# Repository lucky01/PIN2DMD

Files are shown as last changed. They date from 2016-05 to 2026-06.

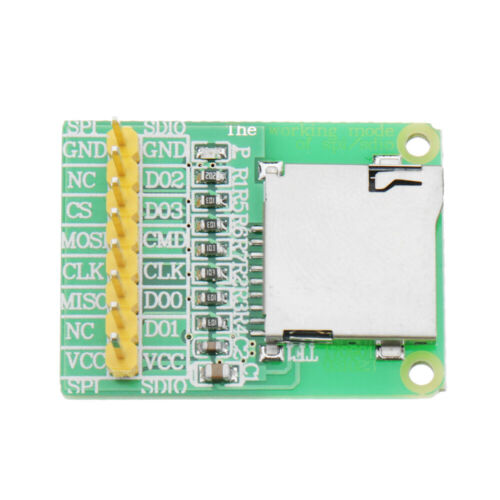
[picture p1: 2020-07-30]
hardware/V4 NUCLEO-144/chinese SD reader/sd_reader.jpg

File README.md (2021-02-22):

# PIN2DMD - a color LED dotmatrix controller for virtual and real pinballs

With the PIN2DMD project you get a full color LED DMD controller 
for real and virtual pinball machines.
The project was started by Lucky1 and shortly after that joined by Steve45 
as co-author. Version 1.X is free for DIY private NON COMMERCIAL use and released under 
a Creative Commons Attribution-NonCommercial- ShareAlike 4.0 International License.

http://creativecommons.org/licenses/by-nc-sa/4.0/

Due to copyright violations through commercial sales of our software the authors were forced to
change the project to allow access to the source code for contributors only with version 2.0.
Also a activation key which is bound to the hardware was introduced.
More Information how to obtain a key can be found in chapter 3 here https://pin2dmd.com/installation/ 

The latest binary can be found here 
https://github.com/lucky01/PIN2DMD/raw/master/firmware/latest/

Sorry for inconvinience, but is seems that the hunt for quick money eats the brain of the hunter.

More information can be found on https://pin2dmd.com/

It currently supports:

- WPC/WPC95 real pinball input
- Stern SAM real pinball input
- Stern Whitestar real pinball input
- Stern Spike real pinball input
- DataEast/Sega real pinball input
- Gottlieb real pinball input
- Capcom real pinball input
- AlvinG real pinball input
- Spooky real pinball input (with full color support from herg for AMH http://ledocd.com/amh_color/)
- Inder / SPinball real pinball input
- Sleic / Petaco real pinball input
- HomePin real pinball input
- Sega 192x64 using 64x64 1/32scan P2 Panels
- DataEast 128x16 real pinball input
- Mission Pinball Factory and P-ROC USB input
- Visual Pinball / PinMame USB input
- Future Pinball with DMD interceptor DLL
- Unit3d Pinball
- Ultra DMD support (Stephen)
- PinballX / XDMD support (Tom Speirs)
- Pinball fx2 support using dmdext from Freezy
- The Pinball Arcade support using dmdext from Freezy and NoEx
- Pinball Browser / SmartDMD color switching for full color Stern ROMS
- Frame colorization with PIN2DMD Editor by Steve for all pinball machines
- WCID Windows automated driver installation

The components cost approximately 120$
Here is a list of what you need:
 
#1. The Panels
The panels we use are sold for video walls and advertising signs. There are many 
sizes of panels available with different spacing between the LEDs. The ones 
that fit best into a pinball have 2.5mm spacing (also referred to as P2.5), 
which results in a 128×32 display of 320×76.8mm. This can be mounted into an 
existing DMD/speaker panel from a pinball cabinet. Currently the only place 
to buy these panels is from AliExpress. search for "RGB LED 64x64 p2.5 1/16" or 
"RGB LED 64x64 p2.5 1/16". You don´t find 128×32 panels, but you can buy two 
64×32 or one 64x64 panel which consists of two 64x32 panels which can be removed 
from the frame and connect side-by-side. Make sure that you end up with 2 x 1/16 
scan panels since these are the only one currently supported by PIN2DMD. 
The good thing is that they are seamless.

#2. The Controller

#2.1 The STM32 Nucleo board with PIN2DMD Shield or EVO boards

The panels use a 16 pin Hub75 interface to be connected to the next panel or to a 
controller. We use standard STM32 development boards like the Nucleo144-F429ZI or NUCLEO-F439ZI
which are available from multiple sources for about $20 or custom EVO boards.
The proceesor is based on a ARM Cortex processor architecture which is needed 
for the rapid bit-shifting of data to control the panels. We write the program in C/C++. 
The software is uploaded to the controller through USB port.
To connect the displays to the controller there is a HUB75 connector, which 
basically just connects the pins to the 16-pin ribbon cable that drives the displays. 
The board also has a 14pin connector which is used as input to get the data from a real machine. 
PCB layout examples can be found in the hardware directory. 

#3. The Power Supply
The RGB LED displays require 5vdc for power and if you want to run them
with full brightness they need a lot of current. A 10A power should be enough.
You need to connect that power supply up to both panels. The controller can 
either be supplied by USB or by an external 5V power source
 
#4. The Firmware
Installation is done using ST-Link interface

1) Download and install ST Link Utility: http://www.st.com/web/en/catalog/tools/PF258168
2) The latest binary can be found here https://github.com/lucky01/PIN2DMD/raw/master/firmware/latest/
3) Connect the STM32 board to the PC using a mini-USB cable (not the smaller microUSB cable). The board will light up and you should an STM32 STLink USB device connected in the Windows notification tray
4) Flash firmware: Target -> Program 
Choose PIN2DMD.BIN file from firmware/latest latest folder.

#5. The pin2dmd.exe tool
The tool is used to configure the controller und upload needed data for the pinball
used. It can either run in commandline mode or in GUI mode.

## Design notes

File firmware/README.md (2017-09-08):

# PIN2DMD

For information how to get a activation key for your device 
please visit http://www.pin2dmd.com

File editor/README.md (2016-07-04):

# PIN2DMD Editor by Steve

Can be used for editing frames and palettes and 
creating the needed palettes.dat file to upload
to pin2dmd using pin2dmd.exe tool with /b option.

Compiled version and and docs can be found here
http://pin2dmd.com/

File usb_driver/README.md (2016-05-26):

# PIN2DMD USB driver

The PIN2DMD is registered automatically in windows as a winusb device. 
For Visual PinMame etc please use Zadig Utility to change the drivertype 
to "libusb-win32". For Windows XP Version please go to http://zadig.akeo.ie/

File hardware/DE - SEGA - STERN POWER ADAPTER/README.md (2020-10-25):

# DATAEAST POWER ADAPTER BOARD

This are the PCB files for a power adapter which can be plugged in the powerdriver board of DE version 3 / Sega version 3 & Whitestar / Stern Whitestar & S.A.M.
machines. PCB design by Rene Venema

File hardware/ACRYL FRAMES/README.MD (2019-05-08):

Templates for acrylic mounting frames. Please check against your LED panels before ordering.

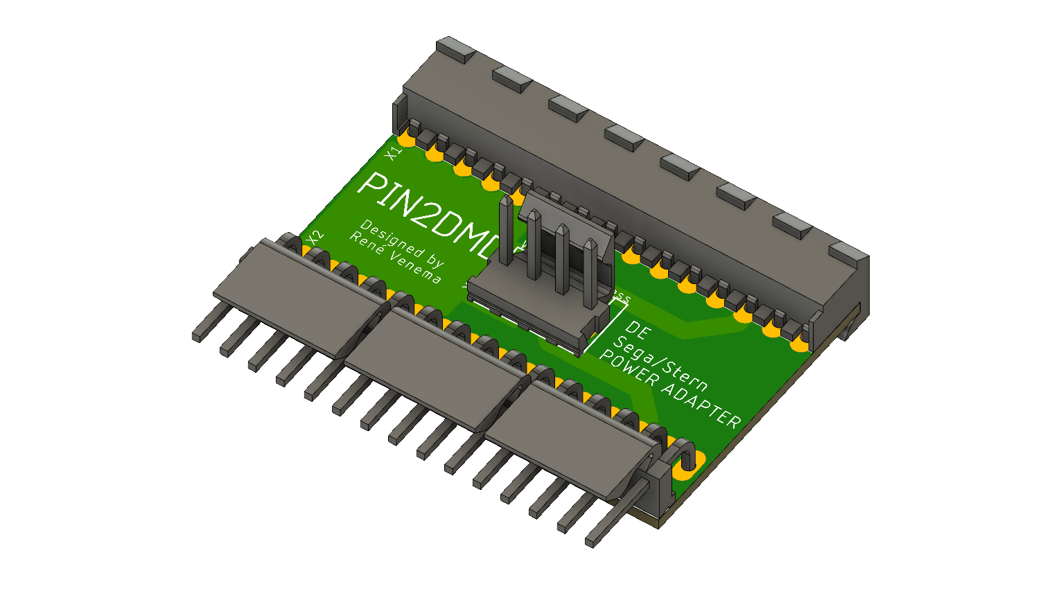
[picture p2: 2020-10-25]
hardware/DE - SEGA - STERN POWER ADAPTER/DataEastconverterv8.png

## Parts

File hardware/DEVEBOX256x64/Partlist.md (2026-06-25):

# PIN2DMD HD DEVEBOX HD Shield partlist

DEVEBOX STM32H743VIT6 Shield:

- 1 x DEVEBOX STM32H743VIT6
- 2 x Pinheader 2x22 pins female double row 2.54mm
- 1 x Pinheader 2x20 pins female double row 2.54mm (MMI)
- 3 x IC socket 20pin
- 8 x 47pf
- 1 x 1kOhm
- 2 x 100kOhm
- 2 x Resistor network 4R 8-pin 220Ohm
- 1 x 74LS123 DIP
- 3 x 74HCT245N DIP
- 2 x IC socket 16pin
- 1 x IDC socket 2x7 pins male 2.54mm
- 2 x IDC socket 2x8 pins male 2.54mm
- 2 x Tactile push button 6x6x10mm 4pin DIP
- 8 x 100nF

POWER:

- 1 x XL4015 module or XL4005 module set to 4.8V 
- 1 x Screw terminal block 2pin 5mm (8-36VDC in)
- 1 x CH3.96 china or Molex 4P KK3.96 model: 09652048

LED:

- 1 x LED 3mm green
- 1 x 470 Ohm
- 1 x LED 3mm blue
- 1 x LED 3mm orange
- 1 x LED 3mm red
- 3 x 680 Ohm

RS232:

- 1 x MAX232 DIP
- 1 x Pinheader 1x3 pins male 2.54mm RS232
- 1 x Pinheader 1x2 pins male 2.54mm 3V3_TTL
- 4 x 1uF 4x7mm radial

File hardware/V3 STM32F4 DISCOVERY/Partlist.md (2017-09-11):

#PIN2DMD shield partlist

#V3 STM32F407-DISCOVERY Shield

2 x pinheader 2x25 pins female double row 2.54mm
1 x TINY RTC module
1 x ESP-12 or ESP01 wifi module
1 x Micro SD-card reader module
1 x DHT11

2 x IC socket 16pin
1 x 74LS123 DIP
1 x MAX232 DIP

1 x IDC socket 2x7 pins male 2.54mm
1 x IDC socket 2x8 pins male 2.54mm
3 x pinheader 1x3 pins male 2.54mm

7 x 47pf
4 x 1uF 4x7mm radial
4 x 100nF
1 x 1kOhm
1 x 10kOhm
2 x 100kOhm
1 x 470 Ohm
2 x resistor network 3R 6-pin 220Ohm

1 x LED 3mm
1 x screw terminal block 2pin 5mm
1 x DC power jack 3 legs PCB mount
2 x tactile push button 6x6x10mm 4pin DIP

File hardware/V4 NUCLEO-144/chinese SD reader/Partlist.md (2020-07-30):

#PIN2DMD shield partlist

#V4 Nucleo-144 Shield

2 x pinheader 2x36 pins female double row 2.54mm
1 x china 3.5v/5v micro SD card module SDIO/SPI

2 x IC socket 16pin
1 x 74LS123 DIP
1 x MAX232 DIP

1 x elevated socket 2x8 female 2.54mm
1 x IDC socket 2x7 pins male 2.54mm
1 x IDC socket 2x8 pins male 2.54mm
1 x pinheader 1x3 pins male 2.54mm RS232

8 x 47pf
4 x 1uF 4x7mm radial
3 x 100nF
1 x 1kOhm
1 x 10kOhm
2 x 100kOhm
1 x 470 Ohm
2 x resistor network 4R 8-pin 220Ohm

1 x LED 3mm
1 x screw terminal block 2pin 5mm
2 x tactile push button 6x6x10mm 4pin DIP

optional components

1 x ESP-12
1 x DHT11
1 x HX1838
1 x CR2032 battery holder
1 x pinheader 1x3 pins male 2.54mm PIR

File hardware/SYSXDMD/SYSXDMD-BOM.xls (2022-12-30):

SYSXDMD BOM
NO | Code | Part Number | Manufacturer | Description | Designator | Quantity | Process | Note
1 |  | 430152043826 | Wuerth Electronics | Switch 6x6x5 mm SMD, 4 pins | BTN1,BTN2,DFU,RESET | 4 | SMT | use China manufacturer
2 |  | TAJA105K016RNJ | AVX | Tantalum capacitor, 1uF, 16V, A3216 | C1,C13,C15 | 3 | SMT | use China manufacturer
3 |  | CL21B105KOFNNNE | Samsung | Capacitance, 1uF, 16V, 0805 | C30,C31,C32,C33 | 4 | SMT | use China manufacturer
4 |  | TAJB225K020RNJ | AVX | Tantalum capacitor, 2u2, 20V, 1411 | C11 | 1 | SMT | use China manufacturer
5 |  | 160R15W104KV4T | JOHANSON | Capacitance, 100n, 16V, 0805 | C2,C7,C10,C12,C14,C16,C23,C24, C37 | 13 | SMT | use China manufacturer
6 |  | CL21B225KOFNNNE | SAMSUNG | Capacitance, 2u2, 16V, 0805 | C3,C4 | 2 | SMT | use China manufacturer
7 |  | 500R15N220JV4T | JOHANSON | Capacitance, 22p, 50V, 0805 | C5,C6 | 2 | SMT | use China manufacturer
8 |  | CL31B225KBHVPNE | SAMSUNG | Capacitance, 2u2, 50V, 1206 | C9,C22,C25 | 3 | SMT | use China manufacturer
9 |  | TS2940CP33 | Taiwan Semi Corp | TS2940CP33 | IC3 | 1 | SMT
10 |  | PPPC072LFBN-RC | SULLINS | 2.54mm pitch 2x7 pin double row pin header | DMD | 1 | THT
11 |  | PPPC132LFBN-RC | SULLINS | 2.54mm pitch 2x13 pin double row pin header | 1J22 | 1 | THT
12 |  | FCM1608KF-601T03 | TAITECH | FCM1608KF-601T03 | L1 | 1 | SMT
13 |  | LTST-C171KRKT | LITE-ON | LED, 0805, red | LD1 | 1 | SMT
14 |  | FC4SDCBMF8.0-T1 | FOX | Crystal 8MHz | Q1 | 1 | SMT | use China manufacturer
15 |  | CR0805-FX-22R0GLF | BOURNS | Resistance, 0805, 22R | R18,R19 | 2 | SMT
16 |  | CR0805-J/-000ELF | BOURNS | Resistance, 0805, 0R | R2,R6,R33,D1 | 3 | SMT
17 |  | CR0805-FX-1001ELF | BOURNS | Resistance, 0805, 1k | R20 | 1 | SMT
18 |  | CR0805-FX-6800ELF | BOURNS | Resistance, 0805, 680 | R29 | 3 | SMT
19 |  | CR0805-FX-1003ELF | BOURNS | Resistance, 0805, 100k | R1,R3,R5,R9 | 4 | SMT
20 |  | CR0805-FX-47R0GLF | BOURNS | Resistance, 0805, 47R | R4, R8 | 2 | SMT
21 |  | CR0805-FX-1002ELF | BOURNS | Resistance, 0805, 10k | R17 | 7 | SMT
22 |  | CR0805-FX-2200ELF | BOURNS | Resistance, 0805, 220 | R7 | 8 | SMT
23 |  | 54819-0519 | MOLEX | Mini-USB | ST1 | 1 | THT
24 |  | STM32F407VGT6 / APM32F407VGT6 | STM / GEEHY | STM32F407VET6 / APM32F407VGT6 | STM32 | 1 | SMT
25 |  | MTP125-1104S1 | Minitron | Pinheader 1X4 2.54mm pitch | SWD | 1 | THT | use China manufacturer
26 |  | CH3.96-9A | Boom Precision Elec | 9pin 3.96mm pitch male connector | 1J1,1J2 | 1 | THT | use China manufacturer
27 |  | CH3.96-12A | Boom Precision Elec | 12pin 3.96mm pitch male connector | !J3 | 1 | THT | use China manufacturer
28 |  | CH3.96-6A | Boom Precision Elec | 6pin 3.96mm pitch male connector | PWR | 1 | THT | use China manufacturer

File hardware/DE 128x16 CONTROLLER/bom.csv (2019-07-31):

C1 | 100uF/15V
C3 | 47pF
C10, C11, C12, C13, C14, C15, C16, C17, C18, C19, C20, C21 | 100nF
J1 | 2.54m male pinheader 2 x 13 pin
DISPLAY | IDC 2.54mm 2x7 pin 14 pin straight male shrouded header
R5, R6, R7, R8, R9, R10, R11, R33, R88 | 100k
R13, R14 | 10k
R18 | 2K
R89_1/4W | 15K
R90_1/4W | 4.7K
U1 | 74HC374N | DIL20
U2 | 74HC00N | DIL14
U3 | 74HC04N | DIL14
U4 | 74HC259N | DIL16
U5 | 7407N | DIL14
U6 | 74HC139N | DIL16
U7 | 6264 | DIL28-6
U8 | DIL32 precision IC socket
U9 | 4020N | DIL16
U10 | 74HC153N | DIL16
U11 | 74HC74N | DIL14
U12 | Z80 CPU 4MHZ Z847004PSC | DIL40
X2 | VH3.96 4PIN
Y1 | 8Mhz | HC49U70

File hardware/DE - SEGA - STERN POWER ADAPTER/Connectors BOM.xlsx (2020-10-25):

Discription | QTY | MPN | MAN
5p KK396 angled female | 3 | 09-48-2051 | Molex
5p KK396 angled male | 3 | 26-60-5050 | Molex
4p KK396 straight male | 1 | 09-65-2048 | Molex

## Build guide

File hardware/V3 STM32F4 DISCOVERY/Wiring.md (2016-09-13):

Wiring
===
HUB75 pins
---

| 1 | 2 |
| --- | --- |
| R1 |  G1 |
| B1 | GND |
| R2 | G2 |
| B2 | E |
| A | B |
| C | D |
| CLK | STB |
| OE | GND |

STM32F4Discovery pins

- pin STM32 Boot0 and ESP GPIO15 to first DIP 3,3V/GND
- pin VBAT to Battery + (CR2032 or CR1220)
- pin NRST to ESP GPIO2 to reset STM from ESP
- pin PA9 to 5V pin to power the STM32 from user USB port

GPIO A
- 0 - Latch / Button Blue
- 1 - RowClock
- 2 - RowData
- 3 - OE
- 4 - ESP SPI CS (GPIO15)
- 5 - CLK
- 6 - DETECT DMD ST32 (not used on STM32F4 Shield)
- 7 - DATA
- 8 - USB_OTG_SOF (not used)
- 9 - USB_OTG_VBUS
- 10 - USB_OTG_ID
- 11 - USB_OTG_DM
- 12 - USB_OTG_DP
- 13 - SWDIO
- 14 - SWCLK
- 15 - JTDI

GPIO B
- 3 - ESP SPI SCK (GPIO14)
- 4 - ESP SPI MISO (GPIO12)
- 5 - ESP SPI MOSI (GPIO13)
- 6 - USART1 TX to Max232
- 7 - USART1 RX to Max232
- 8 - RTC_SCL (ESP WIFI GPIO0 on DMDST32)
- 9 - RTC_SDA (ESP WIFI RESET on DMDST32)
- 10 - USART3 TX WIFI
- 11 - USART3 RX WIFI
- 12 - SD CS
- 13 - SD SCK
- 14 - SD DO
- 15 - SD DI

GPIO C
- 6 - RGB OE
- 14 - RTC OSC (Go-DMD) 32,768 kHz 2 x 6,8pF
- 15 - RTC OSC (Go-DMD)

GPIO D
- 0 - R1
- 1 - G1
- 2 - B1
- 3 - R2
- 4 - G2
- 5 - B2
- 6 - RGB Clock
- 12 - LED GREEN
- 13 - LED ORANGE
- 14 - LED RED
- 15 - LED BLUE

GPIO E
- 0 - ESP WIFI GPIO0
- 1 - ESP WIFI RESET
- 2 - RGB Row A
- 3 - RGB Row B
- 4 - RGB Row C
- 5 - RGB Row D
- 6 - RGB Latch
- 7 - Sensor 1 (Go-DMD) (DHT11)
- 8 - Sensor 2 (Go-DMD) (PIR)
- 9 - Sensor 3 (Go-DMD) (IR)
- 10 - Button 1
- 11 - Button 2
- 12 - Second DIP (not used on STM32F4 Shield)
- 13 - RGB Row E or GND with Jumper for 1/32 scan

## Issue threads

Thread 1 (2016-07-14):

Display hangs during playback

comicalman, 2016-07-14:
Created just 4 keyframes (frameseqs) and saved my project.
When I try it during playtesting, the display stops - right at my first replacement frame and requires me to restart the display altogether.
I did renamed palettes.dat to pin2dmd.pal.  Was there also a naming convention change for pin2dmd.fsq?

see this post for the project files:
http://vpuniverse.com/forums/topic/2268-pin2dmd-editor/page-12#entry29878

lucky01, 2016-07-14:
Which version of pin2dmd are you running. The zip file in your posting contained a dozen of projects. Please only attach the project your problem is referring to (XML and dump)

comicalman, 2016-07-14:
I am using pin2dmd v 2.29
See:XFiles_V4m.xml
The 'other' files you refer to are not projects, but rather palettes.  Not sure, but you might need them to see what is going with the project.

lucky01, 2016-07-18:
I had a look at your project and it seems that it is caused by the pcap file that you use as a dump for your project. Currently only pinmame dumps are fully supported by the editor and the firmware.
Pcap files can only be used for palette switching not for frame replacement or addcolor. As a workaround use pinmame dumps to generate framesequences (fsq).

Closed 2016-07-18.

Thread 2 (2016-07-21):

Using vpinmame as source, Pin2dmd Hangs during playback

comicalman, 2016-07-21:
I have created another test project.  This time, I used a dump from vpinmame directly.
When I try it, the display hangs - right at my first replacement frame and requires me to restart the display altogether.

see the project- named Xfiles_v4m1.xml located at this post:
http://vpuniverse.com/forums/topic/2268-pin2dmd-editor/?p=30042

lucky01, 2016-07-21:
I forwarded this issue to
https://github.com/sker65/
who is responsible for the editor

Closed 2016-07-21.

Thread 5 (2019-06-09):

PIN2DMD does not recognize

tcharlie84, 2019-06-09:
Hi,

I recently acquired some PIN2DMD cards through your project and received them recently from the indicated company that produced them for me.

I performed the welds on the back of the pcbs with the display connectors and plugged the ribon cable between the two displays.

Now I'm trying to install the firmware but I'm not succeeding.

I do not get any images on the displays, it only gets black screen.

The mini USB cable when connecting to the EVO card I get no connection signal in Windows 10 and it seems that I do not get any light on the EVO data board, except for a single power light,
5V.

In device manager the PIN2DMD is not recognized, and there is no notification when plugging or unplugging the mini USB cable.

I tried the installation via ST-LINK Utility and also through DfuseDemo, but the two programs do not recognize any device.

I also tried to click on the DFU button that has on the board to try some recognition but no signal.

In the .exe zaddig program I also can not find the device because I do not seem to recognize.

I have attached on the back of my Evo PIN2DMD only the micro USB, formatted USB card and the 5V power supply.

Attached follows a google drive of the images of how the connections are.

What can I be doing wrong?

Please, your help is very important to me!

Cheers!

https://drive.google.com/open?id=1IWZ0EjIJ1ze4cFkS0NusCTcBQm2tkYc5

lucky01, 2019-08-14:
Hold down the DFU button and press/release the reset button. DFU button is only checked during startup of the processor. Installation procedure is described here https://pin2dmd.com/installation/

Closed 2019-08-14.

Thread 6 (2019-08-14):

STM32F4 Discovery v3 Schematic question

ahuxtable, 2019-08-14:
Hi, First of all - Great work on the development of this platform. I built my VP cabinet about 6 years ago when a 'real' DMD was prohibitively expensive so I went with an LCD at the time.  Now I am rebuilding my cab with some new toys so looking at making one of these.

However, I am going over the schematic for the STM32f4 discovery and I am confused as to why it needs the Mini RTC as well as using the internal RTC? Or the external RTC is just used to set the internal RTC at power up? Or for that matter, why it needs an RTC at all?

Also, its not clear to me what the function of all of the external components are for such as the MAX232, ESP8266, IR and PIR - I know what all these devices do, just don't understand what function they provide for the DMD and if omitting them will prevent the base operation of the DMD.  Have I overlooked some documentation somewhere?

I can see the reason for the SD card but if it is only used for updates and registration (and we have alternative methods for these functions already), can it be omitted too?

lucky01, 2019-08-14:
All the components you named can be omitted if you only want to use it for vpin.
RTC,PIC,WIFI,IR are for use with https://go-dmd.de/ . SD, LS123, MAX232 are for use with real pinball machines. I would install the buttons to have access the onscreen menu.

ahuxtable, 2019-08-14:
Awesome, thanks for clearing that up. Makes it extremely simple now!

Just confirming, that also means there is no need for external crystal and caps for the internal RTC?

lucky01, 2019-08-14:
No ! RTC is not used with pin2dmd

vhlh310177, 2020-05-08:
Hi. Excellent work. I have a question?. Sorry for my bad inglish. Its necesary use the shield with the STM32 Nucleo-144 STM32F429ZI, i only use this for a virtual pinball.

ahuxtable, 2020-05-08:
It's not, it just makes it a lot easier. I used a 'DiyMore' Stm32f4 board which is a minimalist board and a protoboard. It works fine but is not for someone without good experience with electronics and reading schematics. Mine just has connection to the led board 16 pim connector and 2 buttons for the menu.

lucky01, 2020-05-08:
> It's not, it just makes it a lot easier. I used a 'DiyMore' Stm32f4 board which is a minimalist board and a protoboard. It works fine but is not for someone without good experience with electronics and reading schematics. Mine just has connection to the led board 16 pim connector and 2 buttons for the menu.

I have one of those boards here and although they say they use the STM32F407VGT6 (1MB Flash) a STM32F407VET6 is installed (512kb Flash). We will most likely use that additional 512kb flash memory in the future and that will break compatibility to the VET6 based boards. To make support and code maintainance as easy as possible for me, I will only make sure that my code runs on the hardware used by my designs (Disco, Nucleo429 and EVO boards). Anything else is on your own risk.

ahuxtable, 2020-05-08:
I totally understand that position, it is at your own risk of course if using a non-standard board. You cant be expected to support homebrew versions.

I have 2 of the DiyMore boards and both have vgt6 chips, not vet6. Or at least that is what is written on the chip.

Closed 2019-08-14.

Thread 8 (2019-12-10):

EVO 128x32 not recogized by USB

azwakeboarder, 2019-12-10:
I just finished the EVO 128x32 build with the files provided, Thank you for your effort. I was able to flash the firmware using the st-link usb to header programming tool. The pin2dmd now turns on the shows the PIN2DMD banner. I requested the key off the number displayed. I have received the key but the Windows 10 machine does not recognize the device when using the mini-USB plug. I have tried zadig-2.4 utility and it does not show up as a usb serial device. Have any suggestions?

lucky01, 2019-12-10:
PIN2DMD does not register as a serial device. It should autoregister as a generic winusb device under windows 10. No need to change the drivers with zadig unless you want to use old programs that rely on libusb32. If you hold down the dfu button during boot or reset it should register as a dfu device asking for drivers. In any other case you have either a software or USB problem.

Closed 2019-12-10.

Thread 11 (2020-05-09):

192x64 Ghosting

Bandicoot37, 2020-05-09:
hello
 i'm using a pin2dmd with last firmware XL and i got some strange ghosting
https://streamable.com/bi3g6u

i try the 2.68 firmware and realy better but sometime got a problem look at the "s" at the end of this video and "ins" of insert coin ghost a little
https://streamable.com/ffy2ph
thanks if you can help me :) :)

lucky01, 2020-06-22:
fixed in v3.13

Closed 2020-06-22.

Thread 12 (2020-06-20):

DLL Versioning

skyblaster, 2020-06-20:
Would it be possible to add additional properties to your dmddevice DLLs in an effort to get it to play nice with PinballY from @mjrgh?
http://mjrnet.org/pinscape/PinballY.php#dmddeviceDLL

Currently seeing the following in PinballY:
```
+ retrieving file version info for DLL, to check for special handling
++ DLL version info not available; we must assume this is an old version with known bugs, so some
   features will be disabled.  Please update your DmdDevice.dll to a current version.
```

lucky01, 2020-06-22:
I added a version string to the latest dmddevice.dll.

Closed 2020-06-22.

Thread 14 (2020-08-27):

Idea to help diagnose SD Card file read problem

madnat, 2020-08-27:
Some users report a SD card is not being read by the PIN2DMD display.  Sometimes this is true, sometimes it is due to bad file names on the SD card.

Could a menu option be added to list current files loaded by the display, and list files found on the SD card?

lucky01, 2020-08-27:
I see no real usecase for such a menu option. The function of the SD reader can easily be tested by inserting a blank sd card and initiating a config save which should create a pin2dmd.dat on the SD.

madnat, 2020-08-27:
Many real Pinball users are not PC savvy,  dont have multiple SD cards, and therefore are tricky to help.

lucky01, 2020-08-27:
If they are are not PC savvy, how do they copy the colorization they want to use to the SD card ?

lucky01, 2020-08-27:
I assume you test the function of the SD reader before you ship the boards.
Adding a function like listing the files on the SD is not somthing you add in a couple of minutes.
What I could add in a future version is something like create, write and read and delete a dummy file
but currently I have different projects.

madnat, 2020-08-27:
Many options for a non PC savvy pinball owner get a SD card installed when fitting a PIN2DMD display,

1.  Have a helpful community members (like me) organise the SD card with files from the author,
2. have a family member or friend help the pinball owner get the display installed,
3. pay a technitian to install a colour DMD into their real pinball

lucky01, 2020-08-27:
All 3 options include a person who is able to check the function as described above.

madnat, 2020-08-27:
There is no expectation that this feature would be added immediately.  Simply feedback on how we can make the product easier to use for non-technical people.  If it isnt something that can be done - then no issue.  Simply trying to help people who have the display - and have trouble getting it going very occassionally.

madnat, 2020-08-27:
On the test point - there is no exitsing feature to test if the display is reading the SD card without fitting the display to the real pinball machine - that I'm aware of.  That would help solve the problem for scenario 1 (help from an author or community member create a SD card for the real pinball owner)

lucky01, 2020-08-27:
You can test wether the SD is working properly by initiating a save config - remove the SD card - change a setting like devicemode, palette, brightness and save config. After you reinsert the SD card and reboot your last config change should be overwritten by the last version on the SD card.

lucky01, 2020-08-27:
> .PAL read Yes/No and .FSQ read YES/NO would be easier to implement - and serve the same need?

I consider implementing something like this in a future version.

Closed 2020-08-27.

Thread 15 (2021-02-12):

Feature Request: Timecode Overlay on Pin2dmd screen from Editor

Happymealtm, 2021-02-12:
Add in "debug" menu to the Pin2dmd firmware with a "timecode overlay" feature. Enabling this option on the Pin2dmd device would add a timecode that is seen in the editor window down the bottom to be overlayed onto the display and would be the same code as shown in the editor. Give the user a few positions to overlay if they are working on a bug in a certain area they can move the timecode so it will not cover the screen. (Left right etc) The timecode will not be captured in the dump on the image it will just be for recording off the screen where if the user can't overlay a timecode using their own device it will come in handy. It will also make it easier to sync the recording if you don't hit the start on both devices at the same time or if there is a delay or for people who can't sync it up easily.

For Data East x16 it could be put inside the blank areas to be used with back glass off.

Great for quickly troubleshooting if you have a large dump file and need to get to areas quickly.

This may be more for the Firmware than the editor but they would have to sync up anyway so it would be need to be linked to both FW and editor to make sure it will work.

lucky01, 2021-02-12:
There is no dump recording function in the editor, so I don´t know what you are talking about. Also adding information to the display during operation will add a additional delay in frame processing, which will cause frame drops in the dump. That is also the reason why it is recommended not to have a colorization active during a creation of a dump using the pin2dmd.exe tool. Sorry I have to reject that feature request for many technical reasons.

Closed 2021-02-12.

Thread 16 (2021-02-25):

Need to reset on boot with latest Nucleo STM firmware

arnoz26, 2021-02-25:
Hello there
I've upgraded my Nucleo f429 firmware to latest with stm utility (2-37-27), then device did not boot properly, i need to reset it to view it on windows.
Need to downgrade to 2-32.M22 to have my pin2dmd work properly.

Any info on that issue ?

lucky01, 2021-02-25:
http://vpuniverse.com/forums/topic/4582-bug-in-st-link-firmware-v2j36m26/

This is not a pin2dmd bug but a bug in the ST-Link firmware. There is nothing I can do about it.

rgiot, 2021-02-26:
Sorry to comment this closed issue; but is it possible to indicate that in the documentation ? On the installation page, the sentence "!! Note :If your device does not start the PIN2DMD firmware when powered up your Discovery or Nucleo boards may need a ST-Link firmware update from here" is misleading.

Bests

Closed 2021-02-25.

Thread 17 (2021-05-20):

Clarify license

usul27, 2021-05-20:
According to the license, this is a non-commercial license. However, many dealers offer these displays. My understanding is that this is now accepted as there is a paid licence for the software. Is this correct? In this case, the license for this project should be more open.

lucky01, 2021-05-20:
Everbody can download the pcb design and produce pin2dmd compatible hardware to sell it commercially without activation.
To sell preactivated devices dealers have the possibility to donate 20 euro per device in batches of minimum 5 devices
directly to one of the chariity organizations we support with the pin2dmd project donations. That way the dealer will receive a tax deductable donation receipt which is equivalent to a invoice. I will generate the keys for free if you send me a copy of the transaction together with the numbers. It is NOT allowed to use private activation keys to sell preactivated devices. The charity organizations dealer donations go to are chosen individually. Please contact us if you want to go that way and we give you the contact details of the charity organization you have to donate to. Because this is a individual exception which needs to be granted through contacting us, there is no need to change the general license.

usul27, 2021-05-20:
No plans for this, but the license in the repo does not reflect this correctly:
https://github.com/lucky01/PIN2DMD/blob/master/License.md

I recommend to update the license to reflex the current state.

lucky01, 2021-05-20:
Which license would you recommend ?

usul27, 2021-05-20:
As your just saying, everybody can use the hardware design, why not using a simple BSD license that basically says "everybody can do everything"?
If you want it more restricted, CC BY or CC BY-SA might be a better choice.

lucky01, 2021-05-20:
As the project owner is always allowed to hange the license and make exceptions I prefer to have a more restricted license and make individual exceptions instead of using a open license and having dealers misinterpret it to their advantage.

lucky01, 2021-05-20:
That is exactly what I wanted. Maybe I should have said "Everybody who asks for permission to produce our hardware and sell it will get the permission."

usul27, 2021-05-20:
I still find it a bit strange that everybody gets the permission even though the license explicitly forbids it, but feel free to do it as you like. In my own business I would not sell these with this kind of license (just FYI: I'm running an electronics business, but it has nothing to do with Pinball).

vtrucco, 2023-09-26:
> That is exactly what I wanted. Maybe I should have said "Everybody who asks for permission to produce our hardware and sell it will get the permission."

I would like to resell those boards. How can I contact you?

Closed 2021-05-20.

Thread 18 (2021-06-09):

Firmware fails to run - stuck in loop

VaderMester, 2021-06-09:
Hi,

I ran into a problem on my NUCLEO-144 board, that for some reason it's not running at all.
I'm running NUCLEO-144 PIN2DMD.bin (the normal one).
Latest version as of today.
I looked into what's happening inside the CPU, and the CPU is stuck in a loop that's between 0x80081b0 and 0x80081C6
It's very early in the boot process, but I have no idea how to solve it.
Full tracking is here, my ST-LINK picks at 0x80081A0.
https://onlinedisassembler.com/odaweb/lp9MV2EX/0
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

And yes, I tried reflasing a few times, didn't fix the problem.
Can you help me what to look at? It must be some kinda HW issue I guess, that is being checked?

Thanks in advance
Vader(Ben)

lucky01, 2021-06-09:
Never had this issue. This may be of help
https://vpuniverse.com/forums/topic/4582-bug-in-st-link-firmware-v2j36m26/?tab=comments#comment-48827
Please ask all support questions in this forum.
The biggest userbase is there

VaderMester, 2021-06-10:
Thanks. Unfortunatelly, none of the suggestions helped me.

I bought this Nucleo used just to make this work, so I assume there are HW issues.
You can help me find it.

Further findings:
The CPU freezes at 0x80081FE (PC displays 0x8008200).
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

I managed to read out the registers, and it seems that clocks are not configured at this stage so I get stuck pretty early.
If I reset the Core only, I get further, clock is configured and peripherals also somewhat gets configured, but it's stuck again.
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

Are you using any hardware feature on the Nucleo-144 that can cause problems, like the 32kHz clock, and other stuff?

For the following I assume you are familiar with how compilers work:
Can you please check your .ld linker script file and see what functions are called around those locations and what they do? Just briefly, I don't need details, just crumbs to see which hardware and signals should I check going along, before I have to wait for a new MCU and swap it, to see if it fixes it. I really want to investigate this.
Unfortunattely it's somewhat urgent to make it work, and I want to get out all the options before I start replacing stuff on this board.

Thanks for the help in advance.

lucky01, 2021-06-10:
Sorry no time to help you with that. Maybe you can generate my own code to see which problem the CPU has.
From my point of view not worth the effort to save 25$.

lucky01, 2021-06-10:
I guess the RAM of the CPU is defective.

VaderMester, 2021-06-11:
Thanks for all the answers. Just a very last question: Does your app uses the 32k Crystal on the Nucleo? I just found that it is missing (X2 on the Nucleo-144). The previous owner confirmed he had removed it as a donor. Does PIN2DMD need it or not?

lucky01, 2021-06-11:
No it does not use the clock crystal.

VaderMester, 2021-06-12:
Unfortunatelly problems doesn't end here.
I managed to get a spare MCU, I replaced it.

It produces the same issue, which means it's no longer a hardware issue, rather something else.
Debugging more, I find that the programs goes to a Hard-Fault.
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

This would explain why the CPU freezes.

If you check the log above, the address 0x8010488 is empty. There is data only in address before it.
I verified it in latest binary and it is also empty there so the Binary is properly loaded into the MCU
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

I'm beggining to think it's some small software issue, but have no idea what can that be.

lucky01, 2021-06-12:
Sorry ! No time to help you with that. Since I have received several activation requests for my image I don´t think that there is a problem with it. Please continue in the forum.

Closed 2021-06-09.

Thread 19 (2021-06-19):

Few 5V and GND routing issues in the new 256x64 EVO design

Stumblor, 2021-06-19:
Could just be my conversion of the eagle file, but just thought I would raise in case these haven't been picked up already.

5v:

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

GND:

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

GND:

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

lucky01, 2021-06-19:
You are right with the missing 5V trace but the GND does not show up in my version. I uploaded a updated version

Closed 2021-06-19.

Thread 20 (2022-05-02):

What's dmdext.dll?

freezy, 2022-05-02:
Hey,

It looks like you're bundling dmdext's `DmdDevice.dll` as `DmdExt.dll` in your dmddevice.zip [here](https://github.com/lucky01/PIN2DMD/tree/master/integration/pinmame). I suppose that's a proxy that uses your own dmddevice implementation for PIN2DMD and falls back to dmdext for other outputs like LCDs?

Since dmdext also supports PIN2DMD, what's the reason for this? It's a bit confusing and looks like a GPL violation to me.

lucky01, 2022-05-02:
GPL violation ? The source of dmdext.dll is here https://github.com/lucky01/dmd-extensions/tree/dmdext.dll
I use the colorization code in my dll and pass the frames as RGB24 to your DLL.
It is all described here https://vpuniverse.com/forums/topic/7191-new-version-pin2dmd-dmddevicedll-with-dmdext-as-plugin/

pinballpower, 2022-05-02:
As the colorisation code is not GPL licensed, you're not allowed to link it into GPL 2.0 code.

freezy, 2022-05-02:
Thanks for the link, I just came back from holidays and didn't catch up with everything at the forums yet.

For the GPL, as @pinballpower said

lucky01, 2022-05-02:
My dll does not depend on the dmdext.dll . It also works without it, with the limitation to pin2dmd devices only. I pass the colorized frames to GPL 2.0 code just like pinmame does, which is also distributed with freezy and not licensed under GPL. Btw the dmddevice.dll interface API freezy uses to connect to pinmame was contributed to the pinmame code by myself. I just added dmdext.dll for the convience of desktop users which use a virtual display. I could also distribute it seperately if you feel better then.  Additionally there are two different opinions about this :

Does the use of GPL'ed DLLs f in your program need you to release your program under GPL too?

There seem to be two different strands of opinion. The [FSF](http://www.fsf.org/) holds that dynamic linking creates a derivative work, and so any program designed to run with a GPL-ed DLL, must be GPL itself; see http://www.fsf.org/licenses/gpl-faq.html. The only exception they make is for DLL's that come with the compiler and the kernel, such as the MS VC run-time DLL's; see http://www.fsf.org/licenses/gpl-faq.html#WindowsRuntimeAndGPL. On the other hand some OpenSource lawyers hold that dynamically linking does not make your program GPL; see http://www.nusphere.com/products/library/gpl_0401openmag.pdf and the discussion in http://www.linuxjournal.com/article.php?sid=6366. There is no doubt that programs that link dynamically to DLL's from libraries with the [LGPL](http://www.gnu.org/copyleft/lesser.html) or with the GPL with [special provisions](http://www.gnu.org/licenses/gpl-faq.html#TOCLinkingOverControlledInterface), are GPL free if you decide so.

freezy, 2022-05-03:
Both your URLs point to 404s.

I don't think it's relevant whether the commercial software works without the GPL software or not. It's the fact that you *distribute* it along with it.

Not being able to be linked to commercial software is pretty much the point of the GPL. Otherwise everybody would just wrap GPL code into an open sourced wrapper and be done with it.

lucky01, 2022-05-03:
Like I said, the same DLL is distributed with pinMame which is also not GPLv2

The coloring code in Freezy is based on the sources I provided you with the email topic "Top Secret" so IMHO your work should never have been published under GPLv2. But it is like it is now.

Here is a working link to the articles

https://web.archive.org/web/20060618213144/http://www.nusphere.com/products/library/gpl_0401openmag.pdf

https://web.archive.org/web/20061103081641/http://www.linuxjournal.com/article/6366

freezy, 2022-05-03:
1. It's not distributed with PinMAME, it's part of the all-in-one installer of VPX, which is another project, and that doesn't give you, or anyone else, any legitimization.
2. You always knew in advance that dmdext was GPL, and that the coloring port would be distributed as such. Claiming it "should never have been published" is dishonest, and frankly disappointing.
3. It's not about passing data or derivative work. It's about shipping GPL code along with commercial software.

lucky01, 2022-05-03:
1. Of course it is no legitimization. I´m just wondering how this O.K. for your while you are complalning here.
2. As far as I remember one of your personal motivation in those days were to make the colorizations work on your private pindmdV3 from VirtuaPin.
3.  How is the zip file and the software in it commercial in any kind ? The sole purpose of this package is to give the vpin users with virtual dmd, pin2dmd  or even pindmdV3 access to the latest colorization files.

freezy, 2022-05-03:
1. Then don't sell it as an argument. It should be clear by now why I'm bringing it up here and not for the installer.
2. Sure. Mine and countless others. Not sure however why you're bringing up *my* motives when we were talking about *yours* (i.e. why you would even contact me to port your coloring code into a GPL software, if you didn't want the port to be GPL).
3. Replace "commercial" with "non-GPL", it applies all the same.

lucky01, 2022-10-11:
GPL violation ? Sources are here
https://github.com/lucky01/dmd-extensions/tree/dmdext.dll

It uses my own colorization code and forwards the data as rgb24 to all devices supported by dmdext.dll.

See https://vpuniverse.com/forums/topic/7191-new-version-pin2dmd-dmddevicedll-with-dmdext-as-plugin/

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

Closed 2022-05-02.

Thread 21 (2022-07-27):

Stats engine based on PIN2DMD - advice sought

xaviershay, 2022-07-27:
Hello!

I'm planning a mod that can live detect the current score and events on a machine and then feed into a stats engine. I was thinking PIN2DMD could be a decent base for such a project - reading/analyzing/masking DMD matrix state is basically what we've done with other games.

We have a similar spirited project for Mario Kart 8 Deluxe, which uses/analyzes the HDMI feed (via a splitter), to give you a feel for the type of thing I'm thinking about: https://github.com/ferocia/kartalytics
I was thinking we could maybe run a similar "split" off the ribbon cable going to the DMD on our Demolition Man and into a similar/same controller to what PIN2DMD uses, but modify the firmware to output the display matrix via USB or ethernet where we can pick it up on another device and do the analysis.

Would love any thoughts or advice you might have: do you think this approach could work? What documentation/sources did you find useful in developing PIN2DMD?

Thank you! 🙏

lucky01, 2022-07-27:
Basically what you are looking for is the dump function Pin2dmd has implemented already. It sends out the frames it receives from the pinball machine through USB . Let me know if that is interesting for you. I can provide some code snippets how to receive the data from the USB port.

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

xaviershay, 2022-07-31:
That means I don't really need to do _any_ hardware (beyond stock PIN2DMD) which is very exciting & interesting. Would very much appreciate those code snippets.

FWIW today I whipped up a proof of concept analyzer: https://github.com/xaviershay/dmd-analyzer

lucky01, 2022-07-31:
I just cut the relevant parts from my code and copied it to the text file. I hope that helps.
Basically you have to send a 64byte packet with the first 3 bytes 0x01, 0xc3, 0xe8 and the 4th byte is the number of planes you want to receive. The number of planes in memory depend on the devicemode . For example for WPC it is 3 . For DE and Whitestar it is 2 and for SAM,Spike it is 4.

[interfaceUSB.txt](https://github.com/lucky01/PIN2DMD/files/9228945/interfaceUSB.txt)

xaviershay, 2022-08-01:
Thank you! Will be a bit of a delay since I need to acquire the hardware. Will report back if I end up making anything interesting :)

xaviershay, 2022-10-18:
Alright took a bit but I've made some progress.

Code is here: https://github.com/xaviershay/dmd-analyzer/blob/main/lib/analyzer.rb#L21

Good news: I'm able to read a dump from the screen.
Bad news: After an indeterminate period of time, the interface crashes and is inaccessible until I reboot the machine. This occurs faster when I increase framerate, so e.g. sleeping for 1s between dumps means it can usually run for a good number of seconds before crashing, but sleeping for 100ms means it usually crashes after the first frame or two.

I ported the CPP code ruby - the snippet you sent me needs a bit of work to compile and I'm not particularly handy with C++. I'm unsure if that's contributing the problem, now that I know it can work I might try the original C++ or Rust again to see if I get the same results.

I also don't have a good mental model for why it would crash at different rates depending on how long I delay between querying the interface, I don't have an understanding of the USB protocol yet.

I also suspect that the frames being returned aren't "aligned" in the same way that I would get from an emulator (it looks like one frame bleeding into the next a lot of the time), but that is possibly a quirk of a real machine.

Here is an example dump terminating in an timeout error (this is just the tail, it ran for probably 20s with 1s delay between captures):

```
                                                        
            ▗▄▄                                         
         ▗▙▙▝▀▜▌                                        
          ▌▌ ██▖                                        
         ▝▛▛▐██▌                                        
            ▝▀▀▘                                        
     ▗▄▄▄▖▗▄▄▄▄▗▄▄▄▄       ▟▌  ▟█▌▗██▖▟██ ▗██▖▟█▙▗██▌ ██▙▗██▌▟█▙
     ▐████▐████▐████       ▜▌  █▄▖▐▙▟▘█▚█ ▐▙▟▌▜█▛▐█▟▌ █▄█▐█▟▌█ █
     ▐█ ▐█▐█ ▐█▐█▙▐█       ▐▌  █▀█▐▛▜▌███ ▐▛▜▌███▐██▌ ▝▀█▐██▌█ █
     ▐█ ▐█▐█▄██▐██▟█       ██ ▌▜█▛▝██▘███▐▝██▘▜█▛▝██▌▌██▛▝██▌▜█▛
     ▐█ ▐█▐████▐████         ▝           ▘          ▝   
     ▐█ ▐█▐█ ▜█▐█▐██                                    
     ▐█▄▟█▐█▄▟█▐█▄██                                    
     ▐███▛▐███▛▐████                                    

              ▄▖                                        
         ▗▙▙ ▟▜▌                                        
          ▌▌▐▙▟▌                                        
         ▝▛▛▝▀▜▌                                        
              ▝▘                                        
     ▗▄▄▄▖▗▄▄▄▖ ▄▄▄▄       ▟▌  ▟█▌▗██  ▟█ ▗██▖▗█ ▗██  ▟█▙▗██▖▟█▙
     ▐████▐████▐████       ▜▌  █▄▖▐▙▄ ▟▘█ ▐▙▟▌▝█ ▐▙▄  █▄█▝▙▟▘█ █
    ███ ▐█▐█ ▐█▐█▖         ▐▌  █▀█▐▛▜▌███  ▀▜▌ █ ▐▛▜▌ ▝▀█▐▛▜▌█ █
    ███ ▐█▐█▄█▛ ▜█▖        ██ ▌▜█▛▝██▘  █▐ ██▘▐█▌▝██▘▌▐█▛▝██▘▜█▛
    ███ ▐█▐███▖  ▜█▖         ▝           ▘          ▝   
    ▝██ ▐█▐█ ▜█   ▜█                                    
    ▟██▄▟█▐█▄▟█▗▄▄▟█                                    
    █████▛▐███▛▐███▛                                    
    █▌                                                  
    ▀▘                                                  
                                                        
              ▄▖                                        
         ▗▙▙ ▟▜▌                                        
          ▌▌▐▙▟▌                                        
         ▝▛▛▝▀▜▌    ▟█▌█▐▌▟█▖█▖▟▌██▖██▗█▙▐▙▐▌           
              ▝▘    █  █▟▌█▟▌█▜▜▌█▟▌▐▌▐▌█▐██▌           
        ▄▖▗▄▄▄▖ ▄▄▄▄█▄▖█▐▌██▌█ ▟██▜██▙▐██▐▙██▖▗█ ▗██  ▟█▙▗██▖▟█▙
        ██▐████▐████▝▀▘▀▝▘▀▜▌▀ █▙▛▐▙█▀▟▀█▝▜██▌▝█ ▐▙▄  █▄█▝▙▟▘█ █
    █▌ ▐██▐██▐█▐█▖ ▐█      ▐▌  █▀█▐▛▜▌███  ▀▜▌ █ ▐▛▜▌ ▝▀█▐▛▜▌█ █
    █▌ ▐██▐███▛▝██▖█▛      ██ ▌▜█▛▝██▘  █▐ ██▘▐█▌▝██▘▌▐█▛▝██▘▜█▛
    █▙ ▟██▐███▖ ████▌        ▝ ▟█▌ ▗█▌▟█▙▘▗██▖▟█▙▗██▞ ▟█▙▗██▖▟█▙
    ▝███▜█▐█▜██ ▐█▜█           █▄▖▗▛▐▌█ █ ▐▌▐▌█ █▐▌▐▌ █ █▐▌▐▌█ █
    ▟█▀███▟█▟██▗▟███           █▀█▐██▌█ █ ▐▌▐▌█ █▐▌▐▌ █ █▐▌▐▌█ █
    █▌ ▐█▛████▛▐███▛           ▜█▛  ▐▌▜█▛▐▝██▘▜█▛▝██▘▌▜█▛▝██▘▜█▛
    █▌ ▐█▐█▀▀▜█  ▐█                      ▘          ▝   
    ▀▘ ▝▀▝▀  ▝▀  ▝▀                                     
         ▐█▙▐██▐▙▗█▗█▙▐▌ ▐█▌███▐█▌▟█▖█▖█  ▐██▌██▐▙▗█▐██ 
         ▐▌█▐▙▖▐▛▛█▐▌█▐▌  █  █  █ █▐▌███   ▐▌ ▐▌▐▛▛█▐▙▖ 
         ▐▙█▐▙▄▐▌ █▐▙█▐▙▄▗█▖ █ ▗█▖█▟▌█▝█   ▐▌ ▟▙▐▌ █▐▙▄ 
         ▝▀▘▝▀▀▝▘ ▀ ▀▘▝▀▀▝▀▘ ▀ ▝▀▘▝▀ ▀ ▀   ▝▘ ▀▀▝▘ ▀▝▀▀ 
                    ▟█▌█▐▌▟█▖█▖▟▌██▖██▗█▙▐▙▐▌           
                    █  █▟▌█▟▌█▜▜▌█▟▌▐▌▐▌█▐██▌           
                    █▄▖█▐▌█▜▌█ ▐▌█▀ ▟▙▐▙█▐▌▜▌           
                    ▝▀▘▀▝▘▀▝▘▀ ▝▘▀  ▀▀ ▀▘▝▘▝▘           
    █▌ ▐█  ▐█  ▐█  ▐█                                   
    █▌ ▐█  ▟█▖ ▝█▌ █▛                                   
    █▙ ▟█  ██▌  █▙▗█▌          ▟█▌ ▗█▌▟█▙ ▗██▖▟█▙▗██▖ ▟█▙▗██▖▟█▙
    ▝███▘ ▐█▜█  ▐█▐█           █▄▖▗▛▐▌█ █ ▐▌▐▌█ █▐▌▐▌ █ █▐▌▐▌█ █
    ▟█▀█▙ ▟█▐█▖ ▝██▛           █▀█▐██▌█ █ ▐▌▐▌█ █▐▌▐▌ █ █▐▌▐▌█ █
    █▌ ▐█ ████▌  ██▌ ▗▄▖▄▖▗▄▖▄▄▜██▖▗▐▌██▛▐▞██▘▜█▛▝██▘▌▜█▛▝██▘▜█▛
    █▌ ▐█▐█▀▀▜█  ▐█  ▐▄ ▙▞▐▄ ▙▖  ▌▐▐▚▌▌ ▝▛          ▝   
    ▀▘ ▝▀▝▀  ▝▀  ▝▀  ▐  ▌▐▐▄▖▙▄  ▚▞▐ ▌▙▖ ▌              
                   ▗▀▀▖▞▀▚                              
                   ▐  ▌▌ ▐                              
                   ▐  ▌▌ ▐                              
                    ▀▀ ▝▀▘                              
/Users/xaviershay/.asdf/installs/ruby/3.1.2/lib/ruby/gems/3.1.0/gems/libusb-0.6.4/lib/libusb/constants.rb:68:in `raise_error': LIBUSB::ERROR_NOT_FOUND in libusb_release_interface (LIBUSB::ERROR_NOT_FOUND)
	from /Users/xaviershay/.asdf/installs/ruby/3.1.2/lib/ruby/gems/3.1.0/gems/libusb-0.6.4/lib/libusb/dev_handle.rb:100:in `release_interface'
	from /Users/xaviershay/.asdf/installs/ruby/3.1.2/lib/ruby/gems/3.1.0/gems/libusb-0.6.4/lib/libusb/dev_handle.rb:84:in `ensure in claim_interface'
	from /Users/xaviershay/.asdf/installs/ruby/3.1.2/lib/ruby/gems/3.1.0/gems/libusb-0.6.4/lib/libusb/dev_handle.rb:84:in `claim_interface'
	from /Users/xaviershay/.asdf/installs/ruby/3.1.2/lib/ruby/gems/3.1.0/gems/libusb-0.6.4/lib/libusb/device.rb:77:in `block in open_interface'
	from /Users/xaviershay/.asdf/installs/ruby/3.1.2/lib/ruby/gems/3.1.0/gems/libusb-0.6.4/lib/libusb/device.rb:62:in `open'
	from /Users/xaviershay/.asdf/installs/ruby/3.1.2/lib/ruby/gems/3.1.0/gems/libusb-0.6.4/lib/libusb/device.rb:76:in `open_interface'
	from /Users/xaviershay/code/dmd-analyzer/lib/analyzer.rb:31:in `open'
	from /Users/xaviershay/code/dmd-analyzer/lib/analyzer.rb:81:in `run'
	from -e:1:in `<main>'
/Users/xaviershay/.asdf/installs/ruby/3.1.2/lib/ruby/gems/3.1.0/gems/libusb-0.6.4/lib/libusb/dev_handle.rb:549:in `submit_transfer': error TRANSFER_TIMED_OUT (LIBUSB::ERROR_TIMEOUT)
	from /Users/xaviershay/.asdf/installs/ruby/3.1.2/lib/ruby/gems/3.1.0/gems/libusb-0.6.4/lib/libusb/dev_handle.rb:397:in `bulk_transfer'
	from /Users/xaviershay/code/dmd-analyzer/lib/analyzer.rb:48:in `block (3 levels) in open'
	from /Users/xaviershay/code/dmd-analyzer/lib/analyzer.rb:83:in `block in run'
	from /Users/xaviershay/code/dmd-analyzer/lib/analyzer.rb:52:in `block (2 levels) in open'
	from /Users/xaviershay/.asdf/installs/ruby/3.1.2/lib/ruby/gems/3.1.0/gems/libusb-0.6.4/lib/libusb/dev_handle.rb:82:in `claim_interface'
	from /Users/xaviershay/code/dmd-analyzer/lib/analyzer.rb:38:in `block in open'
	from /Users/xaviershay/.asdf/installs/ruby/3.1.2/lib/ruby/gems/3.1.0/gems/libusb-0.6.4/lib/libusb/device.rb:78:in `block (2 levels) in open_interface'
	from /Users/xaviershay/.asdf/installs/ruby/3.1.2/lib/ruby/gems/3.1.0/gems/libusb-0.6.4/lib/libusb/dev_handle.rb:82:in `claim_interface'
	from /Users/xaviershay/.asdf/installs/ruby/3.1.2/lib/ruby/gems/3.1.0/gems/libusb-0.6.4/lib/libusb/device.rb:77:in `block in open_interface'
	from /Users/xaviershay/.asdf/installs/ruby/3.1.2/lib/ruby/gems/3.1.0/gems/libusb-0.6.4/lib/libusb/device.rb:62:in `open'
	from /Users/xaviershay/.asdf/installs/ruby/3.1.2/lib/ruby/gems/3.1.0/gems/libusb-0.6.4/lib/libusb/device.rb:76:in `open_interface'
	from /Users/xaviershay/code/dmd-analyzer/lib/analyzer.rb:31:in `open'
	from /Users/xaviershay/code/dmd-analyzer/lib/analyzer.rb:81:in `run'
	from -e:1:in `<main>'
```

Subsequent calls to the same code show an IO error:
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
xaviershay, 2022-10-18:
Ah no, not releasing on every packet. Worth a shot.

xaviershay, 2022-12-29:
Late update: tried claim/open/close for each packet, didn't really help. Abandoning for now.

Closed 2022-12-29.

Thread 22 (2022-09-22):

Reset problem with last bootloader

saddys, 2022-09-22:
With new núcleo board there are the reset problem. Can someone share the (V2.J34.M26) stlink upgrades or a work bootloader? On st.com site there are only the last. Thanks

lucky01, 2022-09-22:
This is not a pin2dmd issue.
https://vpuniverse.com/forums/topic/4582-bug-in-st-link-firmware-v2j36m26/
Maybe better ask on vpuniverse.com

Closed 2022-09-22.

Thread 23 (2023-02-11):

devicedmd.dll version

julianmiguel, 2023-02-11:
Hello Lucky
i have something strange
I'm using PIN2DMD Version 4.44

I'm using Your deviceDMD.DLL working well for pac files.
But this dll is not working for Pinup popper (works with an other dll) and not working with deadpool vpx table
do you know if it is possible to select from a script the good deviceDMD.Dll working ?

Is it possible to downngrade my pin2dmd firmware ?
thanks a lot

lucky01, 2023-02-11:
This DLL is only tested with pinmame where the dmddevice.dll interface was
introduced by me.
If other programs like pinup popper use that api but use improper
initialization like sending empty game name or
deadpool using non standard DMD resolution (128x16,128x32,192x64,256x64)
the problem should be fixed on their side.
Alternatively you can try this DLL which is extensively tested and has been
reported to be working well.
https://vpuniverse.com/forums/topic/7504-new-version-dmd-extensions-with-pin2dmd-coloring-plugin-and-pac-file-support/
Please understand that I don´t have the time to give one on one support for
specific VPin setups.
If you need further support please use the power of the community in forum.

You can downgrade your pin2dmd firmware using the upd file, but it is
always recommended to update to the latest version.
So far no issues have been reported with the latest version.

Am Sa., 11. Feb. 2023 um 15:05 Uhr schrieb julianmiguel <
***@***.***>:

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

julianmiguel, 2023-02-11:
thanks for all thoses informations
i have test all you dmddevice.dll version and the problem start after the 24/04/22
it is just when you start to encaps all dll in a zip package
do you know what change between those versions
thanks a lot

lucky01, 2023-02-11:
I worked a lot on the dmdext integration which now has been replaced by the plugin DLL I linked above.
Try that version. It should solve the issues you currently have. Like I said my dmddevice.dll is only tested with the rom emulations in pinmame.

Closed 2023-02-11.

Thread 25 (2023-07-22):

Firmware compatibility of custom boards

VaderMester, 2023-07-22:
Hi,

I was updating some custom boards to the latest 4.51 FW and it no longer works.
**Last version known to work: V4.41**

I'm using the Nucleo-144 FW as it is for custom boards, I've been using the Nucle FW for a while, and it was working on custom boards.

I checked to see exactly which version stops working.
V4.41 was the last version to work on my custom boards.
All my custom boards are based on Nucleo-144 V4 schematic. They use F429ZIT6 and F407VET6 and F407VGT6 CPUs.
V4.41 works on all of them, **from V4.42 none of them works.**
I would accept if it would not work on a F407, but it is also not working on an F429ZIT6m which is the exact same chip as on the Nucleo-144.

Symptoms: No picture, and USB detection on Windows also fails.

Can you give me any idea which FW to use on custom boards from V4.42?

lucky01, 2023-07-22:
https://pin2dmd.com/hardware/#2.4

lucky01, 2024-03-01:
Hey Bence,

on behalf of the children with cancer and from the orphanage where the pin2dmd donations go to I congratulate you that you found a way to crack the pin2dmd fimware to sell it again in your shop without making a single donation.

You are a true hero !

VaderMester, 2024-03-02:
Hi Lucky01!

I'm surprised to read these allegations, and I am wondering what made you
think that I am involved in the actions you described.
Can you please send me a picture of the PCB you think has cracked FW? I
would like to make sure it is not my design, as I would not like to be a
part of any of it.

I would like to be as transparent with you as possible.

I assume here you referring to the PCBs made by Pirategames.
I am not involved with their business, I'm only a freelancer individual
entrepreneur, who - as a hobby - designs PCBs for various customers, them
included.
This is a part time job, and the only thing I do is design, and build the
PCBs by hand.
Fun fact: I don't not even own the designs I make for them as per contract,
and I do not get any shared profits for the sales. My contractual
obligations end with the shipping of the last PCB, and until the warranty
period is over.

I was aware that a cracked PCB existed, but it was not my design and build.
All I know is that it is a red PCB (it is also appears on your page), but
as I heard the person who made those boards and FW crack, actually passed
away last year. He was in his 50s as I know and died of brain hemorrhage.

I have only designed a blue colored PCB for them, which was based on the
Nucleo144 design and FW. It is a blue PCB with two CPU footprints on the
board to have the ability to take both 100pin and 144pin packages.
As I remember only 20 PCBs have been made, but all of them were licensed by
you, so fully legal apart from the custom design, the last batch was in
summer 2022.

There was another batch in the plan in 2023, but that was when I discovered
that there is no longer support for custom PCBs (hence the Github issue
posted), so I did not make them in the end.

I was planning on releasing a PCB to the community, that has several nice
features, like 5V ESD protection diodes, reverse voltage protection on the
supply, the Option button being combined with the Boot0 pin to allow FW
upload with USB, and without the need of an ST-Link, and of course the dual
CPU footprint setup, so you can essentially use any CPU from F407 to F429
and F427, in case chip shortage is an issue. Your custom FW has been tested
on F429, F427 CPUs, and F407VET6 and F407VGT6 MCUs, so it is a pretty good
candidate to allow more people to use a nice design.
Also, included with the PCB design, I designed a power board to convert any
voltage from 9V to 36V to 5V, made in a way that it can be soldered to the
PCB, so you can decide if you need it or not.

It is not ready yet, because - A: I am swamped right now due to me
attending University on weekends to complete my MSc course, - B:  You
stopped support for custom PCBs.
I was hoping to make a deal with you on this, once I have time to finish
it, but after your accusations, I think these hopes are short lived.
In any case if all goes well, I will contact you later this year, so that I
can send a prototype of the design, and from that point it is up to you to
do whatever you want with that.
Most of these extra features have been tested already, but the power module
needs some extra filtering as it has a few low amplitude switching spikes
on the output, which I do not like, but after it is fixed I would be ready
to post it.
The PCB also needs some modifications, and some kind of branding (You name
your board Nucle, EVO, so I'll add a design name to it also), so I would
not violate the copyright of my previous design, which now is owned by
Pirategames. I would like to avoid trouble as much as possible.

*Bujtor Bence*

*Individual Enterpreneur*
Electrical engineer
------------------------------------------------------------
📧   ***@***.***
📱       +3670-947-5173

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

Closed 2023-07-22.

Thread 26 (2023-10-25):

Unable to connect to PIN2DMD

ptroost68, 2023-10-25:
i bought a virtual pinball cab with a Pin2dmd device installed.  i rebuilt the computer and have a clean install of Windows 11 but cannot connect to the device with ST-LINK software or Pin2dmd utility.  it lights up and says "Pin2dmd virtual pinball'

i have replaced the USB driver as instructed.

In device manager it says "libusb-win32 devices" and lists "ST-Link Debug (Interface 0)" and "ST-Link VCP Ctrl (Interface 2)"

I can't find any tutorials or debugging advice to get this working with virtual pinball

thank you!

lucky01, 2023-10-25:
Please ask all support questions in the vpuniverse forum or check Pin2dmd.com. I don't have time for one on one support. You probably use the wrong usb port on the controller Am 25.10.2023 um 01:14 schrieb ptroost68 ***@***.***>:
i bought a virtual pinball cab with a Pin2dmd device installed.  i rebuilt the computer and have a clean install of Windows 11 but cannot connect to the device with ST-LINK software or Pin2dmd utility.  it lights up and says "Pin2dmd virtual pinball'
i have replaced the USB driver as instructed.
In device manager it says "libusb-win32 devices" and lists "ST-Link Debug (Interface 0)" and "ST-Link VCP Ctrl (Interface 2)"
I can't find any tutorials or debugging advice to get this working with virtual pinball
thank you!

—Reply to this email directly, view it on GitHub, or unsubscribe.You are receiving this because you are subscribed to this thread.Message ID: ***@***.***>

Closed 2023-10-25.

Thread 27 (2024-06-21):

SYSXDMD segments missing issue

TonySV6, 2024-06-21:
Hello and thank you for the great hardware. I have an issue with some games and I tried everything to fix.
My game swords of fury only works on the DE setting. It’s almost perfect but the bottom row is missing some segments. I think because it is 2x alpha and swords is alpha and numeric. The wpc setting is all wrong.
One other small problem is Whirlwind. It has the very last character missing some segments. I have attached pictures to show.

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

lucky01, 2024-06-22:
In fact the first test was done on a whirlwind, and if you look at the
video here
https://www.youtube.com/watch?v=C3NiMk1XTwA
there seems no missing segment problem.
I assume it is a hardware issue either cabeling or a missing connection on
the sysxdmd board.

Am Fr., 21. Juni 2024 um 22:40 Uhr schrieb TonySV6 ***@***.***
>:

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

TonySV6, 2024-06-22:
I have tried all 3 different cables, and all 5 of my boards and all with the same issue.
And sorry, I shouldn't have said segment. It's not the whole segment, just a few dots of the last segment.
In your video, it actually doesn't have a number or letter with the missing dots, so you can't see the issue in that video.
On Whirlwind, it's only 3 dots missing on the last segment, but the 3 inside dots on the numbers 2, 3, 5, 6 and 8.
If you check it in display test mode, you can see the missing dots.

And on my Swords of Fury, the missing dots is on the entire bottom row, not just the last segment.

You can see the 0 doesn't show it, but the 5 does.

Whirlwind display test...

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

lucky01, 2024-06-24:
O.K. This will take some time. I need to setup a Whirlwind CPU on the bench
to test and debug this.
Will return to you with the result.

Am Sa., 22. Juni 2024 um 08:59 Uhr schrieb TonySV6 ***@***.***
>:

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

lucky01, 2024-06-24:
I had a quick look at the code and it seems to be a timing issue. I will see if I can add a parameter to make the timing adjustable.

TonySV6, 2024-06-26:
> I had a quick look at the code and it seems to be a timing issue. I will see if I can add a parameter to make the timing adjustable.

Great! If you need anymore information from me, just let me know.

lucky01, 2024-06-27:
I have uploaded a new version. Please test !

lucky01, 2024-06-27:
According to Pinmame Swords should look like this
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

lucky01, 2024-06-27:
I think I need to add 2x7Alpha + 2x7Num as a display layout for that.

TonySV6, 2024-06-28:
I tested my Whirlwind with the new update and it's working great now! Thanks!!

For Swords of Fury, I select WPC 2x Alpha 2x Numeric mode in settings and nothing looks right :/ The characters look all nonsense.
But, if I put it in the DE 2x alpha mode it works, but then the bottom line is wrong. Could it be because there is no numeric setting for this?
Maybe if you added a DE 2x 7 alpha 2x 7 numeric that could work?

lucky01, 2024-06-28:
I just uploaded v1.02 which adds WPC 2x7alpha 2x7num as display mode to display swords correctly.

TonySV6, 2024-07-02:
I just got a chance to test it now and it works! Yay.
Whatever the problem was, it is now fixed, Looks good.
I'll do some more thorough testing, but from what I've seen, it looks like it's working so far.
Thank you!

Closed 2024-07-04.

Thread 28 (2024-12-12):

hello i have a problem

ftnapalm, 2024-12-12:
hello
i have to change my stm32 card because I broke the micro usb is it possible to have a new activation file by making a paypal donation?
because my code is:
D39004E00035134
thanks in advance.
cordially Mr. Carpentier.

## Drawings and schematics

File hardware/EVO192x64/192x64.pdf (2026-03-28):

# GND ⁴⁷R

# C10R⁴

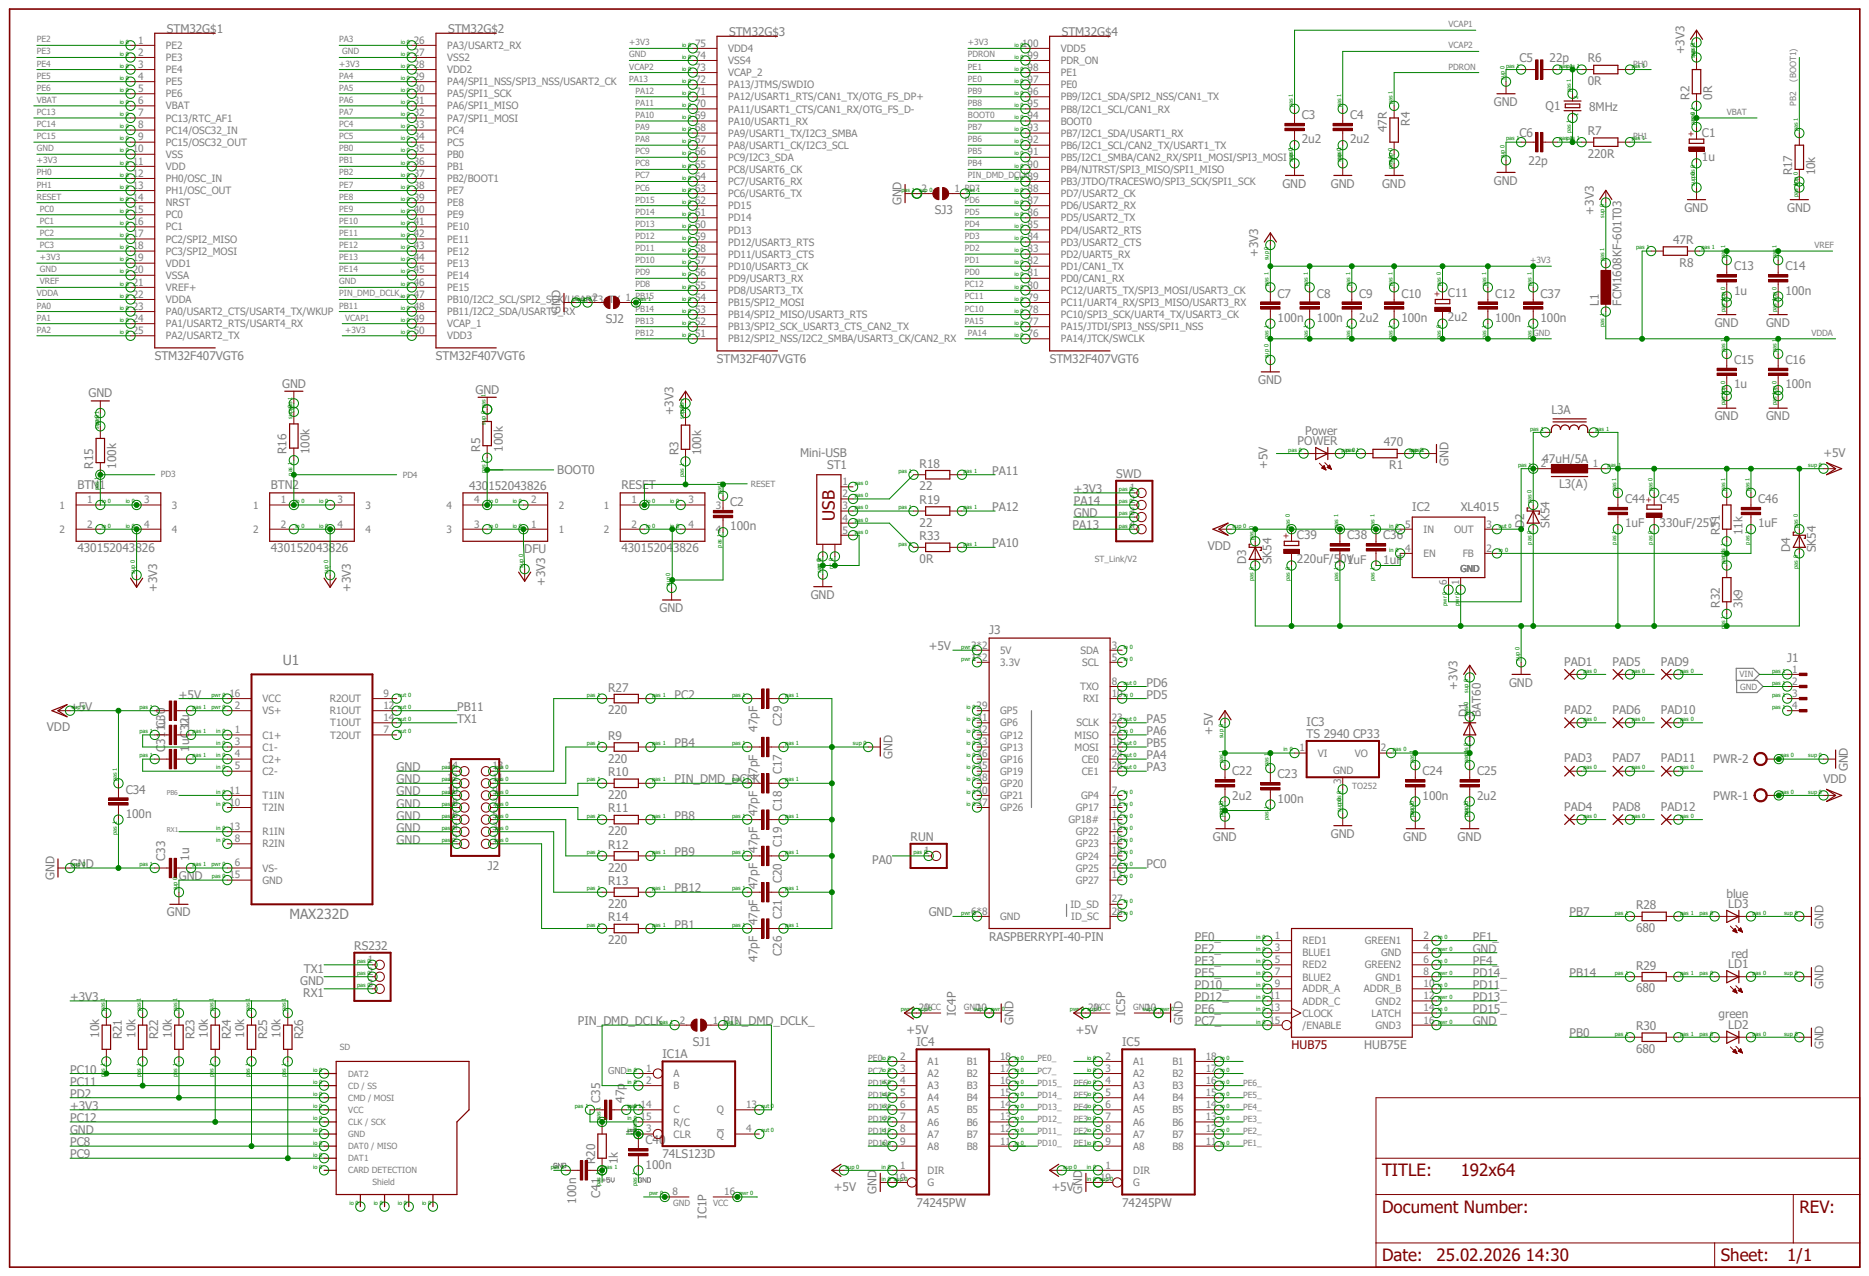
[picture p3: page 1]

Document Number: | REV:

Date: 25.02.2026 14:30 | Sheet: 1/1

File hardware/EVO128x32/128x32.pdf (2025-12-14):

# GND ⁴⁷R

# C10R⁴

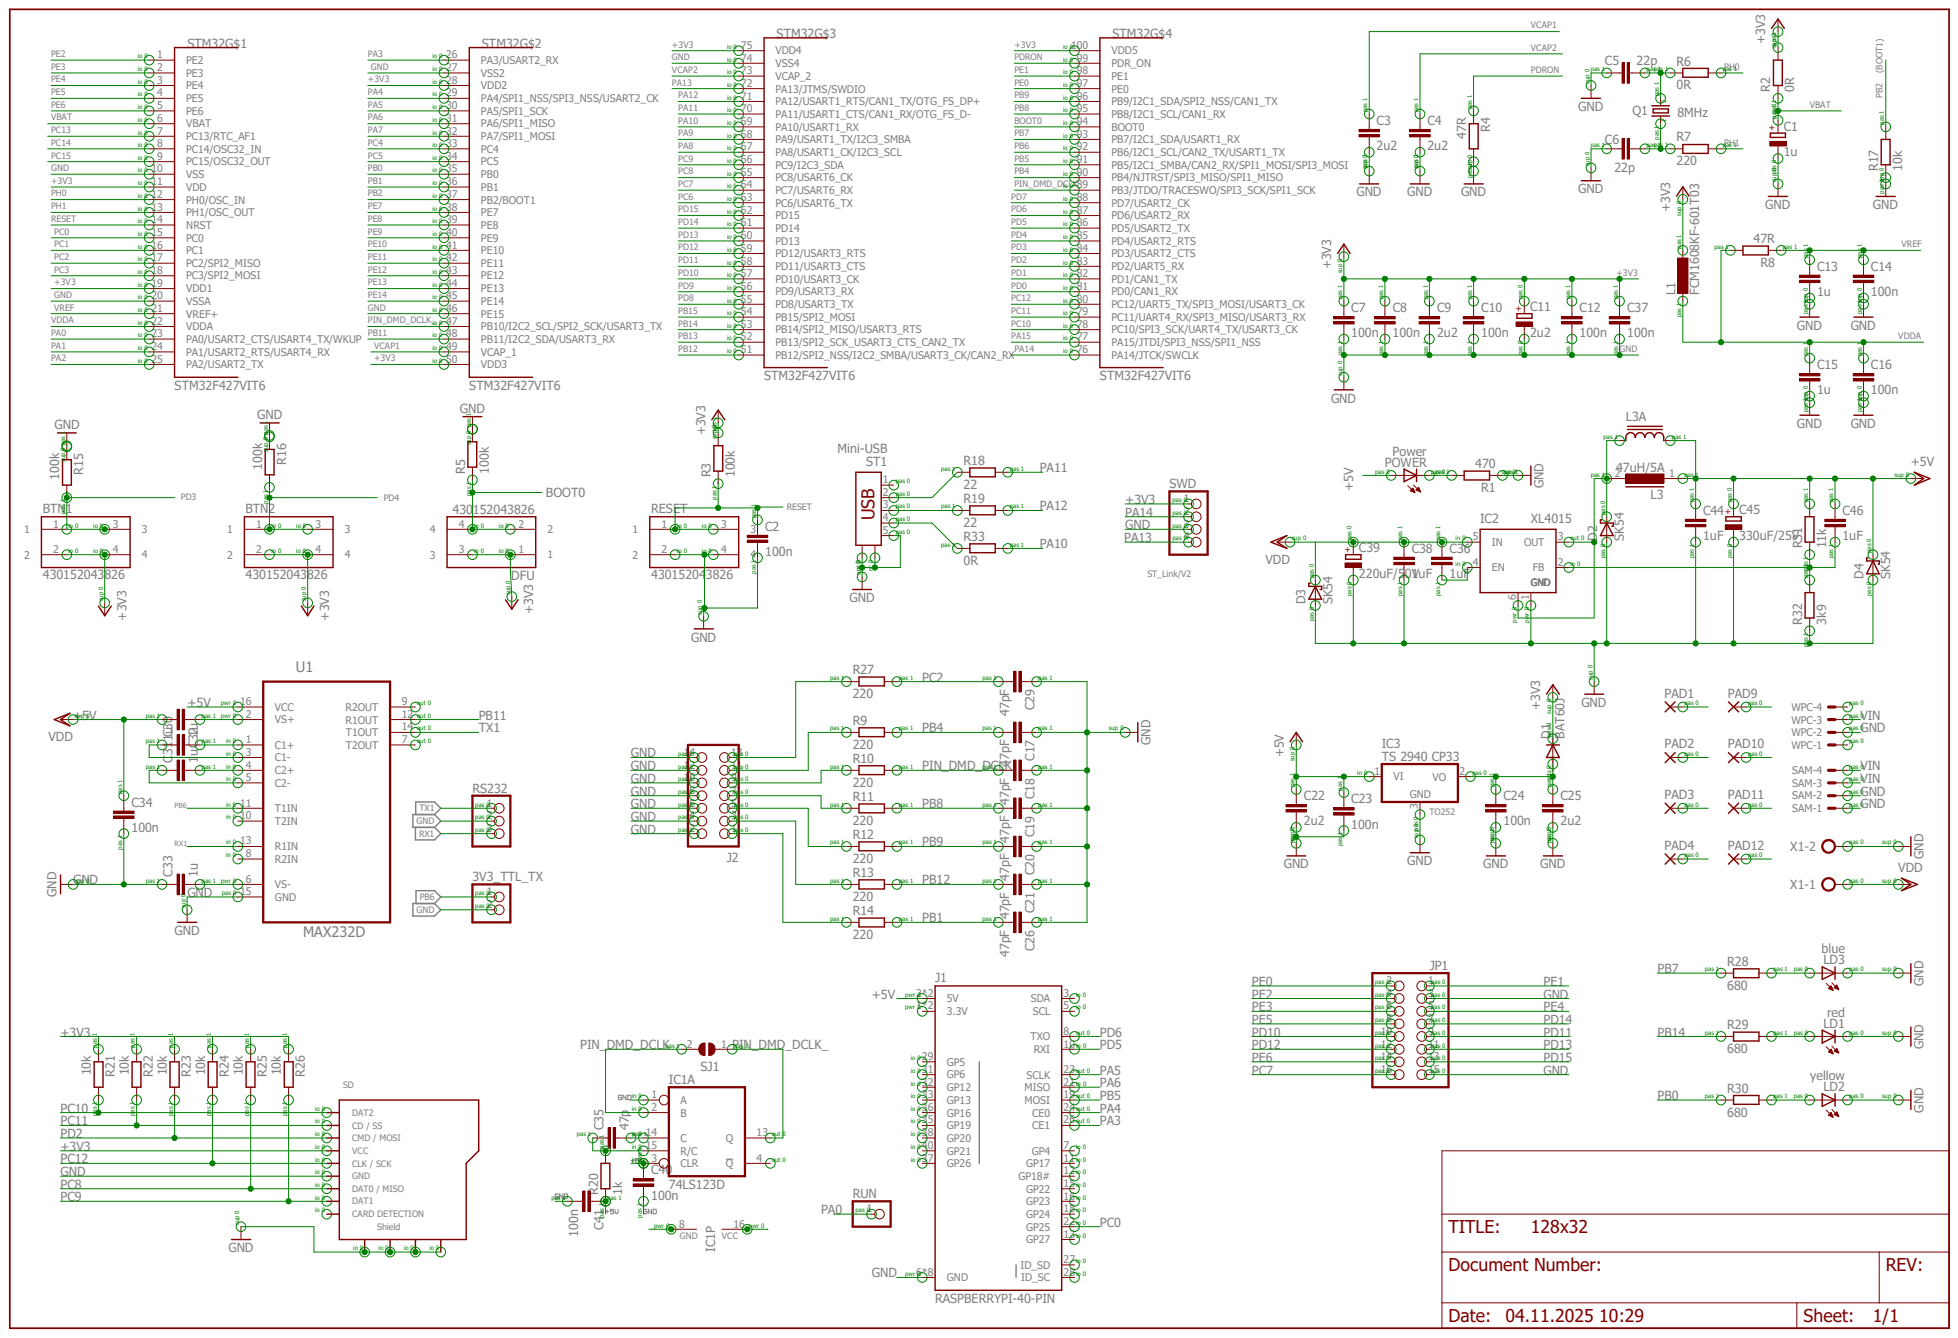
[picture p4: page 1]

pas 0 sup 0 sup 0 pas 1 pas 1 sup 0

io 0 pas 1 pas 1 sup 0

Document Number: | REV:

Date: 04.11.2025 10:29 | Sheet: 1/1

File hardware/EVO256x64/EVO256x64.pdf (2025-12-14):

# GND ⁴⁷R

# +5V GND GND GND

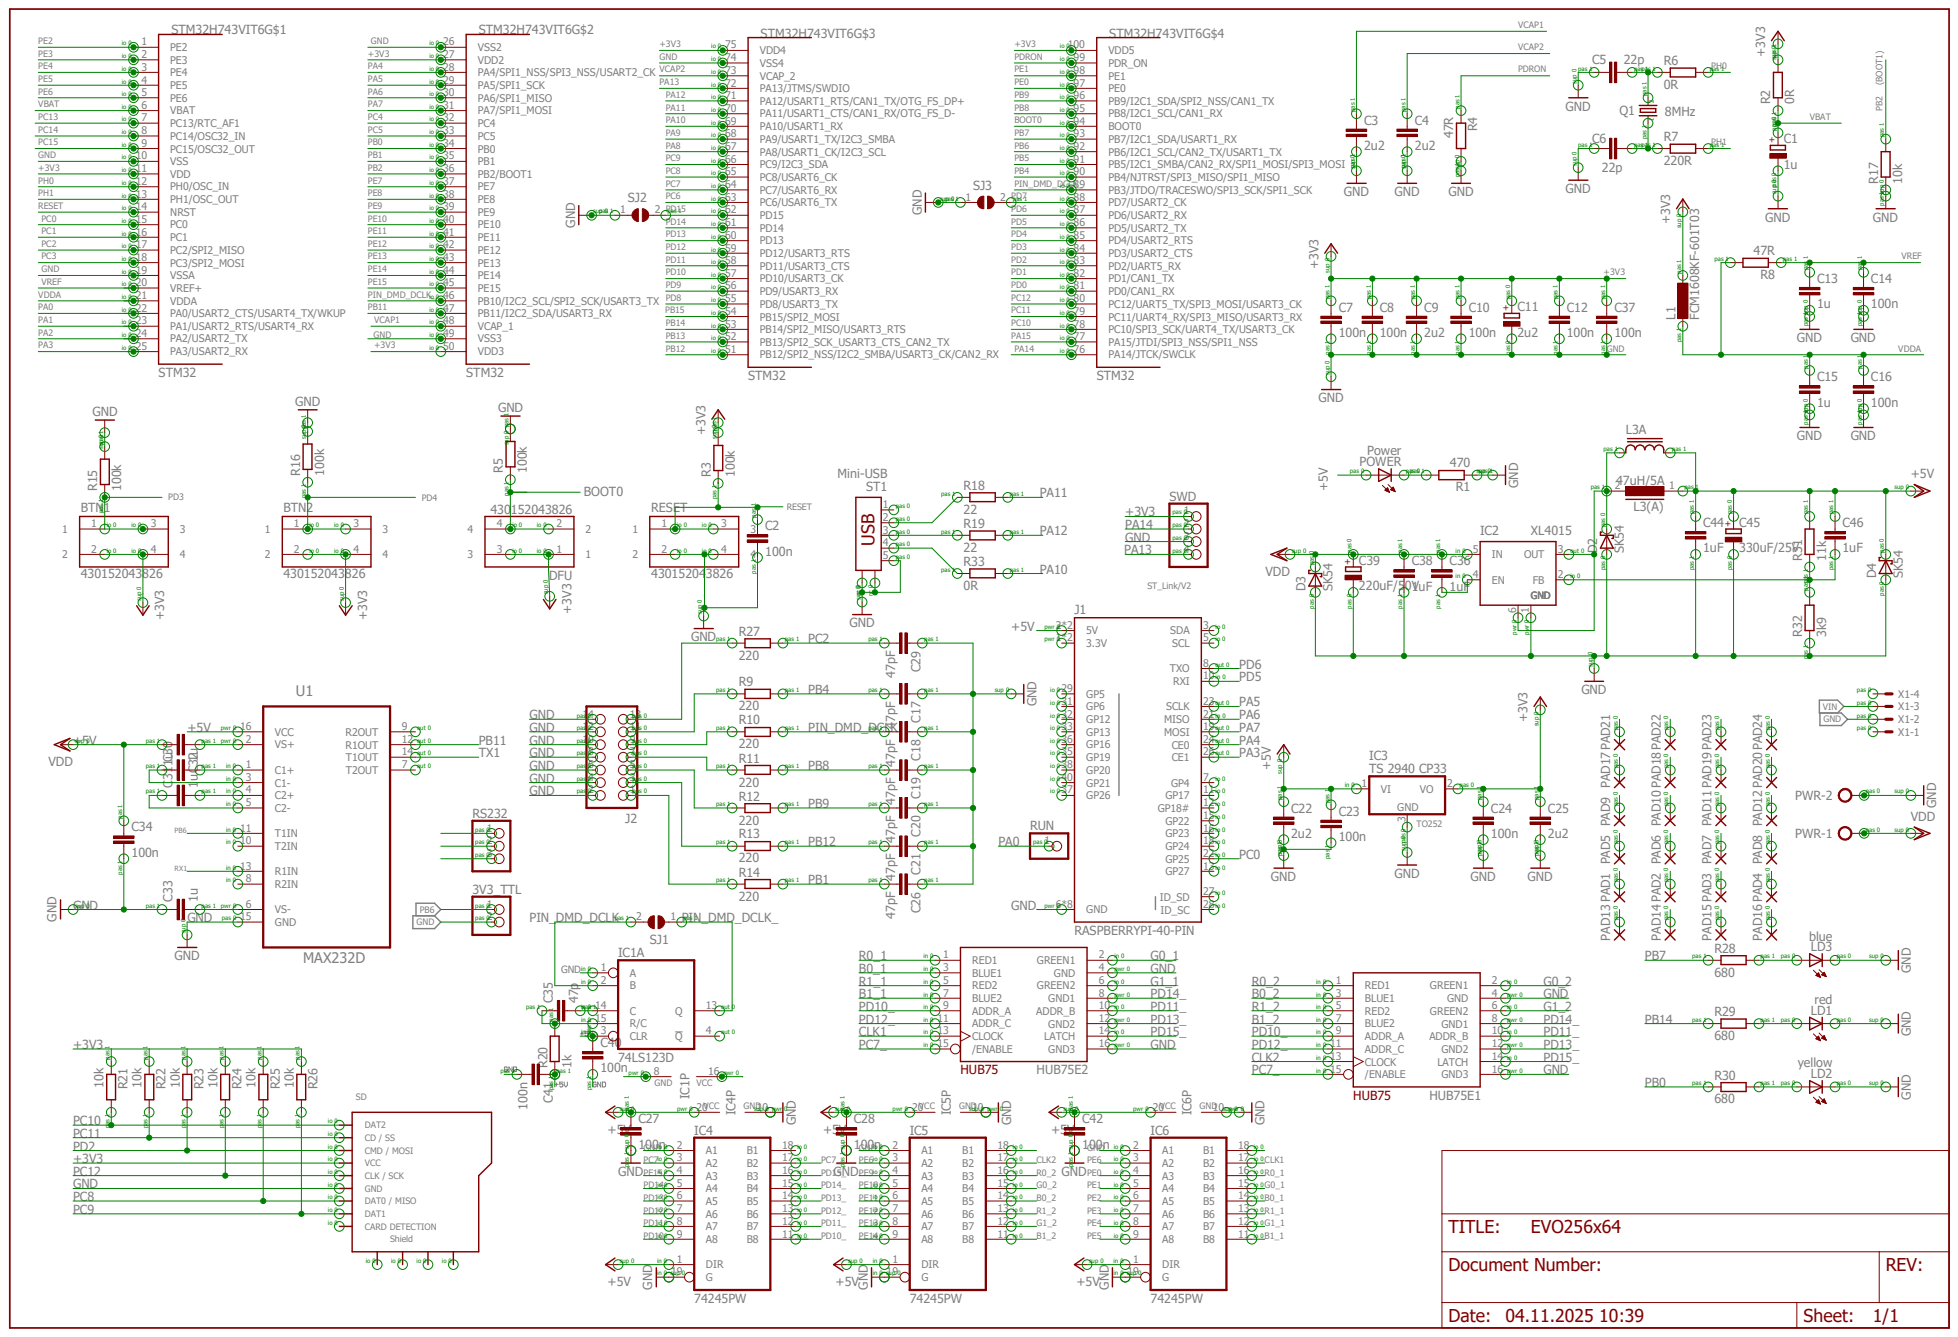
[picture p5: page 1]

Document Number: | REV:

Date: 04.11.2025 10:39 | Sheet: 1/1

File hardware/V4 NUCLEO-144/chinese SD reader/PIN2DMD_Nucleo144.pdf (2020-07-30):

A

A

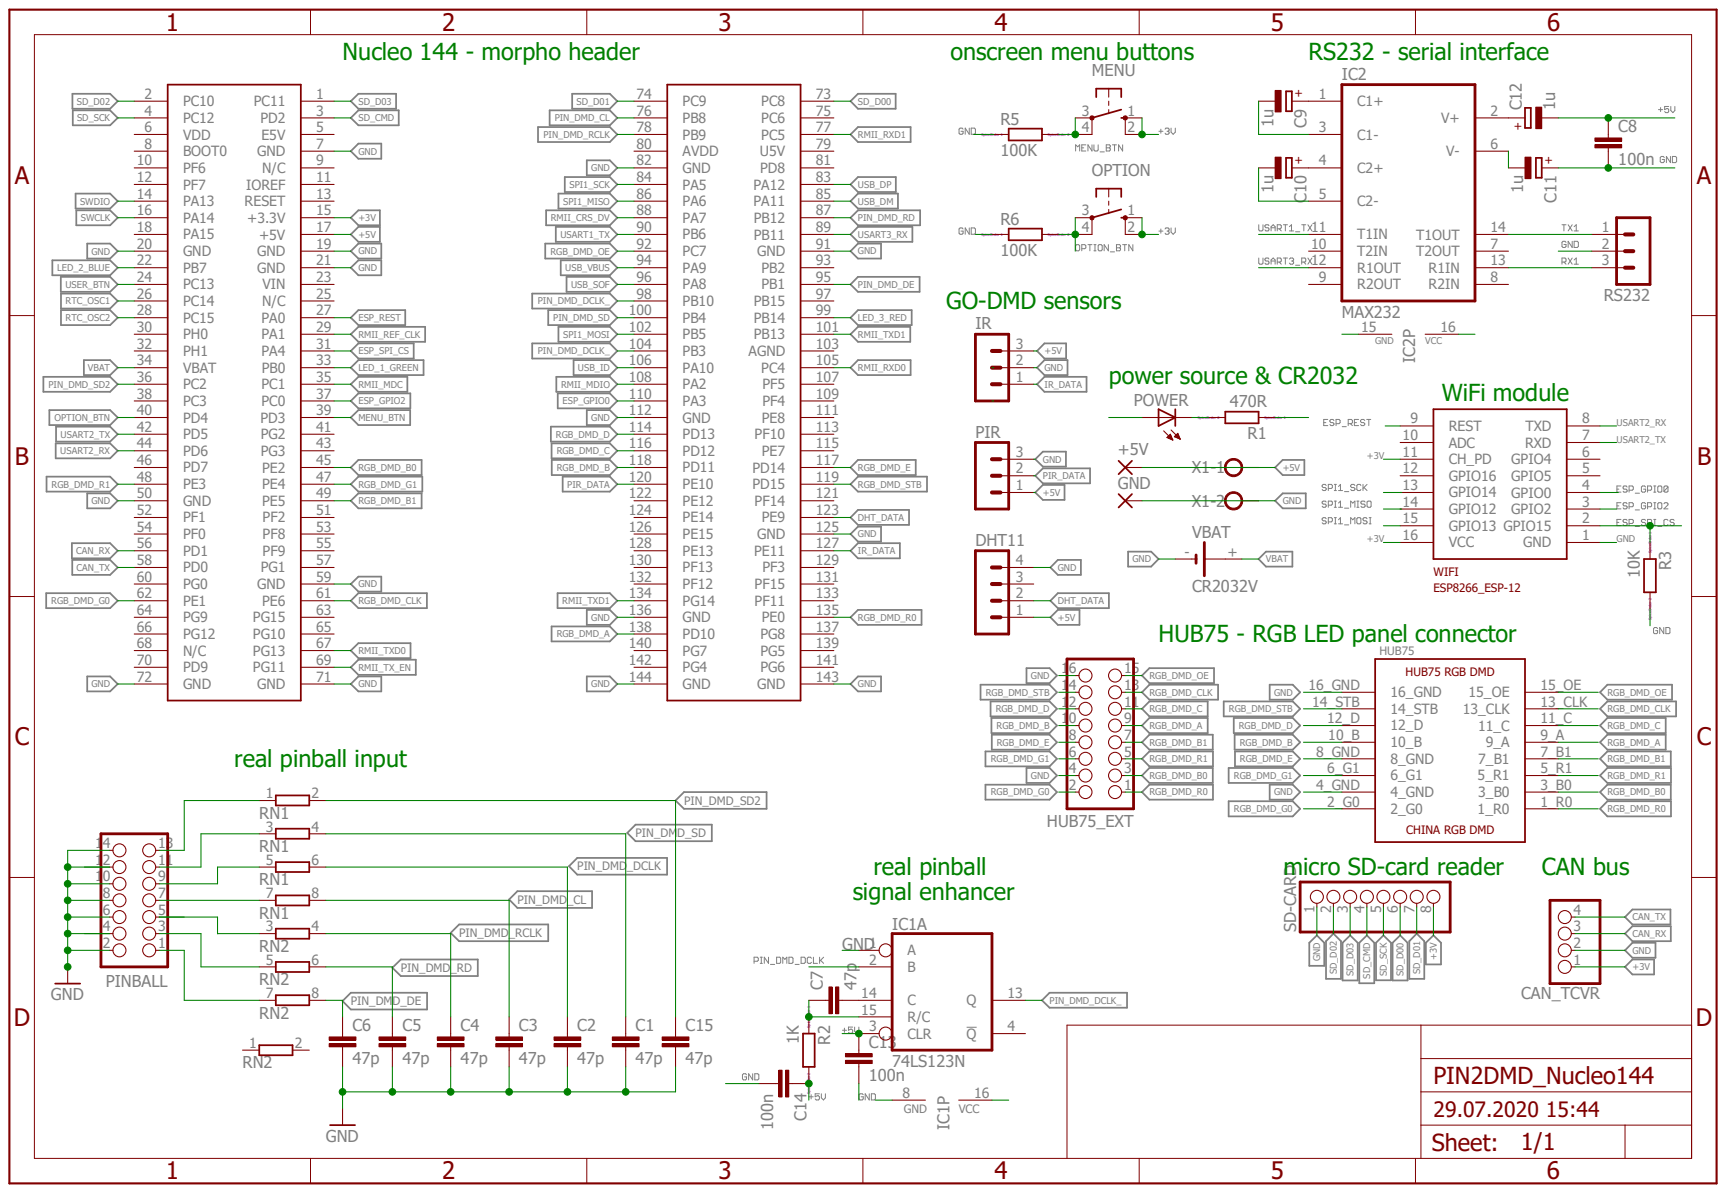
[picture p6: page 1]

HUB75 - RGB LED panel connector

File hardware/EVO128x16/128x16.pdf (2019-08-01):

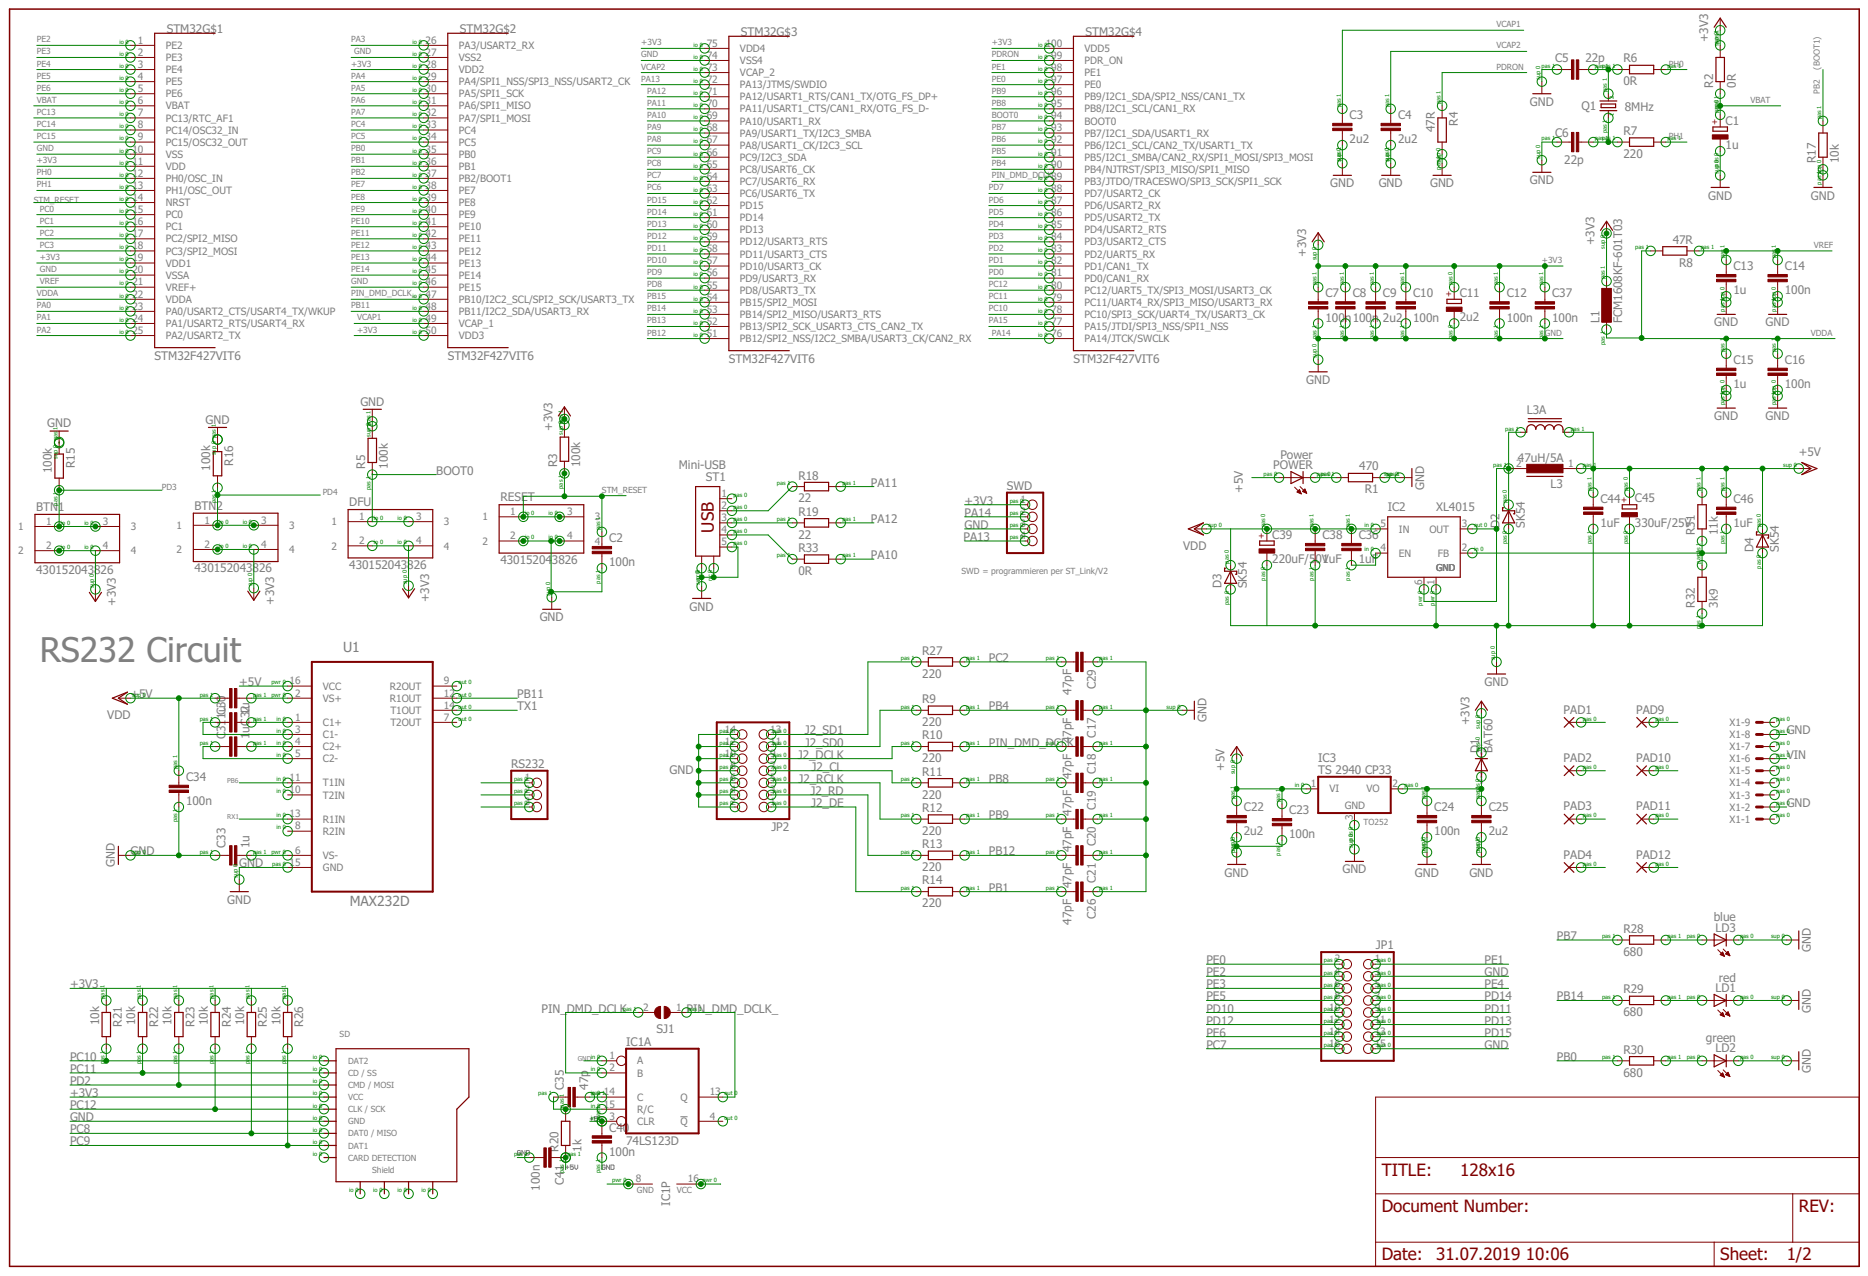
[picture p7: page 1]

sup 0 sup 0 pas 1 pas 1

1 2 pas 1 pas 1 pas 1 pas 1
8MHz 0R

sup 0 pas 1 pas 1 pas 1 pas 1

pas 0 pas 0 pas 1 pas 1 pas 1 pas 1

sup 0 sup 0 pas 1 pas 1 pas 1 pas 1

pas 0 pas 0 pas 1 pas 1

pas 1 pas 1 pas 0 pas 0

pas 1 pas 1 pas 1

pas 0 pas 0 pas 0 pas 0 pas 0 pas 0 pas 0 pas 0 pas 0

pas 1 pas 1 pas 1 pas 1 pas 1 pas 1

DAT2 CD / SS CMD / MOSI DAT0 / MISO

Document Number: | REV:

Date: 31.07.2019 10:06 | Sheet: 1/2

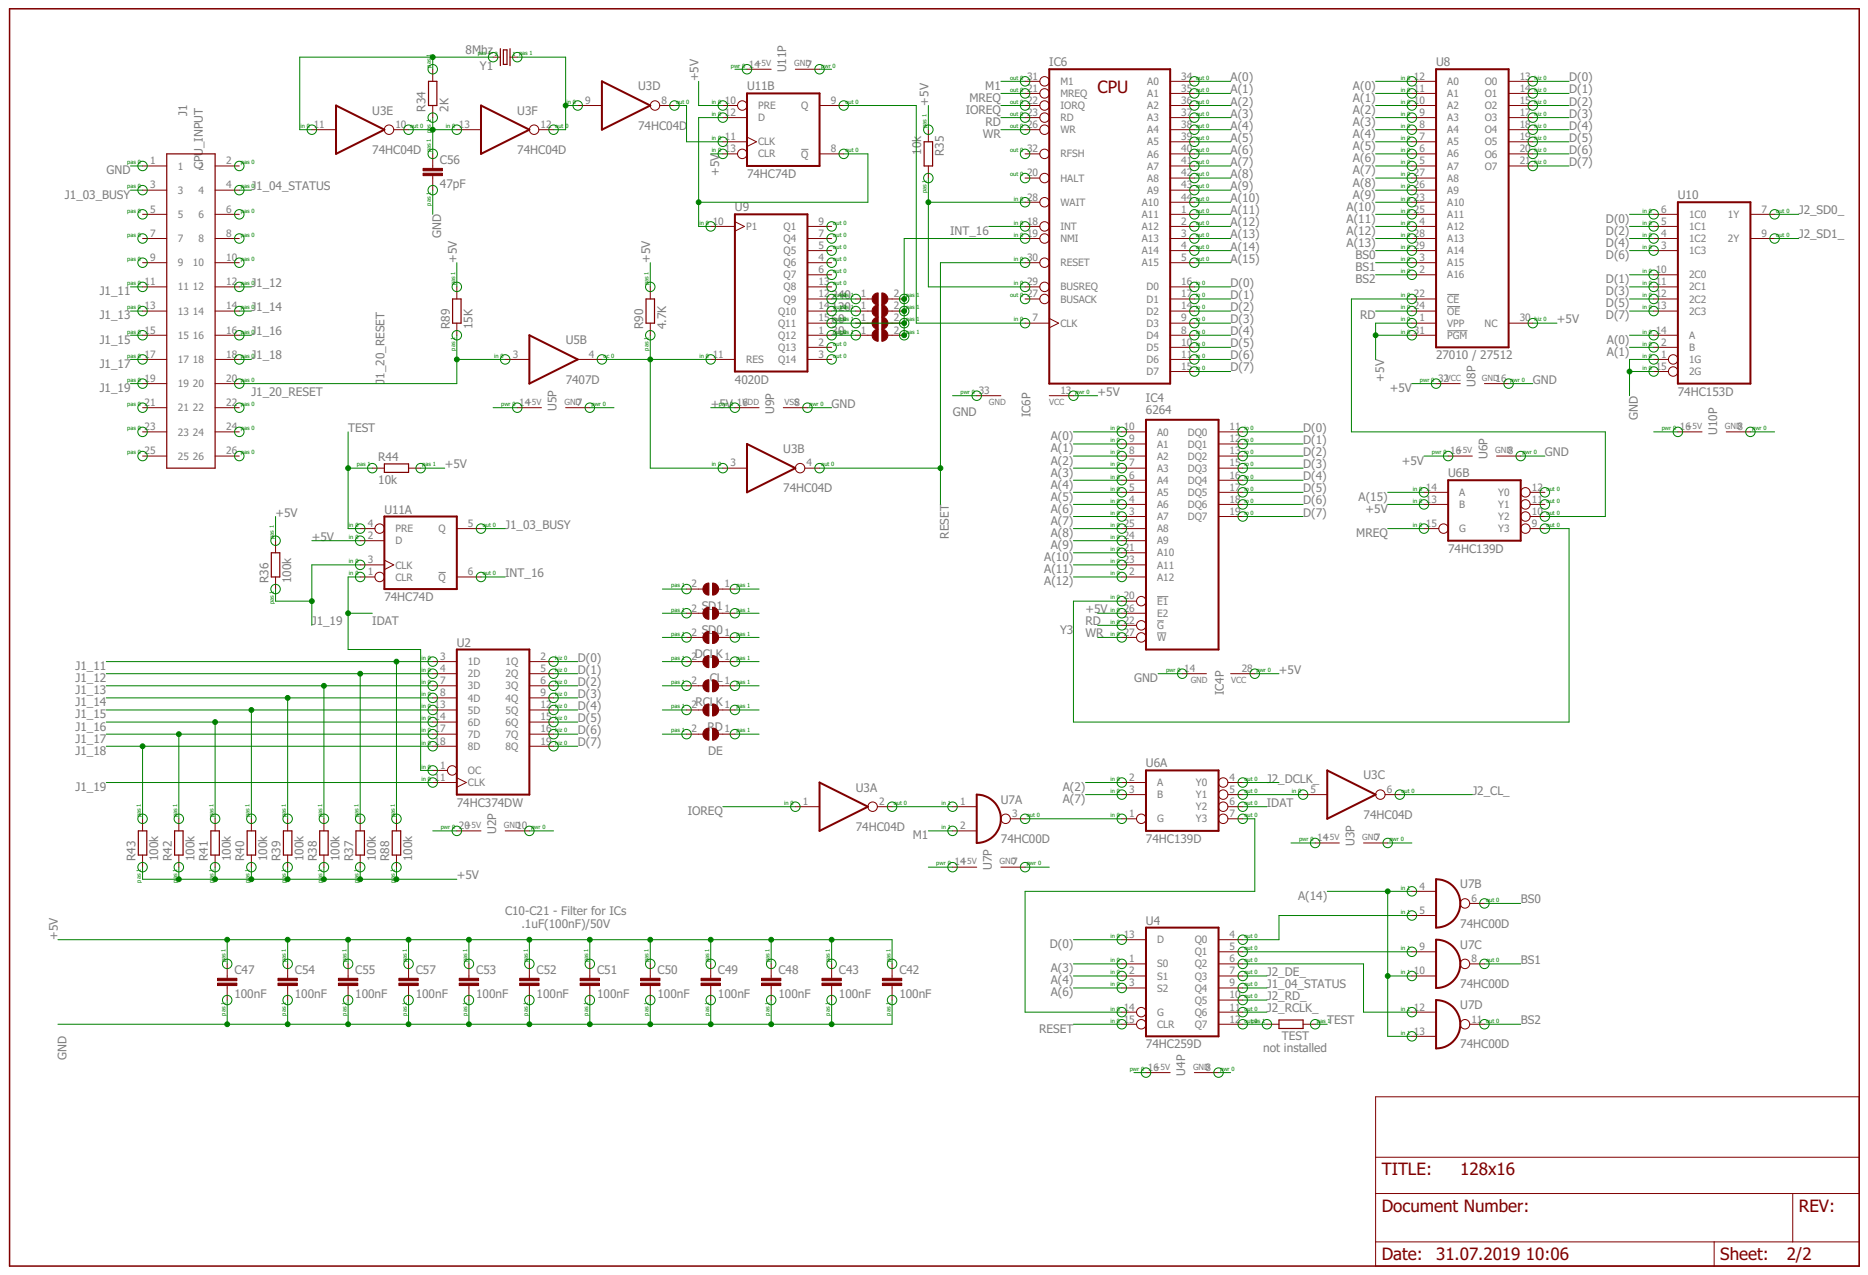
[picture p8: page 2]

pas 1 pas 1

Document Number: | REV:

Date: 31.07.2019 10:06 | Sheet: 2/2

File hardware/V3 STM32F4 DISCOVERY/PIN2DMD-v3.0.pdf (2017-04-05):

# 100n 100n 10K

# C13 C14 R³

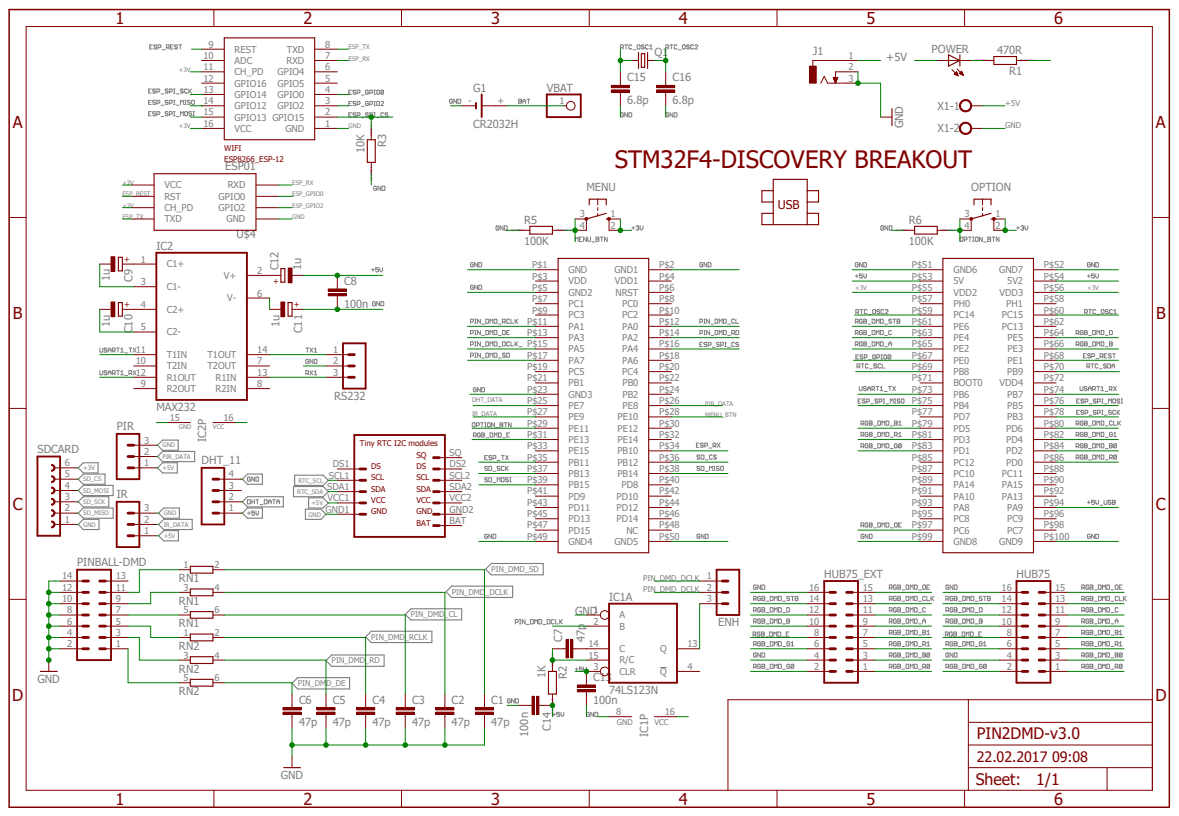
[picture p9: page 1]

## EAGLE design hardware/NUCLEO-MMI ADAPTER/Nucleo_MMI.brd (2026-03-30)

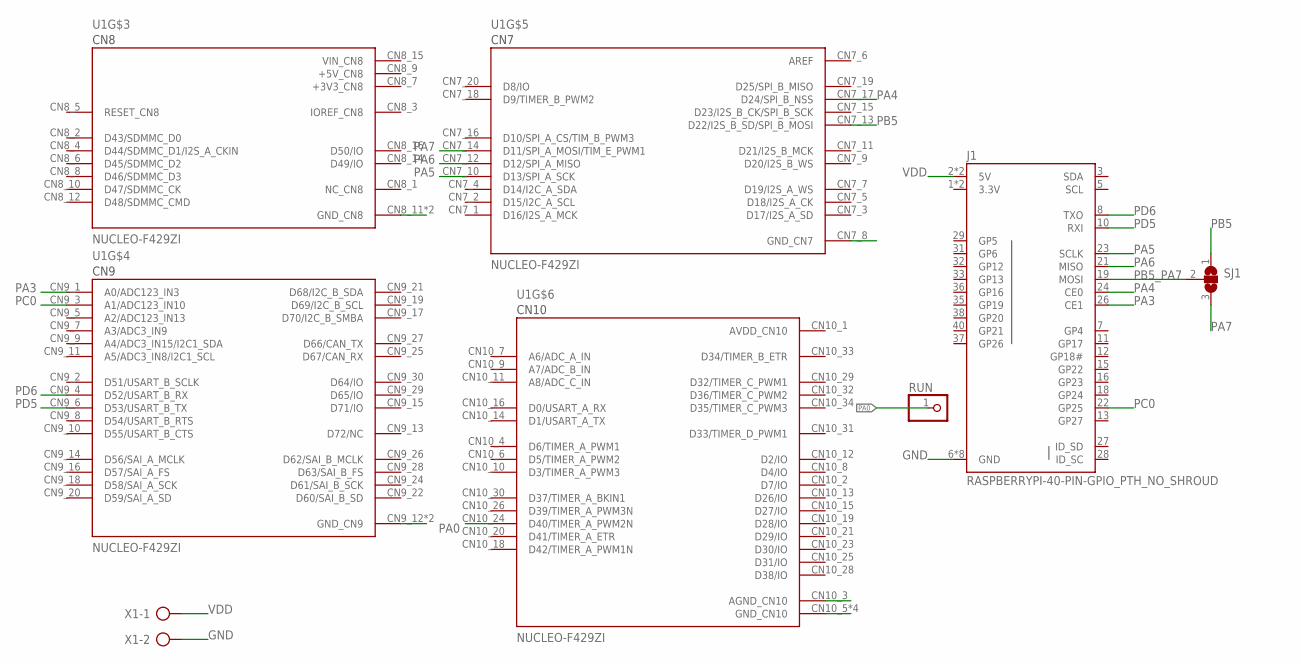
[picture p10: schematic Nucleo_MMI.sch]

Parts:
J1: RASPBERRYPI-40-PIN-GPIO_PTH_NO_SHROUD; 2X20
RUN: PINHD-1X1; 1X01
SJ1: SJ2W; SJ_2
U1: NUCLEO-F429ZI; MODULE_NUCLEO-F429ZI
X1: AK500/2-H

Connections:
3.3V: J1.1 (3.3V), J1.17 (3.3V)
+3V3_CN8: U1.CN8_7 (+3V3_CN8)
+5V_CN8: U1.CN8_9 (+5V_CN8)
AREF: U1.CN7_6 (AREF)
AVDD_CN10: U1.CN10_1 (AVDD_CN10)
GND: J1.6 (GND), J1.9 (GND), J1.14 (GND), J1.20 (GND), J1.25 (GND), J1.30 (GND), J1.34 (GND), J1.39 (GND), U1.CN7_8 (GND_CN7), U1.CN8_11 (GND_CN8), U1.CN8_13 (GND_CN8), U1.CN9_12 (GND_CN9), U1.CN9_23 (GND_CN9), U1.CN10_3 (AGND_CN10), U1.CN10_5 (GND_CN10), U1.CN10_17 (GND_CN10), U1.CN10_22 (GND_CN10), U1.CN10_27 (GND_CN10), X1.2
PA0: RUN.1, U1.CN10_24 (D40/TIMER_A_PWM2N)
PA3: J1.26 (CE1), U1.CN9_1 (A0/ADC123_IN3)
PA4: J1.24 (CE0), U1.CN7_17 (D24/SPI_B_NSS)
PA5: J1.23 (SCLK), U1.CN7_10 (D13/SPI_A_SCK)
PA6: J1.21 (MISO), U1.CN7_12 (D12/SPI_A_MISO)
PA7: SJ1.3, U1.CN7_14 (D11/SPI_A_MOSI/TIM_E_PWM1)
PB5: SJ1.1, U1.CN7_13 (D22/I2S_B_SD/SPI_B_MOSI)
PB5_PA7: J1.19 (MOSI), SJ1.2
PC0: J1.22 (GP25), U1.CN9_3 (A1/ADC123_IN10)
PD5: J1.10 (RXI), U1.CN9_6 (D53/USART_B_TX)
PD6: J1.8 (TXO), U1.CN9_4 (D52/USART_B_RX)
VDD: J1.2 (5V), J1.4 (5V), X1.1
VIN_CN8: U1.CN8_15 (VIN_CN8)

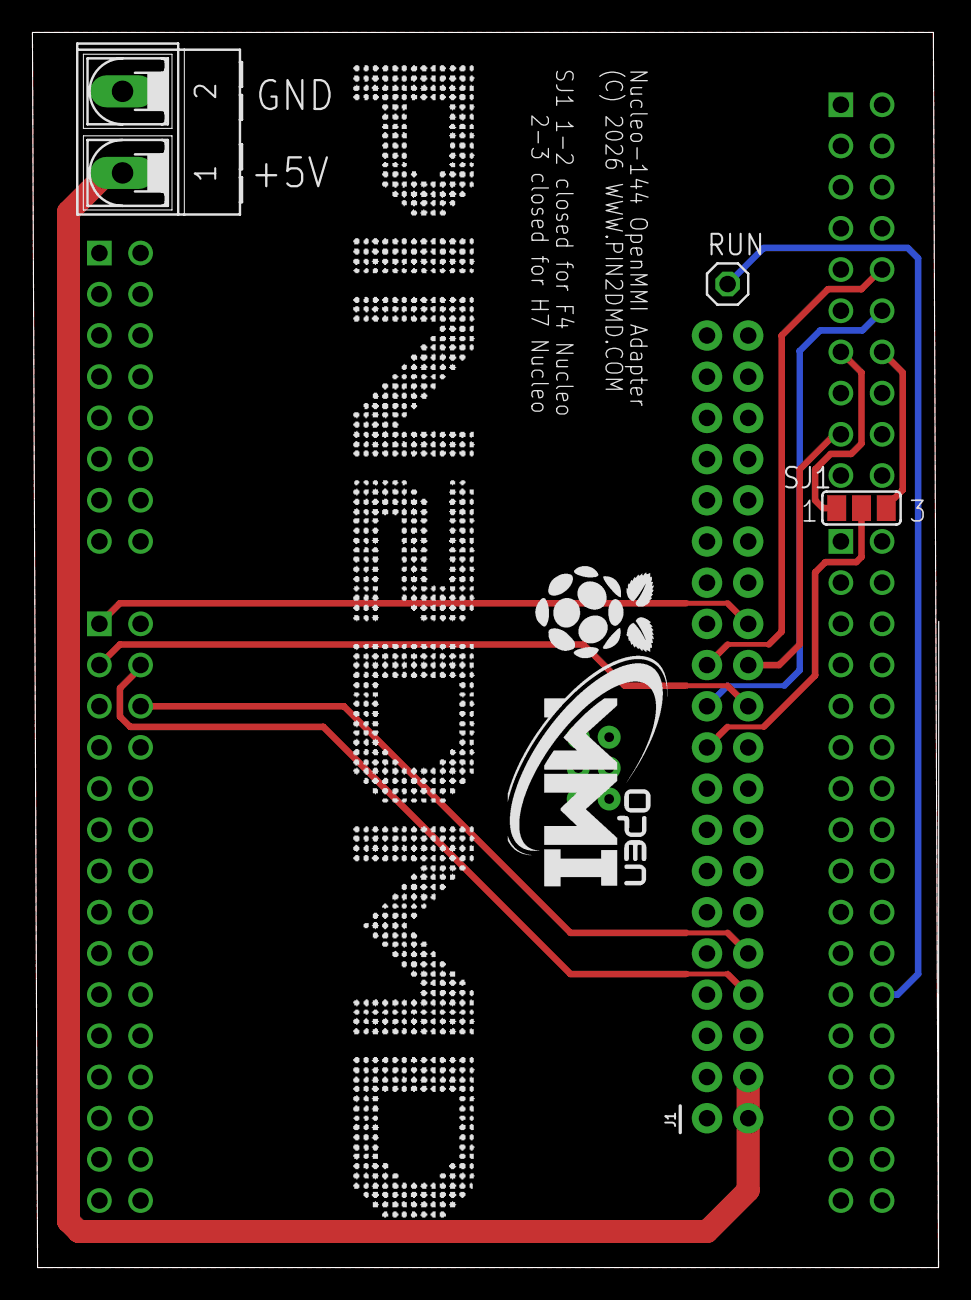
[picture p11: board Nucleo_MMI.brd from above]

Board: 2 copper layers, 55.9 x 76.2 mm, 5 parts (1 on the bottom side), 14 nets.

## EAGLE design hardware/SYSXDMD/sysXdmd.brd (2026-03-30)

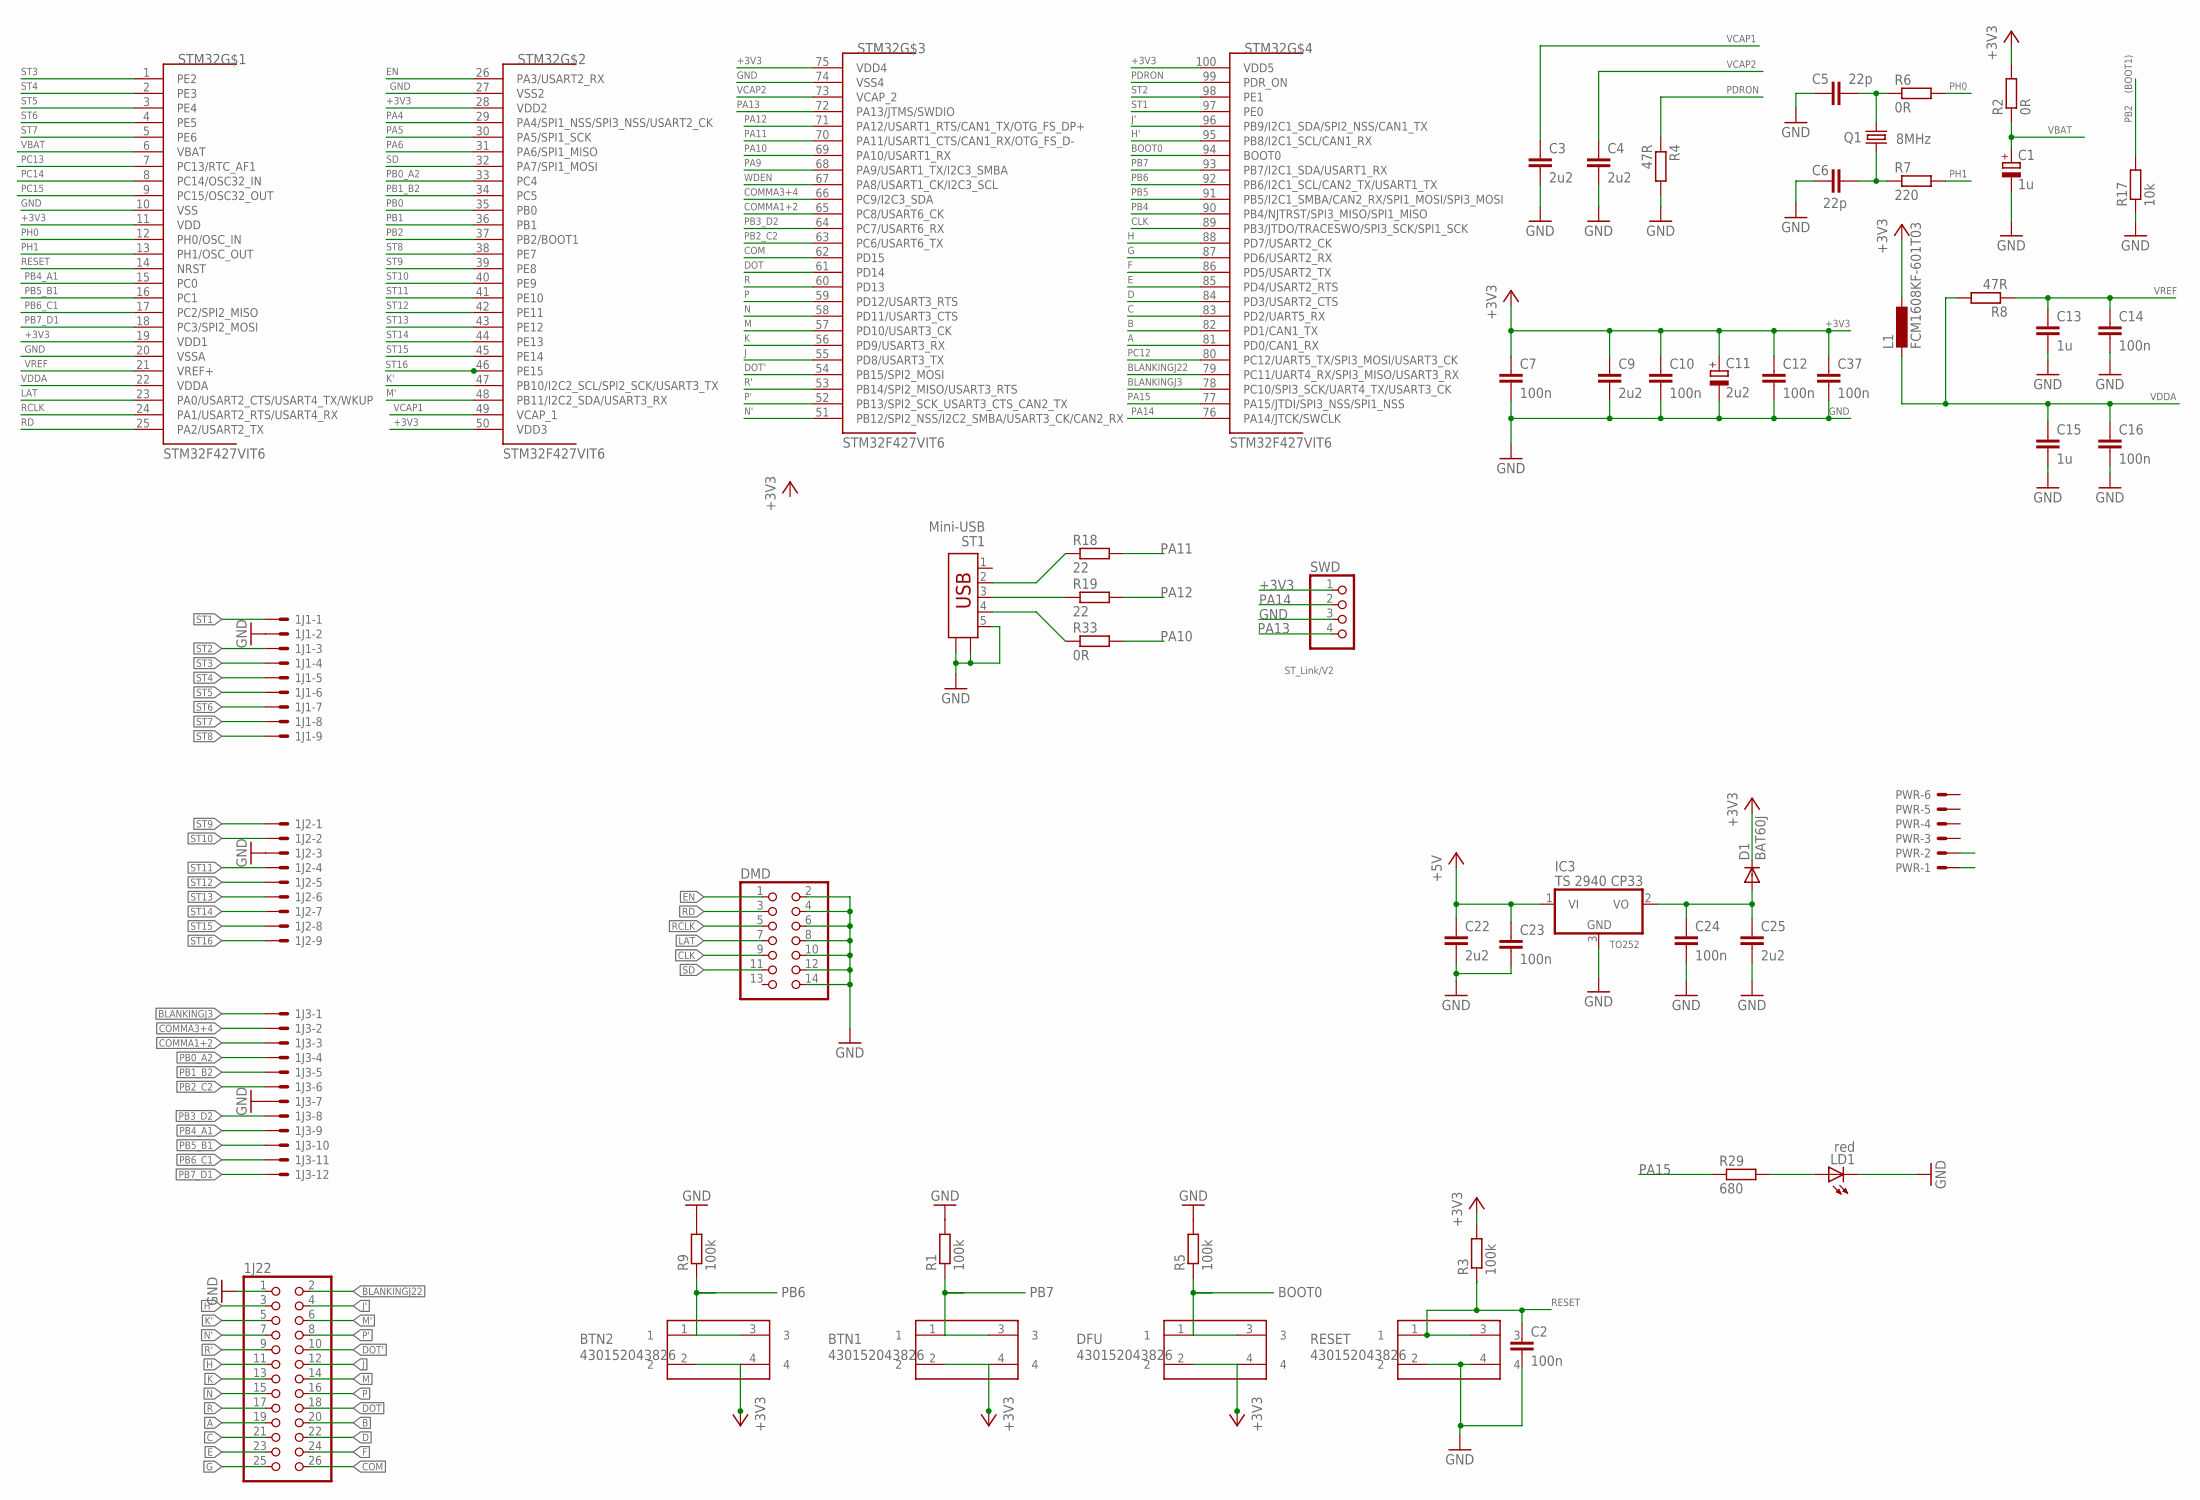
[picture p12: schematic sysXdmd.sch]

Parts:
1J1, 1J2: KK-156-9
1J3: KK-156-12
1J22: PINHD-2X13; 2X13
BTN1, BTN2: 430152043826
C1: 1u; CT3528
C2, C7, C10, C12, C14, C16, C23, C24, C37: 100n; C0805
C3, C4: 2u2; C0805
C5, C6: 22p; C0805
C9, C22, C25: 2u2; C1206
C11: 2u2; CT3528
C13, C15: 1u; C1206
D1: BAT60J; SOD323-W
DFU: 430152043826
DMD: PINHD-2X7; 2X07
IC3: TS 2940 CP33; TO252
L1: FCM1608KF-601T03; L0603
LD1: red; CHIP-LED0805
PWR: KK-156-6
Q1: 8MHz; HC49UP
R1, R3, R5, R9: 100k; R0805
R2, R6, R33: 0R; R0805
R4, R8: 47R; R0805
R7: 220; R0805
R17: 10k; R0805
R18, R19: 22; R0805
R29: 680; R0805
RESET: 430152043826
ST1: Mini-USB; USBMINI
STM32: STM32F427VIT6; LQFP100
SWD: PINHD-1X4; 1X04

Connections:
+3V3: BTN1.2, BTN1.4, BTN2.2, BTN2.4, C7.1, C9.1, C10.1, C11.+, C12.1, C37.1, D1.C, DFU.2, DFU.4, L1.1, R2.2, R3.2, STM32.11 (VDD), STM32.19 (VDD1), STM32.28 (VDD2), STM32.50 (VDD3), STM32.75 (VDD4), STM32.100 (VDD5), SWD.1
+5V: C22.1, C23.1, IC3.1 (VI), PWR.1
A: 1J22.19, STM32.81 (PD0/CAN1_RX)
B: 1J22.20, STM32.82 (PD1/CAN1_TX)
BLANKINGJ3: 1J3.1, STM32.78 (PC10/SPI3_SCK/UART4_TX/USART3_CK)
BLANKINGJ22: 1J22.2, STM32.79 (PC11/UART4_RX/SPI3_MISO/USART3_RX)
BOOT0: DFU.1, DFU.3, R5.1, STM32.94 (BOOT0)
C: 1J22.21, STM32.83 (PD2/UART5_RX)
CLK: DMD.9, STM32.89 (PB3/JTDO/TRACESWO/SPI3_SCK/SPI1_SCK)
COM: 1J22.26, STM32.62 (PD15)
COMMA1+2: 1J3.3, STM32.65 (PC8/USART6_CK)
COMMA3+4: 1J3.2, STM32.66 (PC9/I2C3_SDA)
D: 1J22.22, STM32.84 (PD3/USART2_CTS)
DOT: 1J22.18, STM32.61 (PD14)
DOT': 1J22.10, STM32.54 (PB15/SPI2_MOSI)
E: 1J22.23, STM32.85 (PD4/USART2_RTS)
EN: DMD.1, STM32.26 (PA3/USART2_RX)
F: 1J22.24, STM32.86 (PD5/USART2_TX)
G: 1J22.25, STM32.87 (PD6/USART2_RX)
GND: 1J1.2, 1J2.3, 1J3.7, 1J22.1, C1.-, C2.2, C3.2, C4.2, C5.2, C6.2, C7.2, C9.2, C10.2, C11.-, C12.2, C13.2, C14.2, C15.2, C16.2, C22.2, C23.2, C24.2, C25.2, C37.2, DMD.2, DMD.4, DMD.6, DMD.8, DMD.10, DMD.12, DMD.14, IC3.3 (GND), LD1.C, PWR.2, R1.2, R4.2, R5.2, R9.2, R17.1, RESET.2, RESET.4, ST1.5, ST1.N1, ST1.N2, STM32.10 (VSS), STM32.20 (VSSA), STM32.27 (VSS2), STM32.74 (VSS4), SWD.3
H: 1J22.11, STM32.88 (PD7/USART2_CK)
H': 1J22.3, STM32.95 (PB8/I2C1_SCL/CAN1_RX)
J: 1J22.12, STM32.55 (PD8/USART3_TX)
J': 1J22.4, STM32.96 (PB9/I2C1_SDA/SPI2_NSS/CAN1_TX)
K: 1J22.13, STM32.56 (PD9/USART3_RX)
K': 1J22.5, STM32.47 (PB10/I2C2_SCL/SPI2_SCK/USART3_TX)
LAT: DMD.7, STM32.23 (PA0/USART2_CTS/USART4_TX/WKUP)
M: 1J22.14, STM32.57 (PD10/USART3_CK)
M': 1J22.6, STM32.48 (PB11/I2C2_SDA/USART3_RX)
N: 1J22.15, STM32.58 (PD11/USART3_CTS)
unnamed: C5.1, Q1.2, R6.1
unnamed: C6.1, Q1.1, R7.1
unnamed: C24.1, C25.1, D1.A, IC3.2 (VO)
unnamed: LD1.A, R29.2
unnamed: R33.1, ST1.4
unnamed: R19.1, ST1.3
unnamed: R18.1, ST1.2
N': 1J22.7, STM32.51 (PB12/SPI2_NSS/I2C2_SMBA/USART3_CK/CAN2_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)
P: 1J22.16, STM32.59 (PD12/USART3_RTS)
P': 1J22.8, STM32.52 (PB13/SPI2_SCK_USART3_CTS_CAN2_TX)
PA4: STM32.29 (PA4/SPI1_NSS/SPI3_NSS/USART2_CK)
PA5: STM32.30 (PA5/SPI1_SCK)
PA6: STM32.31 (PA6/SPI1_MISO)
PA9: STM32.68 (PA9/USART1_TX/I2C3_SMBA)
PA10: R33.2, STM32.69 (PA10/USART1_RX)
PA11: R18.2, STM32.70 (PA11/USART1_CTS/CAN1_RX/OTG_FS_D-)
PA12: R19.2, STM32.71 (PA12/USART1_RTS/CAN1_TX/OTG_FS_DP+)
PA13: STM32.72 (PA13/JTMS/SWDIO), SWD.4
PA14: STM32.76 (PA14/JTCK/SWCLK), SWD.2
PA15: R29.1, STM32.77 (PA15/JTDI/SPI3_NSS/SPI1_NSS)
PB0: STM32.35 (PB0)
PB0_A2: 1J3.4, STM32.33 (PC4)
PB1: STM32.36 (PB1)
PB1_B2: 1J3.5, STM32.34 (PC5)
PB2: R17.2, STM32.37 (PB2/BOOT1)
PB2_C2: 1J3.6, STM32.63 (PC6/USART6_TX)
PB3_D2: 1J3.8, STM32.64 (PC7/USART6_RX)
PB4: STM32.90 (PB4/NJTRST/SPI3_MISO/SPI1_MISO)
PB4_A1: 1J3.9, STM32.15 (PC0)
PB5: STM32.91 (PB5/I2C1_SMBA/CAN2_RX/SPI1_MOSI/SPI3_MO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)
PB5_B1: 1J3.10, STM32.16 (PC1)
PB6: BTN2.1, BTN2.3, R9.1, STM32.92 (PB6/I2C1_SCL/CAN2_TX/USART1_TX)
PB6_C1: 1J3.11, STM32.17 (PC2/SPI2_MISO)
PB7: BTN1.1, BTN1.3, R1.1, STM32.93 (PB7/I2C1_SDA/USART1_RX)
PB7_D1: 1J3.12, STM32.18 (PC3/SPI2_MOSI)
PC12: STM32.80 (PC12/UART5_TX/SPI3_MOSI/USART3_CK)
PC13: STM32.7 (PC13/RTC_AF1)
PC14: STM32.8 (PC14/OSC32_IN)
PC15: STM32.9 (PC15/OSC32_OUT)
PDRON: R4.1, STM32.99 (PDR_ON)
PH0: R6.2, STM32.12 (PH0/OSC_IN)
PH1: R7.2, STM32.13 (PH1/OSC_OUT)
R: 1J22.17, STM32.60 (PD13)
R': 1J22.9, STM32.53 (PB14/SPI2_MISO/USART3_RTS)
RCLK: DMD.5, STM32.24 (PA1/USART2_RTS/USART4_RX)
RD: DMD.3, STM32.25 (PA2/USART2_TX)
RESET: C2.1, R3.1, RESET.1, RESET.3, STM32.14 (NRST)
SD: DMD.11, STM32.32 (PA7/SPI1_MOSI)
ST1: 1J1.1, STM32.97 (PE0)
ST2: 1J1.3, STM32.98 (PE1)
ST3: 1J1.4, STM32.1 (PE2)
ST4: 1J1.5, STM32.2 (PE3)
ST5: 1J1.6, STM32.3 (PE4)
ST6: 1J1.7, STM32.4 (PE5)
ST7: 1J1.8, STM32.5 (PE6)
ST8: 1J1.9, STM32.38 (PE7)
ST9: 1J2.1, STM32.39 (PE8)
ST10: 1J2.2, STM32.40 (PE9)
ST11: 1J2.4, STM32.41 (PE10)
ST12: 1J2.5, STM32.42 (PE11)
ST13: 1J2.6, STM32.43 (PE12)
ST14: 1J2.7, STM32.44 (PE13)
ST15: 1J2.8, STM32.45 (PE14)
ST16: 1J2.9, STM32.46 (PE15)
VBAT: C1.+, R2.1, STM32.6 (VBAT)
VCAP1: C3.1, STM32.49 (VCAP_1)
VCAP2: C4.1, STM32.73 (VCAP_2)
VDDA: C15.1, C16.1, L1.2, R8.2, STM32.22 (VDDA)
VREF: C13.1, C14.1, R8.1, STM32.21 (VREF+)
WDEN: STM32.67 (PA8/USART1_CK/I2C3_SCL)

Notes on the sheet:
TO252
(BOOT1)
ST_Link/V2

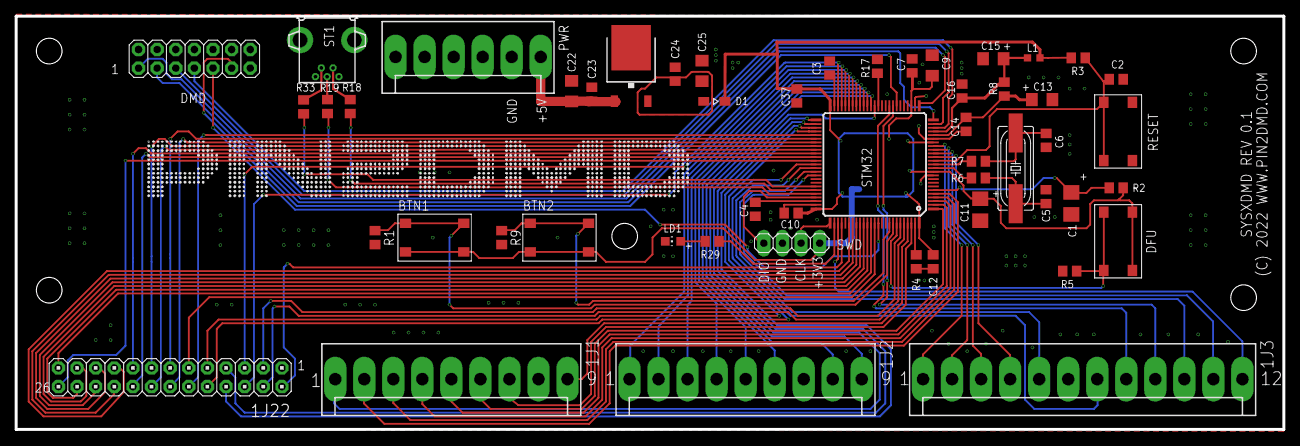
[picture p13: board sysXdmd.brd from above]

Board: 2 copper layers, 172.9 x 56.4 mm, 52 parts (0 on the bottom side), 87 nets.

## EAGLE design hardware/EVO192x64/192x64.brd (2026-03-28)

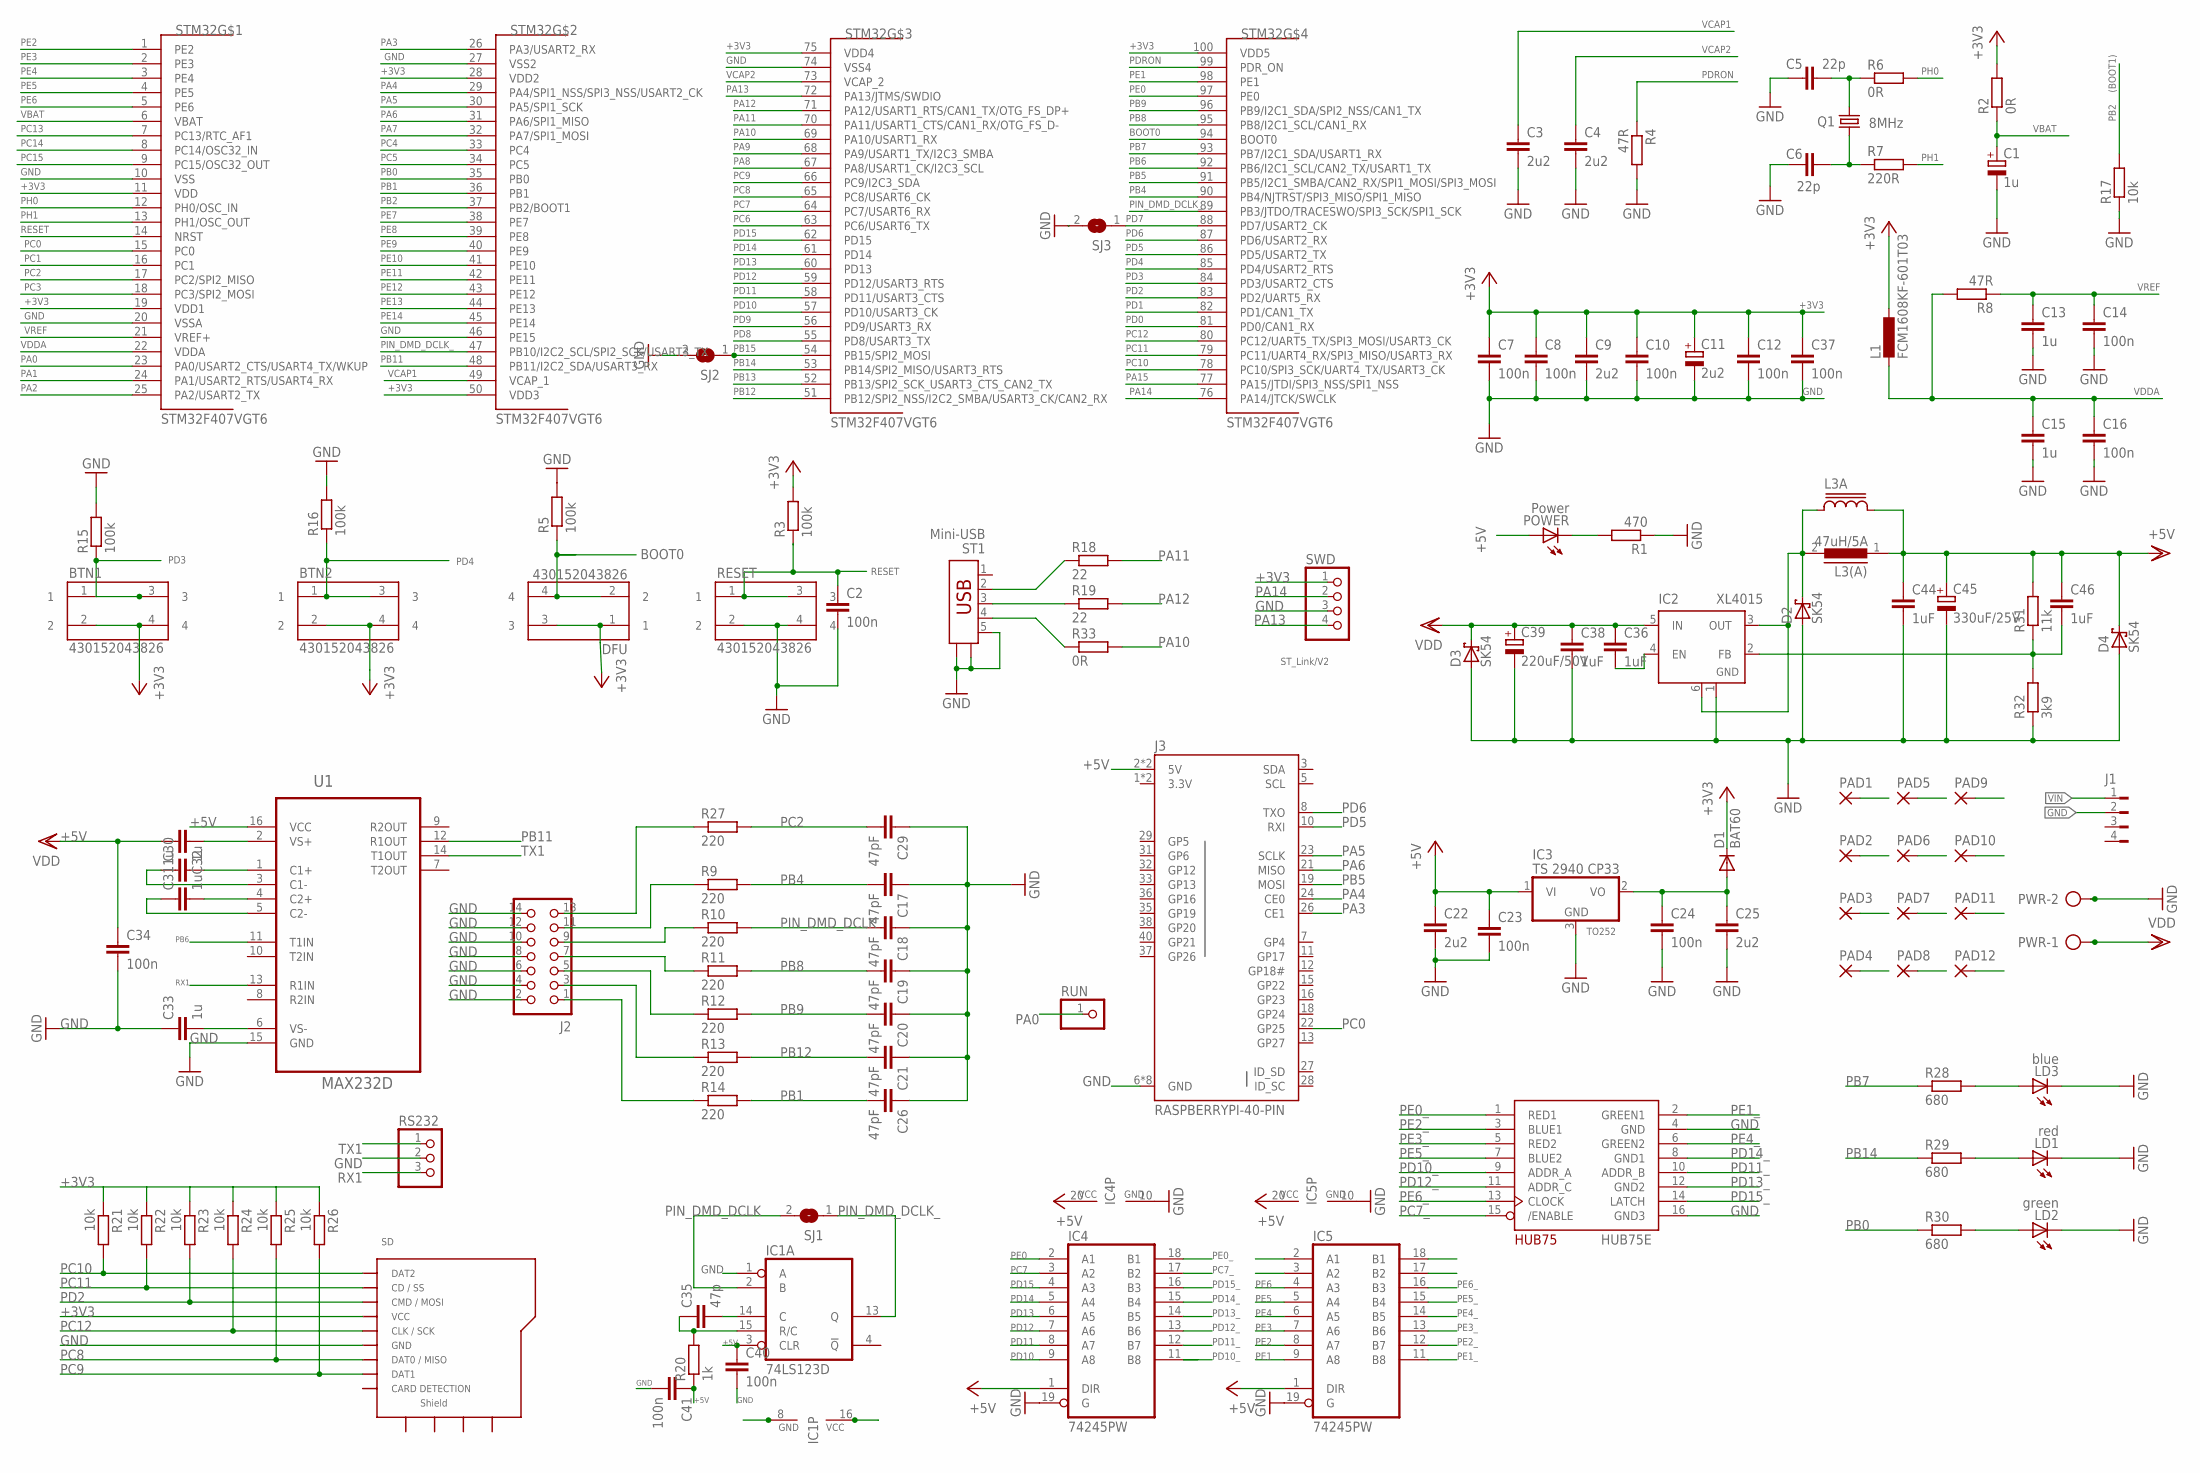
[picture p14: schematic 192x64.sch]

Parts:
BTN1, BTN2: 430152043826
C1: 1u; CT3528
C2, C7, C8, C10, C12, C14, C16, C23, C24, C34, C37, C40, C41: 100n; C0805
C3, C4: 2u2; C0805
C5, C6: 22p; C0805
C9, C22, C25: 2u2; C1206
C11: 2u2; CT3528
C13, C15: 1u; C1206
C17, C18, C19, C20, C21, C26, C29: 47pF; C0805
C30, C31, C32, C33: 1u; C0805
C35: 47p; C0805
C36, C38, C44, C46: 1uF; C1206
C39: 220uF/50V; PANASONIC_G
C45: 330uF/25V; PANASONIC_G
D1: BAT60; SOD323-W
D2, D3, D4: SK54; SMB
DFU: 430152043826
HUB75E: RGB; 2X08-IDC
IC1: 74LS123D; SO16
IC2: XL4015; TO263-5
IC3: TS 2940 CP33; TO252
IC4, IC5: 74245PW; TSSOP20
J1: FLOPPY-4
J2: CON_HEADER_2X07-PTH-SHROUDED; PINSHRD_PTH_2X07
J3: RASPBERRYPI-40-PIN; 2X20
L1: FCM1608KF-601T03; L2012C
L3(A): 47uH/5A; ED16
L3A: SRR1206
LD1: red; CHIP-LED0805
LD2: green; CHIP-LED0805
LD3: blue; CHIP-LED0805
PAD1, PAD2, PAD3, PAD4, PAD5, PAD6, PAD7, PAD8, PAD9, PAD10, PAD11, PAD12: SMD5; SMD2,54-5,08
POWER: Power; CHIPLED_0805
PWR: AK500/2-H
Q1: 8MHz; HC49UP
R1: 470; R0805
R2, R6, R33: 0R; R0805
R3, R5, R15, R16: 100k; R0805
R4, R8: 47R; R0805
R7: 220R; R0805
R9, R10, R11, R12, R13, R14, R27: 220; R0805
R17, R21, R22, R23, R24, R25, R26: 10k; R0805
R18, R19: 22; R0805
R20: 1k; R0805
R28, R29, R30: 680; R0805
R31: 11k; R1206
R32: 3k9; R1206
RESET: 430152043826
RS232: PINHD-1X3; 1X03
RUN: PINHD-1X1; 1X01
SD: MICROSD_CARD_POLLIN; MR**-AP*03**
SJ1, SJ2, SJ3: SJ
ST1: Mini-USB; USBMINI
STM32: STM32F407VGT6; LQFP100
SWD: PINHD-1X4; 1X04
U1: MAX232D; SOIC127P600X175-16N

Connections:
3.3V: J3.1 (3.3V), J3.17 (3.3V)
+3V3: BTN1.2, BTN1.4, BTN2.2, BTN2.4, C7.1, C8.1, C9.1, C10.1, C11.+, C12.1, C37.1, D1.C, DFU.1, DFU.3, L1.1, R2.2, R3.2, R21.1, R22.1, R23.1, R24.1, R25.1, R26.1, SD.VCC, STM32.11 (VDD), STM32.19 (VDD1), STM32.28 (VDD2), STM32.50 (VDD3), STM32.75 (VDD4), STM32.100 (VDD5), SWD.1
+5V: C22.1, C23.1, C32.2, C34.1, C40.1, C41.1, C44.1, C45.+, C46.1, D4.C, IC1.3 (CLR), IC1.16 (VCC), IC3.1 (VI), IC4.1 (DIR), IC4.20 (VCC), IC5.1 (DIR), IC5.20 (VCC), J3.2 (5V), J3.4 (5V), L3(A).1, L3A.2, PAD1.1, PAD2.1, PAD5.1, PAD6.1, PAD9.1, PAD10.1, POWER.A, R20.1, R31.2, U1.16 (VCC)
BOOT0: DFU.2, DFU.4, R5.1, STM32.94 (BOOT0)
GND: C1.-, C2.2, C3.2, C4.2, C5.2, C6.2, C7.2, C8.2, C9.2, C10.2, C11.-, C12.2, C13.2, C14.2, C15.2, C16.2, C17.1, C18.1, C19.1, C20.1, C21.1, C22.2, C23.2, C24.2, C25.2, C26.1, C29.1, C33.1, C34.2, C37.2, C38.2, C39.-, C40.2, C41.2, C44.2, C45.-, D2.A, D3.A, D4.A, HUB75E.4 (GND), HUB75E.16 (GND3), IC1.1 (A), IC1.8 (GND), IC2.1 (GND), IC3.3 (GND), IC4.10 (GND), IC4.19 (G), IC5.2 (A1), IC5.3 (A2), IC5.10 (GND), IC5.19 (G), J1.2, J2.2, J2.4, J2.6, J2.8, J2.10, J2.12, J2.14, J3.6 (GND), J3.9 (GND), J3.14 (GND), J3.20 (GND), J3.25 (GND), J3.30 (GND), J3.34 (GND), J3.39 (GND), LD1.C, LD2.C, LD3.C, PAD3.1, PAD4.1, PAD7.1, PAD8.1, PAD11.1, PAD12.1, PWR.2, R1.1, R4.2, R5.2, R15.2, R16.2, R17.1, R32.1, RESET.2, RESET.4, RS232.2, SD.GND, SJ2.2, SJ3.2, ST1.5, ST1.N1, ST1.N2, STM32.10 (VSS), STM32.20 (VSSA), STM32.27 (VSS2), STM32.46 (PE15), STM32.74 (VSS4), SWD.3, U1.15 (GND)
unnamed: C5.1, Q1.2, R6.1
unnamed: C6.1, Q1.1, R7.1
unnamed: POWER.C, R1.2
unnamed: J2.13, R27.1
unnamed: J2.11, R9.1
unnamed: J2.9, R10.1
unnamed: J2.7, R11.1
unnamed: J2.5, R12.1
unnamed: J2.3, R13.1
unnamed: C35.1, IC1.15 (R/C), R20.2
unnamed: J2.1, R14.1
unnamed: C24.1, C25.1, D1.A, IC3.2 (VO)
unnamed: C30.2, U1.1 (C1+)
unnamed: C30.1, U1.3 (C1-)
unnamed: C31.2, U1.4 (C2+)
unnamed: C31.1, U1.5 (C2-)
unnamed: C33.2, U1.6 (VS-)
unnamed: C32.1, U1.2 (VS+)
unnamed: LD1.A, R29.2
unnamed: D2.C, IC2.3 (OUT), IC2.6 (TAB), L3(A).2, L3A.1
unnamed: C46.2, IC2.2 (FB), R31.1, R32.2
unnamed: C35.2, IC1.14 (C)
unnamed: LD3.A, R28.2
unnamed: C36.2, IC2.4 (EN)
unnamed: R33.1, ST1.4
unnamed: LD2.A, R30.2
unnamed: R19.1, ST1.3
unnamed: R18.1, ST1.2
PA0: RUN.1, STM32.23 (PA0/USART2_CTS/USART4_TX/WKUP)
PA1: STM32.24 (PA1/USART2_RTS/USART4_RX)
PA2: STM32.25 (PA2/USART2_TX)
PA3: J3.26 (CE1), STM32.26 (PA3/USART2_RX)
PA4: J3.24 (CE0), STM32.29 (PA4/SPI1_NSS/SPI3_NSS/USART2_CK)
PA5: J3.23 (SCLK), STM32.30 (PA5/SPI1_SCK)
PA6: J3.21 (MISO), STM32.31 (PA6/SPI1_MISO)
PA7: STM32.32 (PA7/SPI1_MOSI)
PA8: STM32.67 (PA8/USART1_CK/I2C3_SCL)
PA9: STM32.68 (PA9/USART1_TX/I2C3_SMBA)
PA10: R33.2, STM32.69 (PA10/USART1_RX)
PA11: R18.2, STM32.70 (PA11/USART1_CTS/CAN1_RX/OTG_FS_D-)
PA12: R19.2, STM32.71 (PA12/USART1_RTS/CAN1_TX/OTG_FS_DP+)
PA13: STM32.72 (PA13/JTMS/SWDIO), SWD.4
PA14: STM32.76 (PA14/JTCK/SWCLK), SWD.2
PA15: STM32.77 (PA15/JTDI/SPI3_NSS/SPI1_NSS)
PB0: R30.1, STM32.35 (PB0)
PB1: C26.2, R14.2, STM32.36 (PB1)
PB2: R17.2, STM32.37 (PB2/BOOT1)
PB4: C17.2, R9.2, STM32.90 (PB4/NJTRST/SPI3_MISO/SPI1_MISO)
PB5: J3.19 (MOSI), STM32.91 (PB5/I2C1_SMBA/CAN2_RX/SPI1_MOSI/SPI3_MO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)
PB6: STM32.92 (PB6/I2C1_SCL/CAN2_TX/USART1_TX), U1.11 (T1IN)
PB7: R28.1, STM32.93 (PB7/I2C1_SDA/USART1_RX)
PB8: C19.2, R11.2, STM32.95 (PB8/I2C1_SCL/CAN1_RX)
PB9: C20.2, R12.2, STM32.96 (PB9/I2C1_SDA/SPI2_NSS/CAN1_TX)
PB11: STM32.48 (PB11/I2C2_SDA/USART3_RX), U1.12 (R1OUT)
PB12: C21.2, R13.2, STM32.51 (PB12/SPI2_NSS/I2C2_SMBA/USART3_CK/CAN2_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)
PB13: STM32.52 (PB13/SPI2_SCK_USART3_CTS_CAN2_TX)
PB14: R29.1, STM32.53 (PB14/SPI2_MISO/USART3_RTS)
PB15: SJ2.1, STM32.54 (PB15/SPI2_MOSI)
PC0: J3.22 (GP25), STM32.15 (PC0)
PC1: STM32.16 (PC1)
PC2: C29.2, R27.2, STM32.17 (PC2/SPI2_MISO)
PC3: STM32.18 (PC3/SPI2_MOSI)
PC4: STM32.33 (PC4)
PC5: STM32.34 (PC5)
PC6: STM32.63 (PC6/USART6_TX)
PC7: IC4.3 (A2), STM32.64 (PC7/USART6_RX)
PC7_: HUB75E.15 (/ENABLE), IC4.17 (B2)
PC8: R25.2, SD.DAT0 (DAT0/MISO), STM32.65 (PC8/USART6_CK)
PC9: R26.2, SD.DAT1, STM32.66 (PC9/I2C3_SDA)
PC10: R21.2, SD.DAT2, STM32.78 (PC10/SPI3_SCK/UART4_TX/USART3_CK)
PC11: R22.2, SD.DAT3/CS (CD/SS), STM32.79 (PC11/UART4_RX/SPI3_MISO/USART3_RX)
PC12: R24.2, SD.CLK (CLK/SCK), STM32.80 (PC12/UART5_TX/SPI3_MOSI/USART3_CK)
PC13: STM32.7 (PC13/RTC_AF1)
PC14: STM32.8 (PC14/OSC32_IN)
PC15: STM32.9 (PC15/OSC32_OUT)
PD0: STM32.81 (PD0/CAN1_RX)
PD1: STM32.82 (PD1/CAN1_TX)
PD2: R23.2, SD.CMD (CMD/MOSI), STM32.83 (PD2/UART5_RX)
PD3: BTN1.1, BTN1.3, R15.1, STM32.84 (PD3/USART2_CTS)
PD4: BTN2.1, BTN2.3, R16.1, STM32.85 (PD4/USART2_RTS)
PD5: J3.10 (RXI), STM32.86 (PD5/USART2_TX)
PD6: J3.8 (TXO), STM32.87 (PD6/USART2_RX)
PD7: SJ3.1, STM32.88 (PD7/USART2_CK)
PD8: STM32.55 (PD8/USART3_TX)
PD9: STM32.56 (PD9/USART3_RX)
PD10: IC4.9 (A8), STM32.57 (PD10/USART3_CK)
PD10_: HUB75E.9 (ADDR_A), IC4.11 (B8)
PD11: IC4.8 (A7), STM32.58 (PD11/USART3_CTS)
PD11_: HUB75E.10 (ADDR_B), IC4.12 (B7)
PD12: IC4.7 (A6), STM32.59 (PD12/USART3_RTS)
PD12_: HUB75E.11 (ADDR_C), IC4.13 (B6)
PD13: IC4.6 (A5), STM32.60 (PD13)
PD13_: HUB75E.12 (GND2), IC4.14 (B5)
PD14: IC4.5 (A4), STM32.61 (PD14)
PD14_: HUB75E.8 (GND1), IC4.15 (B4)
PD15: IC4.4 (A3), STM32.62 (PD15)
PD15_: HUB75E.14 (LATCH), IC4.16 (B3)
PDRON: R4.1, STM32.99 (PDR_ON)
PE0: IC4.2 (A1), STM32.97 (PE0)
PE0_: HUB75E.1 (RED1), IC4.18 (B1)
PE1: IC5.9 (A8), STM32.98 (PE1)
PE1_: HUB75E.2 (GREEN1), IC5.11 (B8)
PE2: IC5.8 (A7), STM32.1 (PE2)
PE2_: HUB75E.3 (BLUE1), IC5.12 (B7)
PE3: IC5.7 (A6), STM32.2 (PE3)
PE3_: HUB75E.5 (RED2), IC5.13 (B6)
PE4: IC5.6 (A5), STM32.3 (PE4)
PE4_: HUB75E.6 (GREEN2), IC5.14 (B5)
PE5: IC5.5 (A4), STM32.4 (PE5)
PE5_: HUB75E.7 (BLUE2), IC5.15 (B4)
PE6: IC5.4 (A3), STM32.5 (PE6)
PE6_: HUB75E.13 (CLOCK), IC5.16 (B3)
PE7: STM32.38 (PE7)
PE8: STM32.39 (PE8)
PE9: STM32.40 (PE9)
PE10: STM32.41 (PE10)
PE11: STM32.42 (PE11)
PE12: STM32.43 (PE12)
PE13: STM32.44 (PE13)
PE14: STM32.45 (PE14)
PH0: R6.2, STM32.12 (PH0/OSC_IN)
PH1: R7.2, STM32.13 (PH1/OSC_OUT)
PIN_DMD_DCLK: C18.2, IC1.2 (B), R10.2, SJ1.2
PIN_DMD_DCLK_: IC1.13 (Q), SJ1.1, STM32.47 (PB10/I2C2_SCL/SPI2_SCK/USART3_TX), STM32.89 (PB3/JTDO/TRACESWO/SPI3_SCK/SPI1_SCK)
RESET: C2.1, R3.1, RESET.1, RESET.3, STM32.14 (NRST)
RX1: RS232.3, U1.13 (R1IN)
TX1: RS232.1, U1.14 (T1OUT)
VBAT: C1.+, R2.1, STM32.6 (VBAT)
VCAP1: C3.1, STM32.49 (VCAP_1)
VCAP2: C4.1, STM32.73 (VCAP_2)
VDDA: C15.1, C16.1, L1.2, R8.2, STM32.22 (VDDA)
VIN: C36.1, C38.1, C39.+, D3.C, IC2.5 (IN), J1.1, PWR.1
VREF: C13.1, C14.1, R8.1, STM32.21 (VREF+)

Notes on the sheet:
TO252
(BOOT1)
ST_Link/V2

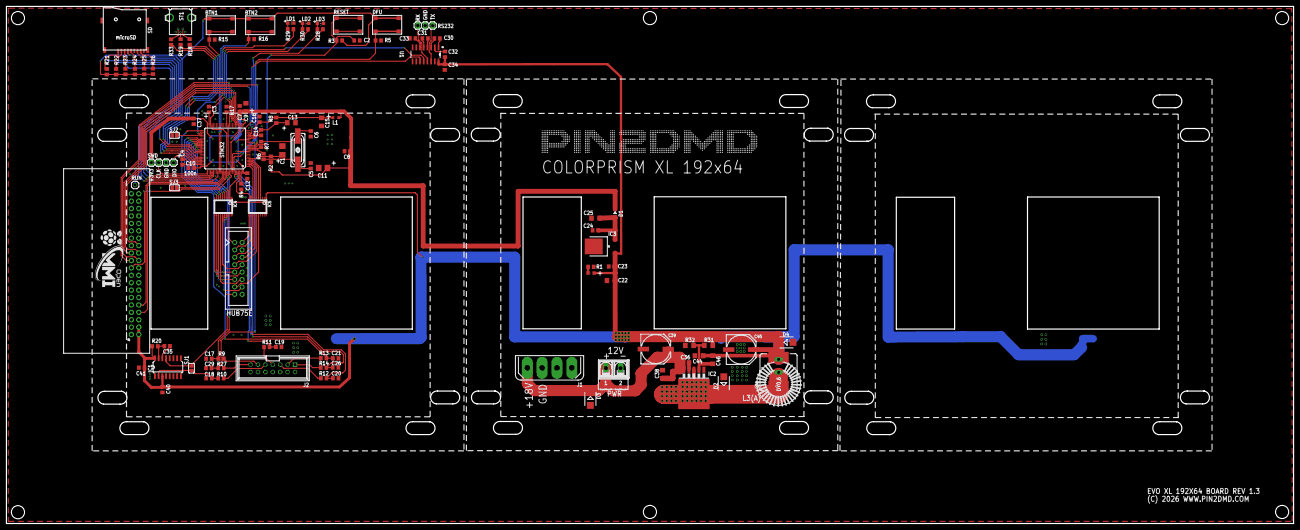
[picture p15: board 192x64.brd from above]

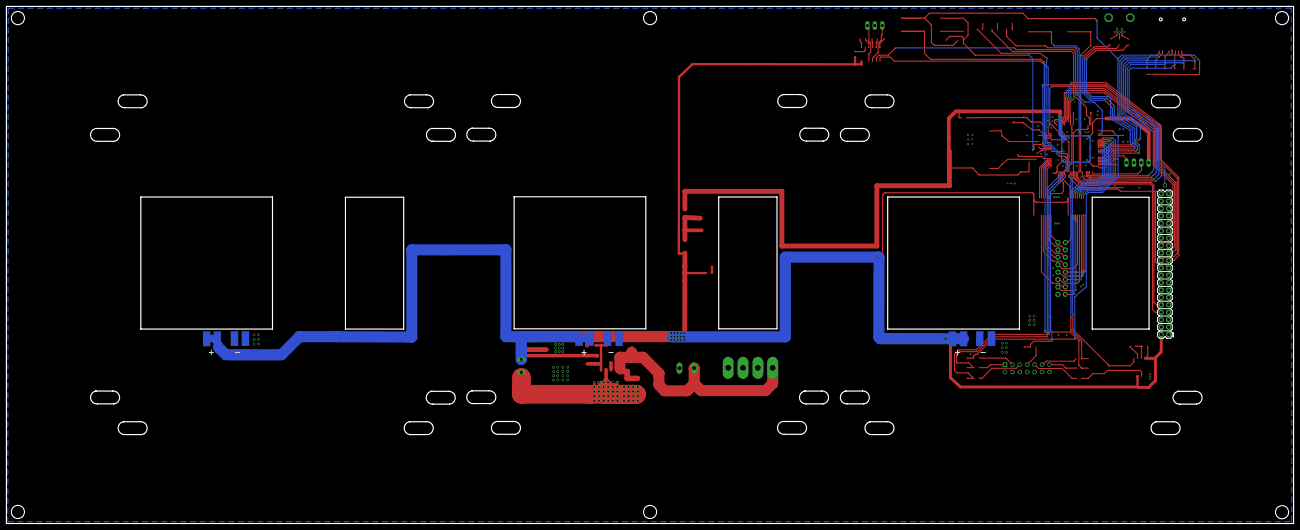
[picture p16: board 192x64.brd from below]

Board: 2 copper layers, 441.1 x 177.2 mm, 123 parts (13 on the bottom side), 111 nets.

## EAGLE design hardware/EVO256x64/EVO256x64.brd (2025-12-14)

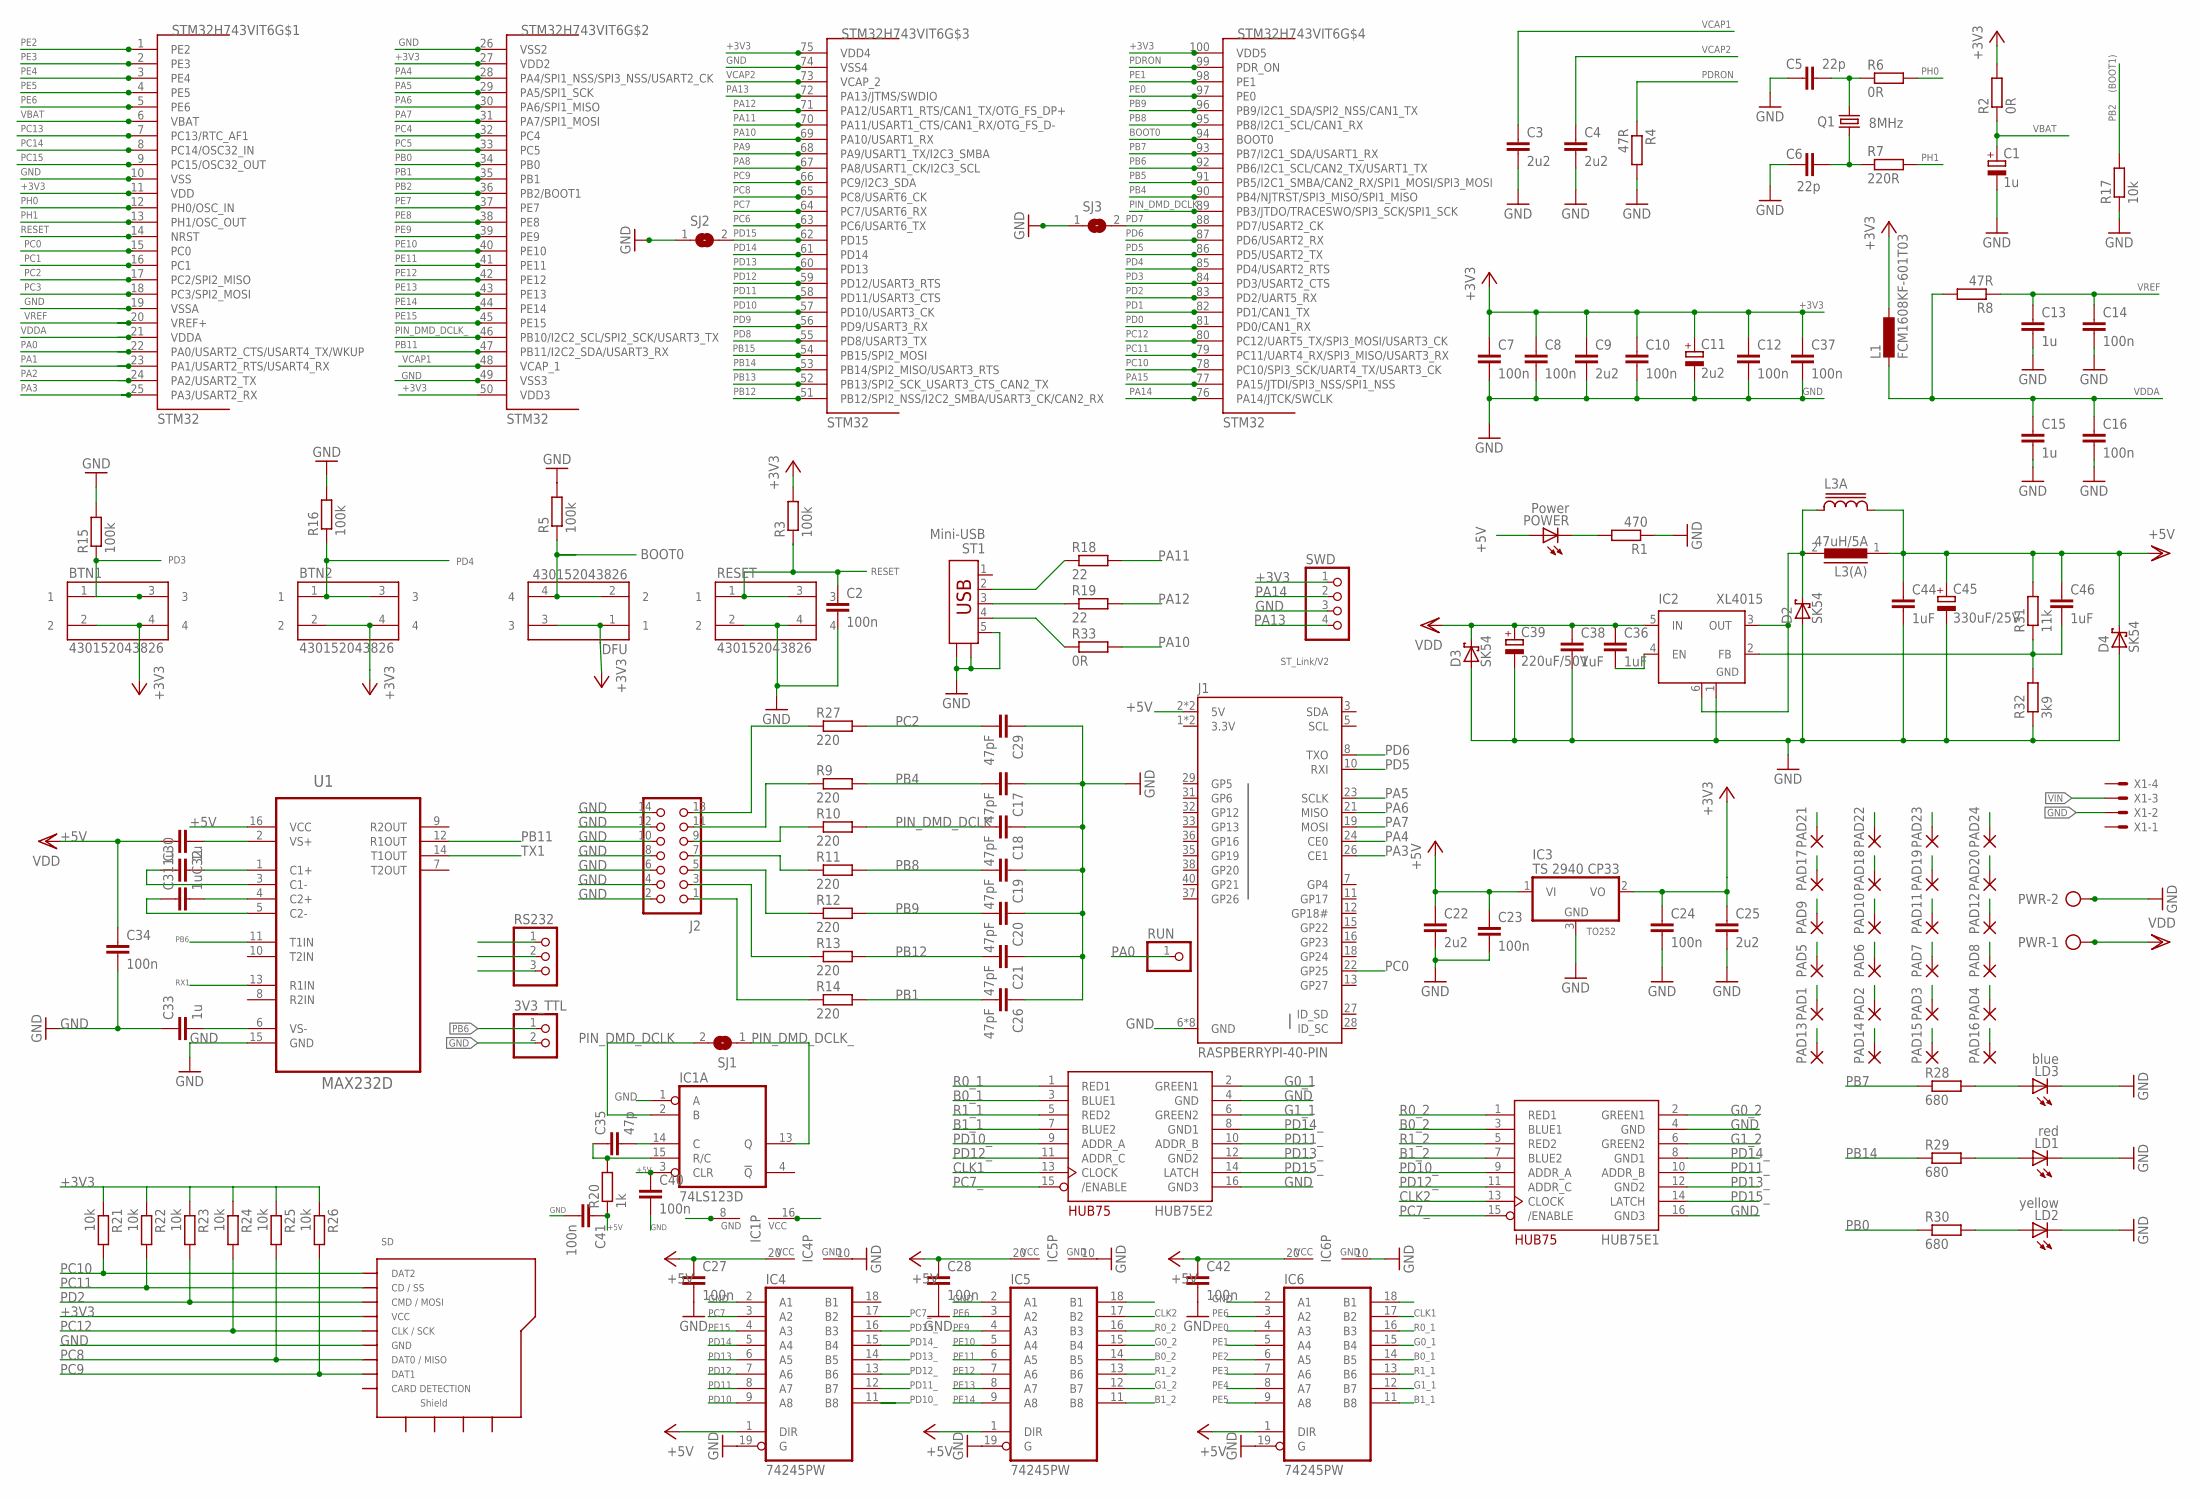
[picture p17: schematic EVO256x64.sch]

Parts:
3V3_TTL: PINHD-1X2; 1X02
BTN1, BTN2: 430152043826
C1: 1u; CT3528
C2, C7, C8, C10, C12, C14, C16, C23, C24, C27, C28, C34, C37, C40, C41, C42: 100n; C0805
C3, C4: 2u2; C0805
C5, C6: 22p; C0805
C9, C22, C25: 2u2; C1206
C11: 2u2; CT3528
C13, C15: 1u; C1206
C17, C18, C19, C20, C21, C26, C29: 47pF; C0805
C30, C31, C32, C33: 1u; C0805
C35: 47p; C0805
C36, C38, C44, C46: 1uF; C1206
C39: 220uF/50V; PANASONIC_G
C45: 330uF/25V; PANASONIC_G
D2, D3, D4: SK54; SMB
DFU: 430152043826
HUB75E1, HUB75E2: RGB; 2X08-IDC
IC1: 74LS123D; SO16
IC2: XL4015; TO263-5
IC3: TS 2940 CP33; TO252
IC4, IC5, IC6: 74245PW; TSSOP20
J1: RASPBERRYPI-40-PIN; 2X20
J2: CON_HEADER_2X07-PTH-SHROUDED; PINSHRD_PTH_2X07
L1: FCM1608KF-601T03; L2012C
L3(A): 47uH/5A; ED16
L3A: SRR1206
LD1: red; CHIP-LED0805
LD2: yellow; CHIP-LED0805
LD3: blue; CHIP-LED0805
PAD1, PAD2, PAD3, PAD4, PAD5, PAD6, PAD7, PAD8, PAD9, PAD10, PAD11, PAD12, PAD13, PAD14, PAD15, PAD16, PAD17, PAD18, PAD19, PAD20, PAD21, PAD22, PAD23, PAD24: SMD5; SMD2,54-5,08
POWER: Power; CHIPLED_0805
PWR: AK500/2-H
Q1: 8MHz; HC49UP
R1: 470; R0805
R2, R6, R33: 0R; R0805
R3, R5, R15, R16: 100k; R0805
R4, R8: 47R; R0805
R7: 220R; R0805
R9, R10, R11, R12, R13, R14, R27: 220; R0805
R17, R21, R22, R23, R24, R25, R26: 10k; R0805
R18, R19: 22; R0805
R20: 1k; R0805
R28, R29, R30: 680; R0805
R31: 11k; R1206
R32: 3k9; R1206
RESET: 430152043826
RS232: PINHD-1X3; 1X03
RUN: PINHD-1X1; 1X01
SD: MICROSD_CARD_POLLIN; MR**-AP*03**
SJ1, SJ2, SJ3: SJ
ST1: Mini-USB; USBMINI
STM32H743VIT6: STM32; LQFP100
SWD: PINHD-1X4; 1X04
U1: MAX232D; SOIC127P600X175-16N
X1: KK-156-4

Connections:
3.3V: J1.1 (3.3V), J1.17 (3.3V)
+3V3: BTN1.2, BTN1.4, BTN2.2, BTN2.4, C7.1, C8.1, C9.1, C10.1, C11.+, C12.1, C24.1, C25.1, C37.1, DFU.1, DFU.3, IC3.2 (VO), L1.1, R2.2, R3.2, R21.1, R22.1, R23.1, R24.1, R25.1, R26.1, SD.VCC, STM32H743VIT6.11 (VDD), STM32H743VIT6.27 (VDD2), STM32H743VIT6.50 (VDD3), STM32H743VIT6.75 (VDD4), STM32H743VIT6.100 (VDD5), SWD.1
+5V: C22.1, C23.1, C27.1, C28.1, C32.2, C34.1, C40.1, C41.1, C42.1, C44.1, C45.+, C46.1, D4.C, IC1.3 (CLR), IC1.16 (VCC), IC3.1 (VI), IC4.1 (DIR), IC4.20 (VCC), IC5.1 (DIR), IC5.20 (VCC), IC6.1 (DIR), IC6.20 (VCC), J1.2 (5V), J1.4 (5V), L3(A).1, L3A.2, PAD1.1, PAD2.1, PAD5.1, PAD6.1, PAD9.1, PAD10.1, PAD13.1, PAD14.1, PAD17.1, PAD18.1, PAD21.1, PAD22.1, POWER.A, R20.1, R31.2, U1.16 (VCC)
B0_1: HUB75E2.3 (BLUE1), IC6.14 (B5)
B0_2: HUB75E1.3 (BLUE1), IC5.14 (B5)
B1_1: HUB75E2.7 (BLUE2), IC6.11 (B8)
B1_2: HUB75E1.7 (BLUE2), IC5.11 (B8)
BOOT0: DFU.2, DFU.4, R5.1, STM32H743VIT6.94 (BOOT0)
CLK1: HUB75E2.13 (CLOCK), IC6.17 (B2)
CLK2: HUB75E1.13 (CLOCK), IC5.17 (B2)
G0_1: HUB75E2.2 (GREEN1), IC6.15 (B4)
G0_2: HUB75E1.2 (GREEN1), IC5.15 (B4)
G1_1: HUB75E2.6 (GREEN2), IC6.12 (B7)
G1_2: HUB75E1.6 (GREEN2), IC5.12 (B7)
GND: 3V3_TTL.2, C1.-, C2.2, C3.2, C4.2, C5.2, C6.2, C7.2, C8.2, C9.2, C10.2, C11.-, C12.2, C13.2, C14.2, C15.2, C16.2, C17.1, C18.1, C19.1, C20.1, C21.1, C22.2, C23.2, C24.2, C25.2, C26.1, C27.2, C28.2, C29.1, C33.1, C34.2, C37.2, C38.2, C39.-, C40.2, C41.2, C42.2, C44.2, C45.-, D2.A, D3.A, D4.A, HUB75E1.4 (GND), HUB75E1.16 (GND3), HUB75E2.4 (GND), HUB75E2.16 (GND3), IC1.1 (A), IC1.8 (GND), IC2.1 (GND), IC3.3 (GND), IC4.2 (A1), IC4.10 (GND), IC4.19 (G), IC5.2 (A1), IC5.10 (GND), IC5.19 (G), IC6.2 (A1), IC6.10 (GND), IC6.19 (G), J1.6 (GND), J1.9 (GND), J1.14 (GND), J1.20 (GND), J1.25 (GND), J1.30 (GND), J1.34 (GND), J1.39 (GND), J2.2, J2.4, J2.6, J2.8, J2.10, J2.12, J2.14, LD1.C, LD2.C, LD3.C, PAD3.1, PAD4.1, PAD7.1, PAD8.1, PAD11.1, PAD12.1, PAD15.1, PAD16.1, PAD19.1, PAD20.1, PAD23.1, PAD24.1, PWR.2, R1.1, R4.2, R5.2, R15.2, R16.2, R17.1, R32.1, RESET.2, RESET.4, RS232.2, SD.GND, SJ2.1, SJ3.1, ST1.5, ST1.N1, ST1.N2, STM32H743VIT6.10 (VSS), STM32H743VIT6.19 (VSSA), STM32H743VIT6.26 (VSS2), STM32H743VIT6.49 (VSS3), STM32H743VIT6.54 (PB15/SPI2_MOSI), STM32H743VIT6.74 (VSS4), SWD.3, U1.15 (GND), X1.2
unnamed: C5.1, Q1.2, R6.1
unnamed: C6.1, Q1.1, R7.1
unnamed: POWER.C, R1.2
unnamed: J2.13, R27.1
unnamed: J2.11, R9.1
unnamed: J2.9, R10.1
unnamed: J2.7, R11.1
unnamed: J2.5, R12.1
unnamed: J2.3, R13.1
unnamed: C35.1, IC1.15 (R/C), R20.2
unnamed: J2.1, R14.1
unnamed: C30.2, U1.1 (C1+)
unnamed: C30.1, U1.3 (C1-)
unnamed: C31.2, U1.4 (C2+)
unnamed: C31.1, U1.5 (C2-)
unnamed: C33.2, U1.6 (VS-)
unnamed: C32.1, U1.2 (VS+)
unnamed: LD1.A, R29.2
unnamed: D2.C, IC2.3 (OUT), IC2.6 (TAB), L3(A).2, L3A.1
unnamed: C46.2, IC2.2 (FB), R31.1, R32.2
unnamed: C35.2, IC1.14 (C)
unnamed: LD3.A, R28.2
unnamed: C36.2, IC2.4 (EN)
unnamed: R33.1, ST1.4
unnamed: LD2.A, R30.2
unnamed: R19.1, ST1.3
unnamed: R18.1, ST1.2
PA0: RUN.1, STM32H743VIT6.22 (PA0/USART2_CTS/USART4_TX/WKUP)
PA1: STM32H743VIT6.23 (PA1/USART2_RTS/USART4_RX)
PA2: STM32H743VIT6.24 (PA2/USART2_TX)
PA3: J1.26 (CE1), STM32H743VIT6.25 (PA3/USART2_RX)
PA4: J1.24 (CE0), STM32H743VIT6.28 (PA4/SPI1_NSS/SPI3_NSS/USART2_CK)
PA5: J1.23 (SCLK), STM32H743VIT6.29 (PA5/SPI1_SCK)
PA6: J1.21 (MISO), STM32H743VIT6.30 (PA6/SPI1_MISO)
PA7: J1.19 (MOSI), STM32H743VIT6.31 (PA7/SPI1_MOSI)
PA8: STM32H743VIT6.67 (PA8/USART1_CK/I2C3_SCL)
PA9: STM32H743VIT6.68 (PA9/USART1_TX/I2C3_SMBA)
PA10: R33.2, STM32H743VIT6.69 (PA10/USART1_RX)
PA11: R18.2, STM32H743VIT6.70 (PA11/USART1_CTS/CAN1_RX/OTG_FS_D-)
PA12: R19.2, STM32H743VIT6.71 (PA12/USART1_RTS/CAN1_TX/OTG_FS_DP+)
PA13: STM32H743VIT6.72 (PA13/JTMS/SWDIO), SWD.4
PA14: STM32H743VIT6.76 (PA14/JTCK/SWCLK), SWD.2
PA15: STM32H743VIT6.77 (PA15/JTDI/SPI3_NSS/SPI1_NSS)
PB0: R30.1, STM32H743VIT6.34 (PB0)
PB1: C26.2, R14.2, STM32H743VIT6.35 (PB1)
PB2: R17.2, STM32H743VIT6.36 (PB2/BOOT1)
PB4: C17.2, R9.2, STM32H743VIT6.90 (PB4/NJTRST/SPI3_MISO/SPI1_MISO)
PB5: STM32H743VIT6.91 (PB5/I2C1_SMBA/CAN2_RX/SPI1_MOSI/SPI3_MO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)
PB6: 3V3_TTL.1, STM32H743VIT6.92 (PB6/I2C1_SCL/CAN2_TX/USART1_TX), U1.11 (T1IN)
PB7: R28.1, STM32H743VIT6.93 (PB7/I2C1_SDA/USART1_RX)
PB8: C19.2, R11.2, STM32H743VIT6.95 (PB8/I2C1_SCL/CAN1_RX)
PB9: C20.2, R12.2, STM32H743VIT6.96 (PB9/I2C1_SDA/SPI2_NSS/CAN1_TX)
PB11: STM32H743VIT6.47 (PB11/I2C2_SDA/USART3_RX), U1.12 (R1OUT)
PB12: C21.2, R13.2, STM32H743VIT6.51 (PB12/SPI2_NSS/I2C2_SMBA/USART3_CK/CAN2_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)
PB13: STM32H743VIT6.52 (PB13/SPI2_SCK_USART3_CTS_CAN2_TX)
PB14: R29.1, STM32H743VIT6.53 (PB14/SPI2_MISO/USART3_RTS)
PC0: J1.22 (GP25), STM32H743VIT6.15 (PC0)
PC1: STM32H743VIT6.16 (PC1)
PC2: C29.2, R27.2, STM32H743VIT6.17 (PC2/SPI2_MISO)
PC3: STM32H743VIT6.18 (PC3/SPI2_MOSI)
PC4: STM32H743VIT6.32 (PC4)
PC5: STM32H743VIT6.33 (PC5)
PC6: STM32H743VIT6.63 (PC6/USART6_TX)
PC7: IC4.3 (A2), STM32H743VIT6.64 (PC7/USART6_RX)
PC7_: HUB75E1.15 (/ENABLE), HUB75E2.15 (/ENABLE), IC4.17 (B2)
PC8: R25.2, SD.DAT0 (DAT0/MISO), STM32H743VIT6.65 (PC8/USART6_CK)
PC9: R26.2, SD.DAT1, STM32H743VIT6.66 (PC9/I2C3_SDA)
PC10: R21.2, SD.DAT2, STM32H743VIT6.78 (PC10/SPI3_SCK/UART4_TX/USART3_CK)
PC11: R22.2, SD.DAT3/CS (CD/SS), STM32H743VIT6.79 (PC11/UART4_RX/SPI3_MISO/USART3_RX)
PC12: R24.2, SD.CLK (CLK/SCK), STM32H743VIT6.80 (PC12/UART5_TX/SPI3_MOSI/USART3_CK)
PC13: STM32H743VIT6.7 (PC13/RTC_AF1)
PC14: STM32H743VIT6.8 (PC14/OSC32_IN)
PC15: STM32H743VIT6.9 (PC15/OSC32_OUT)
PD0: STM32H743VIT6.81 (PD0/CAN1_RX)
PD1: STM32H743VIT6.82 (PD1/CAN1_TX)
PD2: R23.2, SD.CMD (CMD/MOSI), STM32H743VIT6.83 (PD2/UART5_RX)
PD3: BTN1.1, BTN1.3, R15.1, STM32H743VIT6.84 (PD3/USART2_CTS)
PD4: BTN2.1, BTN2.3, R16.1, STM32H743VIT6.85 (PD4/USART2_RTS)
PD5: J1.10 (RXI), STM32H743VIT6.86 (PD5/USART2_TX)
PD6: J1.8 (TXO), STM32H743VIT6.87 (PD6/USART2_RX)
PD7: SJ3.2, STM32H743VIT6.88 (PD7/USART2_CK)
PD8: STM32H743VIT6.55 (PD8/USART3_TX)
PD9: STM32H743VIT6.56 (PD9/USART3_RX)
PD10: IC4.9 (A8), STM32H743VIT6.57 (PD10/USART3_CK)
PD10_: HUB75E1.9 (ADDR_A), HUB75E2.9 (ADDR_A), IC4.11 (B8)
PD11: IC4.8 (A7), STM32H743VIT6.58 (PD11/USART3_CTS)
PD11_: HUB75E1.10 (ADDR_B), HUB75E2.10 (ADDR_B), IC4.12 (B7)
PD12: IC4.7 (A6), STM32H743VIT6.59 (PD12/USART3_RTS)
PD12_: HUB75E1.11 (ADDR_C), HUB75E2.11 (ADDR_C), IC4.13 (B6)
PD13: IC4.6 (A5), STM32H743VIT6.60 (PD13)
PD13_: HUB75E1.12 (GND2), HUB75E2.12 (GND2), IC4.14 (B5)
PD14: IC4.5 (A4), STM32H743VIT6.61 (PD14)
PD14_: HUB75E1.8 (GND1), HUB75E2.8 (GND1), IC4.15 (B4)
PD15: SJ2.2, STM32H743VIT6.62 (PD15)
PD15_: HUB75E1.14 (LATCH), HUB75E2.14 (LATCH), IC4.16 (B3)
PDRON: R4.1, STM32H743VIT6.99 (PDR_ON)
PE0: IC6.4 (A3), STM32H743VIT6.97 (PE0)
PE1: IC6.5 (A4), STM32H743VIT6.98 (PE1)
PE2: IC6.6 (A5), STM32H743VIT6.1 (PE2)
PE3: IC6.7 (A6), STM32H743VIT6.2 (PE3)
PE4: IC6.8 (A7), STM32H743VIT6.3 (PE4)
PE5: IC6.9 (A8), STM32H743VIT6.4 (PE5)
PE6: IC5.3 (A2), IC6.3 (A2), STM32H743VIT6.5 (PE6)
PE7: STM32H743VIT6.37 (PE7)
PE8: STM32H743VIT6.38 (PE8)
PE9: IC5.4 (A3), STM32H743VIT6.39 (PE9)
PE10: IC5.5 (A4), STM32H743VIT6.40 (PE10)
PE11: IC5.6 (A5), STM32H743VIT6.41 (PE11)
PE12: IC5.7 (A6), STM32H743VIT6.42 (PE12)
PE13: IC5.8 (A7), STM32H743VIT6.43 (PE13)
PE14: IC5.9 (A8), STM32H743VIT6.44 (PE14)
PE15: IC4.4 (A3), STM32H743VIT6.45 (PE15)
PH0: R6.2, STM32H743VIT6.12 (PH0/OSC_IN)
PH1: R7.2, STM32H743VIT6.13 (PH1/OSC_OUT)
PIN_DMD_DCLK: C18.2, IC1.2 (B), R10.2, SJ1.2
PIN_DMD_DCLK_: IC1.13 (Q), SJ1.1, STM32H743VIT6.46 (PB10/I2C2_SCL/SPI2_SCK/USART3_TX), STM32H743VIT6.89 (PB3/JTDO/TRACESWO/SPI3_SCK/SPI1_SCK)
R0_1: HUB75E2.1 (RED1), IC6.16 (B3)
R0_2: HUB75E1.1 (RED1), IC5.16 (B3)
R1_1: HUB75E2.5 (RED2), IC6.13 (B6)
R1_2: HUB75E1.5 (RED2), IC5.13 (B6)
RESET: C2.1, R3.1, RESET.1, RESET.3, STM32H743VIT6.14 (NRST)
RX1: RS232.3, U1.13 (R1IN)
TX1: RS232.1, U1.14 (T1OUT)
VBAT: C1.+, R2.1, STM32H743VIT6.6 (VBAT)
VCAP1: C3.1, STM32H743VIT6.48 (VCAP_1)
VCAP2: C4.1, STM32H743VIT6.73 (VCAP_2)
VDDA: C15.1, C16.1, L1.2, R8.2, STM32H743VIT6.21 (VDDA)
VIN: C36.1, C38.1, C39.+, D3.C, IC2.5 (IN), PWR.1, X1.3
VREF: C13.1, C14.1, R8.1, STM32H743VIT6.20 (VREF+)

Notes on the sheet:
TO252
(BOOT1)
ST_Link/V2
PB15

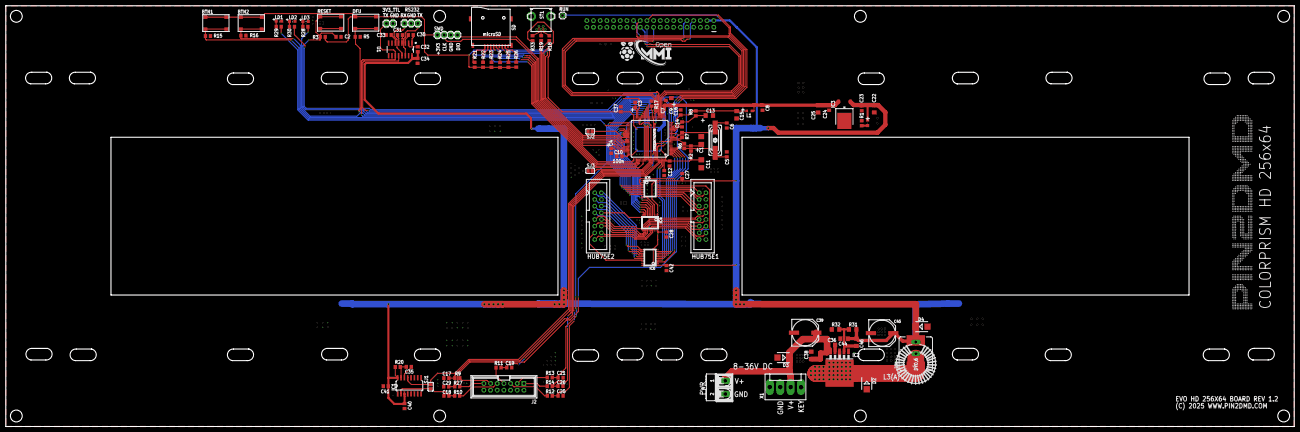
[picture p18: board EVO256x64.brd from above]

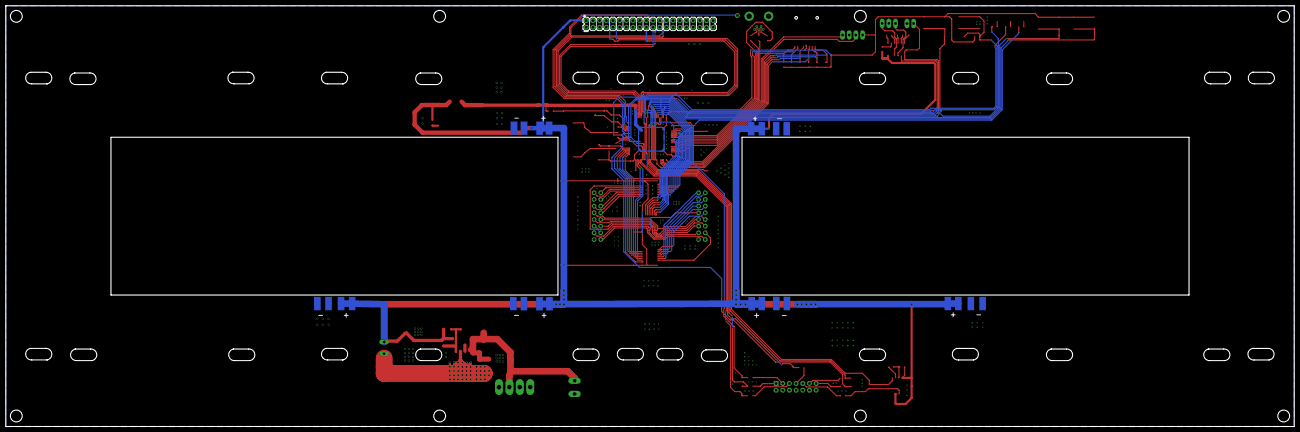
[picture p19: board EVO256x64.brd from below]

Board: 2 copper layers, 490.0 x 160.0 mm, 140 parts (25 on the bottom side), 123 nets.

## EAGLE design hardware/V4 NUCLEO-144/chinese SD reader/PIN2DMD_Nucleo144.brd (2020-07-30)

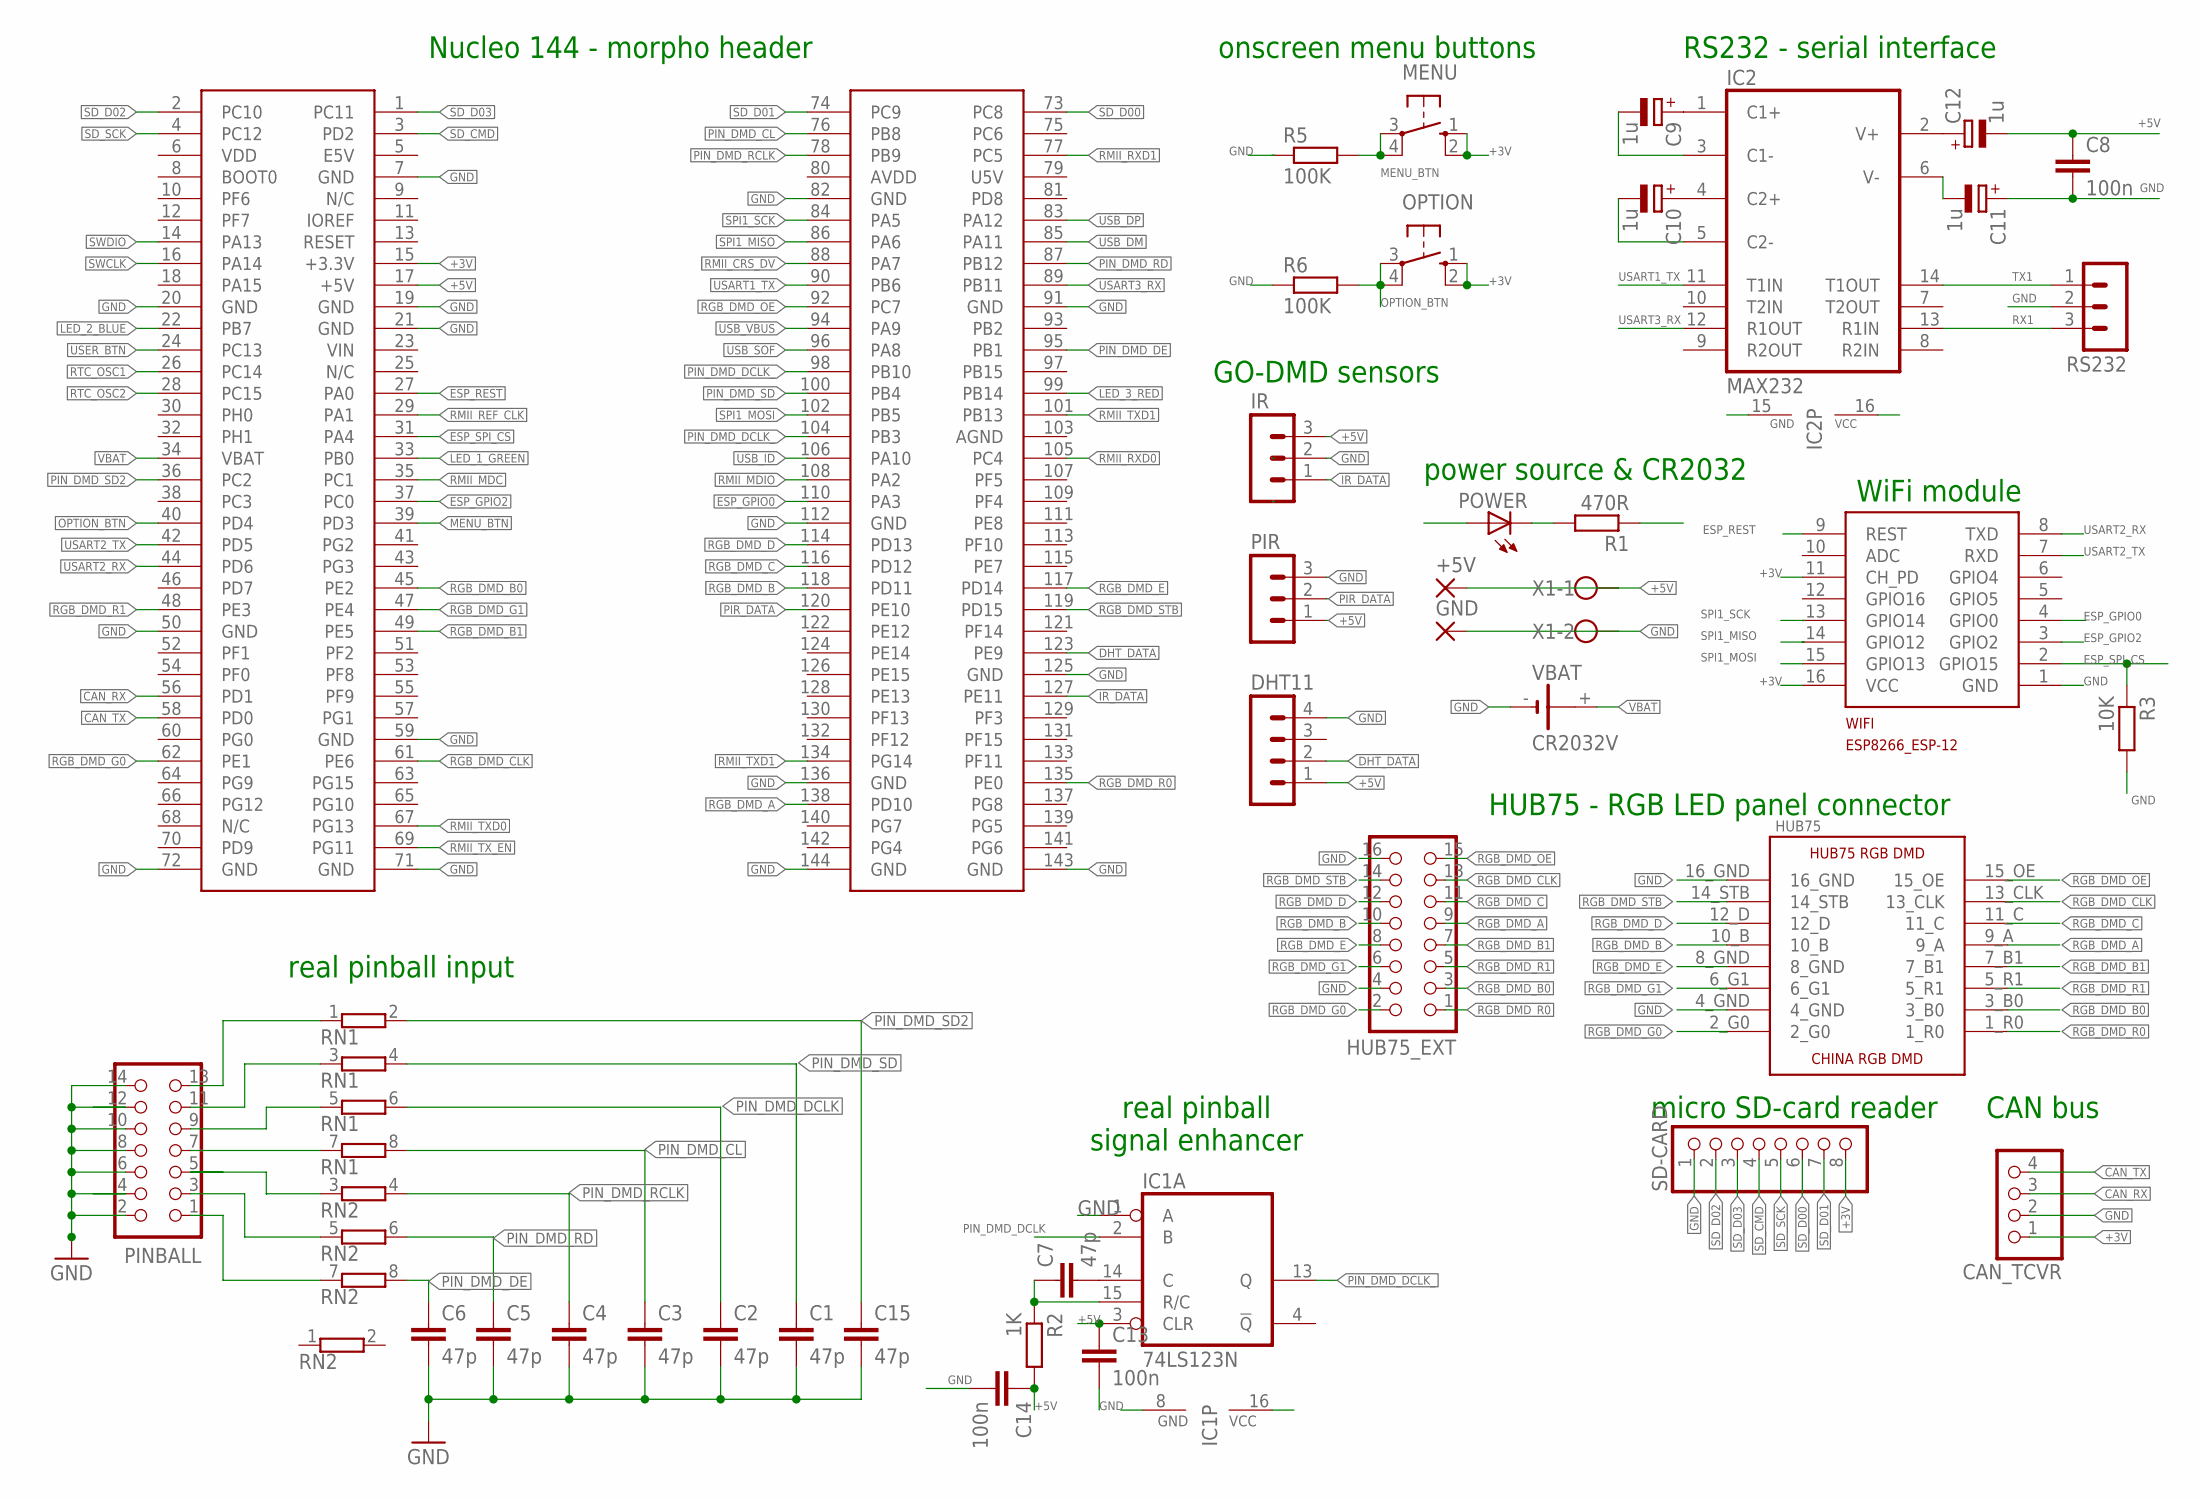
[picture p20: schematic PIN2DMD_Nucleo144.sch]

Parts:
+5V: WIREPADSMD2,54-5,08; SMD2,54-5,08
C1, C2, C3, C4, C5, C6, C7, C15: 47p; C025-024X044
C8, C13, C14: 100n; C025-024X044
C9, C10, C11, C12: 1u; E2-4
CAN_TCVR: PINHD-1X4; 1X04
DHT11: MA04-1
GND: WIREPADSMD2,54-5,08; SMD2,54-5,08
HUB75: RGB_DMD_HUB75_HEADER_FEMALE; 16_PIN_HUB75_RGB_FEMALE_DOWN
HUB75_EXT: CON_HEADER_2X08B; PINSHRD_PTH_2X08
IC1: 74LS123N; DIL16
IC2: MAX232; DIL16
IR: MA03-1
MENU: 10-XX; B3F-10XX
OPTION: 10-XX; B3F-10XX
PINBALL: CON_HEADER_2X07-PTH-SHROUDED; PINSHRD_PTH_2X07
PIR: MA03-1
POWER: LED3MM
R1: 470R; 0207/10
R2: 1K; 0207/10
R3: 10K; 0207/10
R5, R6: 100K; 0207/10
RN1, RN2: E4RP; SIL8
RS232: MA03-1
SD-CARD: PINHD-1X8; 1X08
U$1: NUCLEO-144
VBAT: CR2032V
WIFI: ESP8266_ESP-12; ESP8266-ESP12
X1: W237-102

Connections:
+3V: CAN_TCVR.1, MENU.1 (S), MENU.2 (S1), OPTION.1 (S), OPTION.2 (S1), SD-CARD.8, U$1.15 (+3.3V), WIFI.11 (CH_PD), WIFI.16 (VCC)
+5V: +5V.1, C8.1, C12.-, C13.1, C14.1, DHT11.1, IC1.3 (CLR), IC1.16 (VCC), IC2.16 (VCC), IR.3, PIR.1, POWER.A, R2.2, U$1.17 (+5V), X1.1
CAN_RX: CAN_TCVR.3, U$1.56 (PD1)
CAN_TX: CAN_TCVR.4, U$1.58 (PD0)
DHT_DATA: DHT11.2, U$1.123 (PE9)
ESP_GPIO0: U$1.110 (PA3), WIFI.4 (GPIO0)
ESP_GPIO2: U$1.37 (PC0), WIFI.3 (GPIO2)
ESP_REST: U$1.27 (PA0), WIFI.9 (REST)
ESP_SPI_CS: R3.1, U$1.31 (PA4), WIFI.2 (GPIO15)
GND: C1.2, C2.2, C3.2, C4.2, C5.2, C6.2, C8.2, C11.+, C13.2, C14.2, C15.2, CAN_TCVR.2, DHT11.4, GND.1, HUB75.4_GND, HUB75.16_GND, HUB75_EXT.4, HUB75_EXT.16, IC1.1 (A), IC1.8 (GND), IC2.15 (GND), IR.2, PINBALL.2, PINBALL.4, PINBALL.6, PINBALL.8, PINBALL.10, PINBALL.12, PINBALL.14, PIR.3, R1.1, R3.2, R5.1, R6.1, RS232.2, SD-CARD.1, U$1.7 (GND), U$1.19 (GND), U$1.20 (GND), U$1.21 (GND), U$1.50 (GND), U$1.59 (GND), U$1.71 (GND), U$1.72 (GND), U$1.82 (GND), U$1.91 (GND), U$1.112 (GND), U$1.125 (GND), U$1.136 (GND), U$1.143 (GND), U$1.144 (GND), VBAT.-, WIFI.1 (GND), X1.2
IR_DATA: IR.1, U$1.127 (PE11)
LED_1_GREEN: U$1.33 (PB0)
LED_2_BLUE: U$1.22 (PB7)
LED_3_RED: U$1.99 (PB14)
MENU_BTN: MENU.3, MENU.4 (P1), R5.2, U$1.39 (PD3)
unnamed: POWER.K (C), R1.2
unnamed: C7.1, IC1.15 (R/C), R2.1
unnamed: C7.2, IC1.14 (C)
unnamed: C9.+, IC2.1 (C1+)
unnamed: PINBALL.7, RN1.7 (1)
unnamed: PINBALL.5, RN2.3 (1)
unnamed: C10.+, IC2.4 (C2+)
unnamed: C11.-, IC2.6 (V-)
unnamed: C9.-, IC2.3 (C1-)
unnamed: C10.-, IC2.5 (C2-)
unnamed: PINBALL.3, RN2.5 (1)
unnamed: PINBALL.1, RN2.7 (1)
unnamed: PINBALL.9, RN1.5 (1)
unnamed: PINBALL.11, RN1.3 (1)
unnamed: C12.+, IC2.2 (V+)
unnamed: PINBALL.13, RN1.1
OPTION_BTN: OPTION.3, OPTION.4 (P1), R6.2, U$1.40 (PD4)
PIN_DMD_CL: C3.1, RN1.8 (2), U$1.76 (PB8)
PIN_DMD_DCLK: C2.1, IC1.2 (B), RN1.6 (2)
PIN_DMD_DCLK_: IC1.13 (Q), U$1.98 (PB10), U$1.104 (PB3)
PIN_DMD_DE: C6.1, RN2.8 (2), U$1.95 (PB1)
PIN_DMD_RCLK: C4.1, RN2.4 (2), U$1.78 (PB9)
PIN_DMD_RD: C5.1, RN2.6 (2), U$1.87 (PB12)
PIN_DMD_SD: C1.1, RN1.4 (2), U$1.100 (PB4)
PIN_DMD_SD2: C15.1, RN1.2, U$1.36 (PC2)
PIR_DATA: PIR.2, U$1.120 (PE10)
RGB_DMD_A: HUB75.9_A, HUB75_EXT.9, U$1.138 (PD10)
RGB_DMD_B: HUB75.10_B, HUB75_EXT.10, U$1.118 (PD11)
RGB_DMD_B0: HUB75.3_B0, HUB75_EXT.3, U$1.45 (PE2)
RGB_DMD_B1: HUB75.7_B1, HUB75_EXT.7, U$1.49 (PE5)
RGB_DMD_C: HUB75.11_C, HUB75_EXT.11, U$1.116 (PD12)
RGB_DMD_CLK: HUB75.13_CLK, HUB75_EXT.13, U$1.61 (PE6)
RGB_DMD_D: HUB75.12_D, HUB75_EXT.12, U$1.114 (PD13)
RGB_DMD_E: HUB75.8_GND, HUB75_EXT.8, U$1.117 (PD14)
RGB_DMD_G0: HUB75.2_G0, HUB75_EXT.2, U$1.62 (PE1)
RGB_DMD_G1: HUB75.6_G1, HUB75_EXT.6, U$1.47 (PE4)
RGB_DMD_OE: HUB75.15_OE, HUB75_EXT.15, U$1.92 (PC7)
RGB_DMD_R0: HUB75.1_R0, HUB75_EXT.1, U$1.135 (PE0)
RGB_DMD_R1: HUB75.5_R1, HUB75_EXT.5, U$1.48 (PE3)
RGB_DMD_STB: HUB75.14_STB, HUB75_EXT.14, U$1.119 (PD15)
RMII_CRS_DV: U$1.88 (PA7)
RMII_MDC: U$1.35 (PC1)
RMII_MDIO: U$1.108 (PA2)
RMII_REF_CLK: U$1.29 (PA1)
RMII_RXD0: U$1.105 (PC4)
RMII_RXD1: U$1.77 (PC5)
RMII_TXD0: U$1.67 (PG13)
RMII_TXD1: U$1.101 (PB13), U$1.134 (PG14)
RMII_TX_EN: U$1.69 (PG11)
RTC_OSC1: U$1.26 (PC14)
RTC_OSC2: U$1.28 (PC15)
RX1: IC2.13 (R1IN), RS232.3
SD_CMD: SD-CARD.4, U$1.3 (PD2)
SD_D00: SD-CARD.6, U$1.73 (PC8)
SD_D01: SD-CARD.7, U$1.74 (PC9)
SD_D02: SD-CARD.2, U$1.2 (PC10)
SD_D03: SD-CARD.3, U$1.1 (PC11)
SD_SCK: SD-CARD.5, U$1.4 (PC12)
SPI1_MISO: U$1.86 (PA6), WIFI.14 (GPIO12)
SPI1_MOSI: U$1.102 (PB5), WIFI.15 (GPIO13)
SPI1_SCK: U$1.84 (PA5), WIFI.13 (GPIO14)
SWCLK: U$1.16 (PA14)
SWDIO: U$1.14 (PA13)
TX1: IC2.14 (T1OUT), RS232.1
USART1_TX: IC2.11 (T1IN), U$1.90 (PB6)
USART2_RX: U$1.44 (PD6), WIFI.8 (TXD)
USART2_TX: U$1.42 (PD5), WIFI.7 (RXD)
USART3_RX: IC2.12 (R1OUT), U$1.89 (PB11)
USB_DM: U$1.85 (PA11)
USB_DP: U$1.83 (PA12)
USB_ID: U$1.106 (PA10)
USB_SOF: U$1.96 (PA8)
USB_VBUS: U$1.94 (PA9)
USER_BTN: U$1.24 (PC13)
VBAT: U$1.34 (VBAT), VBAT.+

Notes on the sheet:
power source & CR2032
onscreen menu buttons
WiFi module
Nucleo 144 - morpho header
HUB75 - RGB LED panel connector
RS232 - serial interface
GO-DMD sensors
CAN bus
micro SD-card reader
real pinball input
real pinball signal enhancer

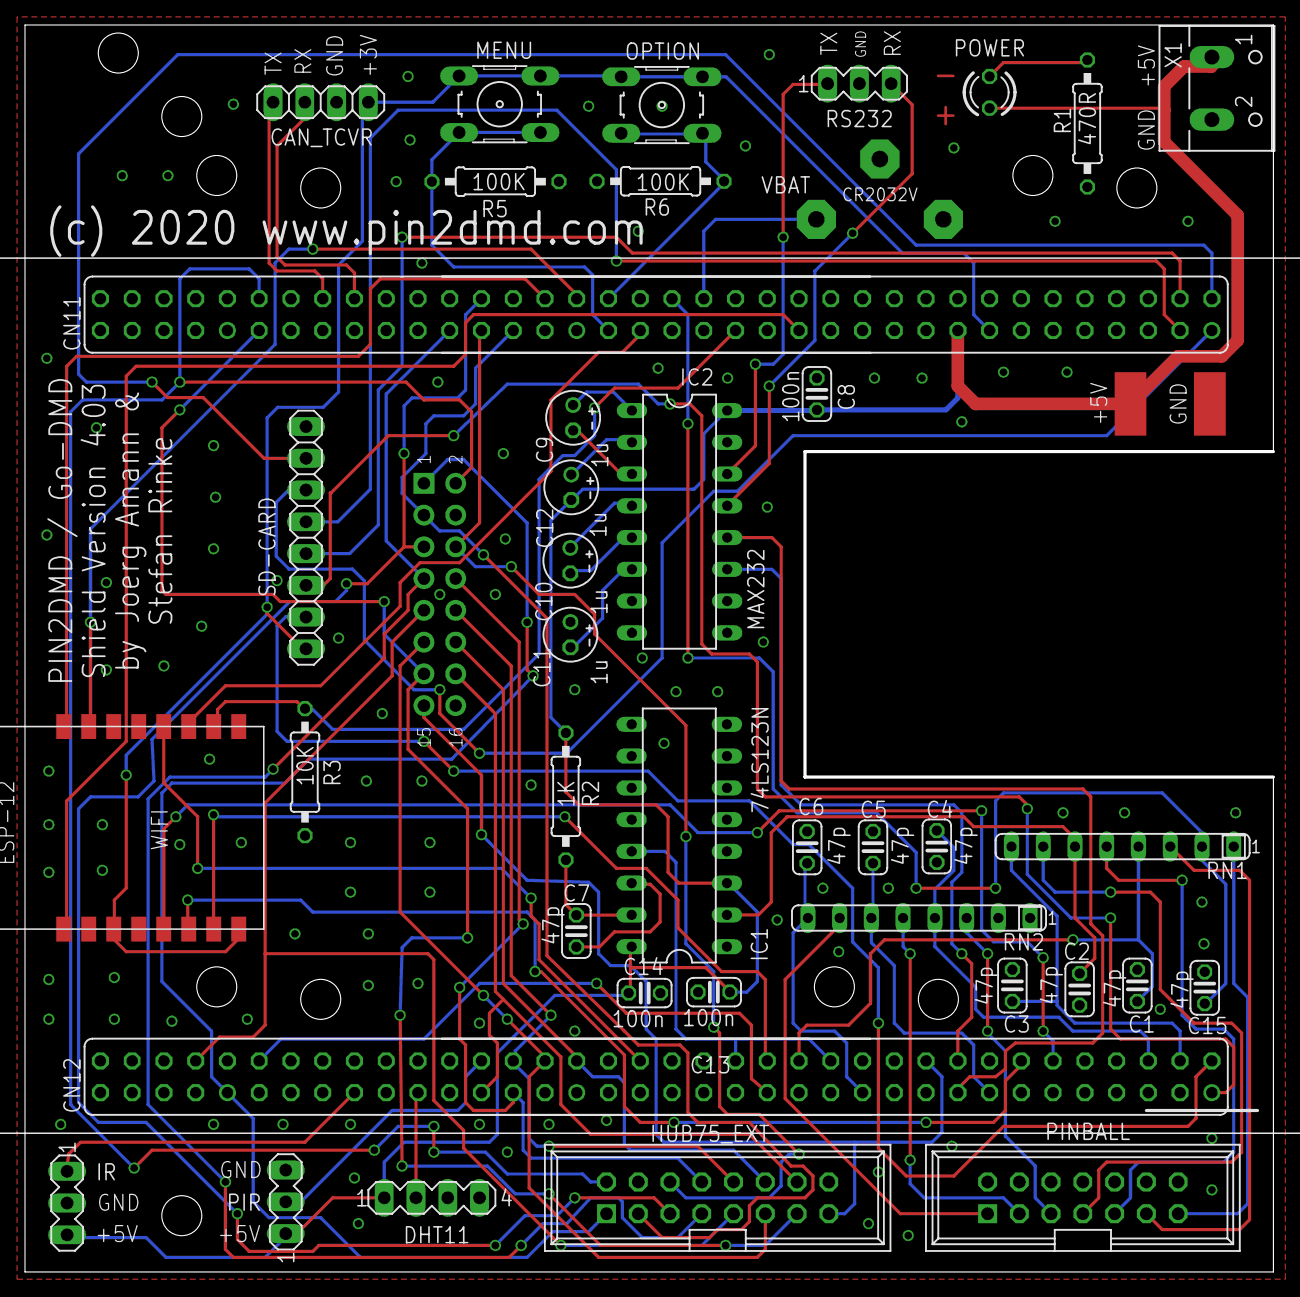
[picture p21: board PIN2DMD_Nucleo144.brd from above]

Board: 2 copper layers, 99.9 x 99.7 mm, 42 parts (1 on the bottom side), 69 nets.

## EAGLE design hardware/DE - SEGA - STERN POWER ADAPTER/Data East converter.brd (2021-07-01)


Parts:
X1: KK-156-15_FKK-156-15-F; KK-156-15_F
X2: KK-156-15
X3: KK-156-4

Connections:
12V: X1.3, X2.13, X3.3
GND: X1.15, X2.1, X3.2
unnamed: X1.14, X2.2
unnamed: X1.10, X2.6
unnamed: X1.2, X2.14
unnamed: X1.1, X2.15
unnamed: X1.4, X2.12
unnamed: X1.6, X2.10
unnamed: X1.8, X2.8, X3.1
unnamed: X1.7, X2.9
unnamed: X1.9, X2.7
unnamed: X1.5, X2.11
unnamed: X1.13, X2.3
unnamed: X1.12, X2.4
unnamed: X1.11, X2.5

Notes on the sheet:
12V
GND
-12V
N.C.
KEY
Whitestar


Board: 2 copper layers, 59.2 x 40.9 mm, 3 parts (0 on the bottom side), 15 nets.

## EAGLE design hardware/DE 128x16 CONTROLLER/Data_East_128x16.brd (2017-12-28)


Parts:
C1: 100uF/15V; E2,5-7
C3: 47pF; C050-025X075
C10, C11, C12, C13, C14, C15, C16, C17, C18, C19, C20, C21: 100nF; C050-025X075
CPU_INPUT: J1; 61202622323
DISPLAY: PINBALL_DMD_HEADER_MALE; 14_PIN_DMD_MALE
R5, R6, R7, R8, R9, R10, R11, R33, R88: 100k; 0207/7
R13, R14: 10k; 0207/7
R18: 2K; 0207/7
R89_1/4W: 15K; 0207/7
R90_1/4W: 4.7K; 0207/7
SJ2, SJ4, SJ5, SJ6: SJ
TEST: R-EU_0207/7; 0207/7
U1: 74HC374N; DIL20
U2: 74HC00N; DIL14
U3: 74HC04N; DIL14
U4: 74HC259N; DIL16
U5: 7407N; DIL14
U6: 74HC139N; DIL16
U7: 6264; DIL28-6
U8: 27010 / 27512; DIL32
U9: 4020N; DIL16
U10: 74HC153N; DIL16
U11: 74HC74N; DIL14
U12: Z80A; DIL40
X2: KK-156-4
Y1: 8Mhz; HC49U70

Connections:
30: SJ6.1, U9.1 (Q12)
60: SJ2.2, SJ4.2, SJ5.1, SJ5.2, SJ6.2, U9.15 (Q11), U12.17 (NMI)
120: SJ4.1, U9.14 (Q10)
240: SJ2.1, U9.12 (Q9)
+5V: C1.+, C10.1, C11.1, C12.1, C13.1, C14.1, C15.1, C16.1, C17.1, C18.1, C19.1, C20.1, C21.1, R5.1, R6.1, R7.1, R8.1, R9.1, R10.1, R11.1, R13.2, R14.1, R33.2, R88.1, R89_1/4W.2, R90_1/4W.2, U1.20 (VCC), U2.14 (VCC), U3.14 (VCC), U4.16 (VCC), U5.14 (VCC), U6.13 (B), U6.16 (VCC), U7.26 (CS2), U7.28 (VCC), U8.1 (VPP), U8.30 (NC), U8.31 (!PGM), U8.32 (VCC), U9.16 (VDD), U10.16 (VCC), U11.2 (D), U11.10 (PRE), U11.13 (CLR), U11.14 (VCC), U12.11 (VCC), X2.1, X2.2
A(0): U7.10 (A0), U8.12 (A0), U10.14 (A), U12.30 (A0)
A(1): U7.9 (A1), U8.11 (A1), U10.2 (B), U12.31 (A1)
A(2): U6.2 (A), U7.8 (A2), U8.10 (A2), U12.32 (A2)
A(3): U4.1 (S0), U7.7 (A3), U8.9 (A3), U12.33 (A3)
A(4): U4.2 (S1), U7.6 (A4), U8.8 (A4), U12.34 (A4)
A(5): U7.5 (A5), U8.7 (A5), U12.35 (A5)
A(6): U4.3 (S2), U7.4 (A6), U8.6 (A6), U12.36 (A6)
A(7): U6.3 (B), U7.3 (A7), U8.5 (A7), U12.37 (A7)
A(8): U7.25 (A8), U8.27 (A8), U12.38 (A8)
A(9): U7.24 (A9), U8.26 (A9), U12.39 (A9)
A(10): U7.21 (A10), U8.23 (A10), U12.40 (A10)
A(11): U7.23 (A11), U8.25 (A11), U12.1 (A11)
A(12): U7.2 (A12), U8.4 (A12), U12.2 (A12)
A(13): U8.28 (A13), U12.3 (A13)
A(14): U2.4 (I0), U2.10 (I1), U2.13 (I1), U12.4 (A14)
A(15): U6.14 (A), U12.5 (A15)
BS0: U2.6 (O), U8.29 (A14)
BS1: U2.8 (O), U8.3 (A15)
BS2: U2.11 (O), U8.2 (A16)
D(0): U1.2 (1Q), U4.13 (D), U7.11 (I/O1), U8.13 (O0), U10.6 (1C0), U12.14 (D0)
D(1): U1.5 (2Q), U7.12 (I/O2), U8.14 (O1), U10.10 (2C0), U12.15 (D1)
D(2): U1.6 (3Q), U7.13 (I/O3), U8.15 (O2), U10.5 (1C1), U12.12 (D2)
D(3): U1.9 (4Q), U7.15 (I/O4), U8.17 (O3), U10.11 (2C1), U12.8 (D3)
D(4): U1.12 (5Q), U7.16 (I/O5), U8.18 (O4), U10.4 (1C2), U12.7 (D4)
D(5): U1.15 (6Q), U7.17 (I/O6), U8.19 (O5), U10.12 (2C2), U12.9 (D5)
D(6): U1.16 (7Q), U7.18 (I/O7), U8.20 (O6), U10.3 (1C3), U12.10 (D6)
D(7): U1.19 (8Q), U7.19 (I/O8), U8.21 (O7), U10.13 (2C3), U12.13 (D7)
GND: C1.-, C3.2, C10.2, C11.2, C12.2, C13.2, C14.2, C15.2, C16.2, C17.2, C18.2, C19.2, C20.2, C21.2, CPU_INPUT.1, DISPLAY.2_GND, DISPLAY.4_GND, DISPLAY.6_GND, DISPLAY.8_GND, DISPLAY.10_GND, DISPLAY.12_GND, DISPLAY.14_GND, U1.10 (GND), U2.7 (GND), U3.7 (GND), U4.8 (GND), U5.7 (GND), U6.8 (GND), U7.14 (VSS), U8.16 (GND), U9.8 (VSS), U10.1 (1G), U10.8 (GND), U10.15 (2G), U11.7 (GND), U12.29 (GND), X2.3, X2.4
IDAT: U1.1 (OC), U6.6 (Y2), U11.1 (CLR)
INT_16: U11.6 (!Q), U12.16 (INT)
IOREQ: U3.1 (I), U12.20 (IORQ)
J1_03_BUSY: CPU_INPUT.3, U11.5 (Q)
J1_04_STATUS: CPU_INPUT.4, U4.9 (Q4)
J1_11: CPU_INPUT.11, R88.2, U1.3 (1D)
J1_12: CPU_INPUT.12, R8.2, U1.4 (2D)
J1_13: CPU_INPUT.13, R5.2, U1.7 (3D)
J1_14: CPU_INPUT.14, R11.2, U1.8 (4D)
J1_15: CPU_INPUT.15, R6.2, U1.13 (5D)
J1_16: CPU_INPUT.16, R7.2, U1.14 (6D)
J1_17: CPU_INPUT.17, R9.2, U1.17 (7D)
J1_18: CPU_INPUT.18, R10.2, U1.18 (8D)
J1_19: CPU_INPUT.19, R33.1, U1.11 (CLK), U11.3 (CLK)
J1_20_RESET: CPU_INPUT.20, R89_1/4W.1, U5.3 (I)
J2_CL: DISPLAY.7_CL, U3.6 (O)
J2_DCLK: DISPLAY.9_DCLK, U6.4 (Y0)
J2_DE: DISPLAY.1_DE, U4.7 (Q3)
J2_RCLK: DISPLAY.5_RCLK, U4.11 (Q6)
J2_RD: DISPLAY.3_RD, U4.10 (Q5)
J2_SD0: DISPLAY.11_SD0, U10.7 (1Y)
J2_SD1: DISPLAY.13_SD1, U10.9 (2Y)
M1: U2.2 (I1), U12.27 (M1)
MREQ: U6.15 (G), U12.19 (MREQ)
unnamed: C3.1, R18.1, U3.10 (O), U3.13 (I)
unnamed: R18.2, U3.11 (I), Y1.2
unnamed: U3.9 (I), U3.12 (O), Y1.1
unnamed: TEST.2, U4.12 (Q7)
unnamed: U3.8 (O), U11.11 (CLK)
unnamed: U9.10 (P1), U11.8 (!Q), U11.12 (D)
unnamed: R90_1/4W.1, U3.3 (I), U5.4 (O), U9.11 (RES)
unnamed: U11.9 (Q), U12.6 (CLK)
unnamed: R14.2, U12.24 (WAIT), U12.25 (BUSRQ)
unnamed: U3.5 (I), U6.5 (Y1)
unnamed: U2.5 (I1), U4.4 (Q0)
unnamed: U2.1 (I0), U3.2 (O)
unnamed: U2.3 (O), U6.1 (G)
unnamed: U2.9 (I0), U4.5 (Q1)
unnamed: U4.14 (G), U6.7 (Y3)
unnamed: U2.12 (I0), U4.6 (Q2)
unnamed: U6.10 (Y2), U8.22 (!CE)
RD: U7.22 (!OE), U8.24 (!OE), U12.21 (RD)
RESET: U3.4 (O), U4.15 (CLR), U12.26 (RESET)
TEST: R13.1, TEST.1, U11.4 (PRE)
WR: U7.27 (!WE), U12.22 (WR)
Y3: U6.9 (Y3), U7.20 (!CS1)

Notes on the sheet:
C10-C21 - Filter for ICs .1uF(100nF)/50V
DATA EAST 128 x 16 DOT MATRIX DRIVER BOARD
not installed



Board: 2 copper layers, 100.0 x 100.0 mm, 49 parts (4 on the bottom side), 79 nets.

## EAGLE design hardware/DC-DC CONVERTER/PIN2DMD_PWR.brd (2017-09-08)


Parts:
+5V, +5V1: TPSPAD1-20Y; P1-20Y
GND1: M01PTH; 1X01
GND_IN: M01PTH; 1X01
GND_OUT, GND_OUT1: M01PTH; 1X01
IN+, IN+1: TPPAD1-20; P1-20
IN-, IN-1: TPPAD1-20; P1-20
OUT+, OUT+1: TPPAD1-20; P1-20
OUT-, OUT-1: TPPAD1-20; P1-20
TP1, TP2, TP3, TP4, TP5, TP6, TP7, TP8, TP9, TP10, TP11, TP12, TP13, TP14, TP15, TP16, TP17, TP18, TP19, TP20, TP21, TP22, TP23, TP24, TP25, TP26: TPSPAD1-20Y; P1-20Y
V_IN, V_IN1: M01PTH; 1X01
V_OUT, V_OUT1: M01PTH; 1X01
X1, X2: KK-156-4
X3, X4: W237-102

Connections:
+5V: +5V.TP, OUT+.TP, TP5.TP, TP6.TP, TP7.TP, TP8.TP, TP13.TP, V_OUT.1
+5V1: +5V1.TP, OUT+1.TP, TP17.TP, TP18.TP, TP19.TP, TP20.TP, TP26.TP, V_OUT1.1
GND: GND_IN.1, GND_OUT.1, IN-.TP, OUT-.TP, TP1.TP, TP3.TP, TP4.TP, TP9.TP, TP10.TP, TP11.TP, TP12.TP, X1.2, X3.2
GND1: GND1.1, GND_OUT1.1, IN-1.TP, OUT-1.TP, TP14.TP, TP15.TP, TP16.TP, TP21.TP, TP22.TP, TP24.TP, TP25.TP, X2.2, X4.2
IN+: IN+.TP, V_IN.1, X1.3, X3.1
IN+1: IN+1.TP, V_IN1.1, X2.3, X4.1


Board: 2 copper layers, 98.6 x 99.7 mm, 48 parts (0 on the bottom side), 6 nets.

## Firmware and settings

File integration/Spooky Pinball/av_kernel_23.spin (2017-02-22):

{
PINHECK SYSTEM - Parallax Propeller Audio / DMD System Driver
2009-2015 Benjamin J Heckendorn
www.benheck.com
}
CON

  _clkmode = xtal1 + pll16x
  _xinfreq = 6_500_000     
  '_xinfreq = 5_000_000

AVversion         =              23                      'October 2015                  

'------------------------------------Propeller Cog Usage---------------------------------------Langauge---------
                                '(0) Setup / Interpreter                                        (SPIN)
                                '1 FREE COG
                                '2 FREE COG
sd0_Cog         = 3             'SD File System for SFX                                         (ML)
audioDACCog     = 4             'Machine language DAC Audio Player                              (ML)
Graphic_Cog     = 5             'Runs video, score display, etc                                 (SPIN)
Raster_Cog      = 6             'DMD shift register PWM driver                                  (ML) 
Comm_Cog        = 7             'Get commands from PIC32                                        (ML)  


eepromBus       =               $A0                     'Where the Propeller's EEPROM is on the I2C bus
eepromBase      =               $8000                   'Where free EEPROM starts (32k)

ACK      = 0                        ' I2C Acknowledge
NAK      = 1                        ' I2C No Acknowledge
Xmit     = 0                        ' I2C Direction Transmit
Recv     = 1                        ' I2C Direction Receive
BootPin  = 28                       ' I2C Boot EEPROM SCL Pin
EEPROM   = $A0                      ' I2C EEPROM Device Address

atnSpin = 24
clkSpin = 25
datSpin = 26

commBuffSize = 512                                      'Size of the command buffer (32 commands)
status_LED  =  27                                       'Where the blinky LED is. Very important!

volumeMultiplier = 10                                   'How much to reduce audio volume for each additional track playing concurrently

'Video Attribute Bits:

loopVideo       =               %1000_0000              'Should video start over after it ends?
preventRestart  =               %0100_0000              'If video called is already playing, don't restart it (just let it keep playing)
noEntryFlush    =               %0010_0000              'Do not flush graphics on video start (for instance, to have a number appear on an enqueued video)
noExitFlush     =               %0001_0000              'Do not flush graphics on video end
allowSmall      =               %0000_0001              'Can show small numbers on the video? 
allowLarge      =               %0000_0010              'Can show large numbers on the video?
allowBar        =               %0000_0100              'Can show a Progress Bar?
manualStep      =               %0000_1000              'Video loads first frame, but requires manual advancement

'graphicAtt Attribute Bits:

returnPixels    =               %0010_0000              'Before drawing this character, place the existing left and rightmost pixels in the Outbuffer data return buffer
numberStay   =                  %0001_0000              'If we see this bit on a Numbers command, we make the incoming number a Timers number
totalNumbersAllowed = 12                                'Total number of numbers allowed (includes Timer) Setting as 8 means 7 normal numbers (0 - 6) + the timer (7)

'Graphic Command Bits:

clearScreen     =               %1000_0000              'Allows the PIC32 to take command of screen drawing routines
loadScreen      =               %0100_0000



VAR     'Display buffer data, SD card read buffer data, audio buffers
 
  long audioBuffer[1280]                                '1K buffer per stereo channel
  byte bufferD[4096]                                    'Lower 2K is frame buffer, upper 2K is what is put on display 
  byte dataBlock0[512]                                  'For reading sectors off SD card
  byte font[2048]
  
  byte numberLarge[1280]                                'RAM that holds the large numerals for fast access
  byte numberMedium[704]                                'RAM that holds the medium numerals for fast access 
  byte numberSmall[120]                                 'RAM that holds the small numerals for fast access 

  long CogstackV[128]                                   'Stack for launching a video cog. Keep it high!
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

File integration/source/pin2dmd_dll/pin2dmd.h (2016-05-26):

#ifdef PIN2DMD_EXPORTS
	#define PIN2DMD_API __declspec(dllexport) 
#else
	#define PIN2DMD_API __declspec(dllimport) 
#endif

typedef struct rgb24 {
	UINT8 red;
	UINT8 green;
	UINT8 blue;
} rgb24;

//define vendor id and product id
#define MY_VID 0x0314
#define MY_PID 0xe457

//endpoints for communication
#define EP_IN 0x81
#define EP_OUT 0x01

#define width 128
#define height 32

unsigned char *OutputPacketBuffer;

extern "C"
{
PIN2DMD_API int pin2dmdInit();
PIN2DMD_API bool pin2dmdDeInit();
PIN2DMD_API void pin2dmdRenderRGB24(rgb24 *currbuffer);
PIN2DMD_API void pin2dmdRender8bit(UINT8 *currbuffer);
PIN2DMD_API void pin2dmdSet16Color(rgb24 *b);
PIN2DMD_API void pin2dmdSet4Color(rgb24 *b);
}

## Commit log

2016-05-26 New Version 2.12
    [PIN2DMD.brd, PIN2DMD.sch, ShopCart_newark.csv]
2016-06-15 New version 2.20
    - completely reworked sync routine. Now resync is lossless.
    no artifacts on resync
    - working Stern Spike input
    - working Gottlieb input
    - New colorization feature : increase colordepth of 4 color animations
    16 Colors) . Working with dynamic frames (score display etc. )
    - increased number of detection masks to 10
2016-08-01 New version V2.32
    - added realpin Capcom support
    - added realpin Gottlieb mode for early machines (1992)
    - adjusted Gottlieb modes to latest vpinmame
    - added onscreen menu (hold config/blue button during boot) for basic
    config
    - first release with wifi html interface (see flash.md)
    for basic config
    - added reset function for wifi (hold menu and press option button)
    - added support for serial port for control of additional sub devices
    and Stern SAM palette switching.
2016-08-22 removed outdated documentation and shield layout
    [PIN2DMD.brd, PIN2DMD.sch, ShopCart_newark.csv]
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2016-12-24 new firmware release 2.36
    - added support for AlvinG and Spooky Pinball
    - added support for advanced palette switching in pinmame
2016-12-24 new pin2dmd tool release 2.36
    - added advanced palette editing
    - added upload button to frontend
    - support for signal enhancer
2017-02-22 minor fix in layout
    [PIN2DMD-v3.0.brd, PIN2DMD-v3.0.sch]
2017-03-24 New Version 2.38
    - fix bitorder for DataEast and Whitestar machines
    - improved processing of fsq playback for Frame replacement and
    ColorMask
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2017-04-07 new dmddevice version with patched libusb
    searches for libusbk in the same directory dmddevice.dll is located in.
    That problem is also adressed by this microsoft patch
    https://www.microsoft.com/de-de/download/details.aspx?id=26767
2017-05-12 New Version 2.39
    - added support for pin2dmd editor V2.0 in firmware and dmddevice.dll
    - added support for v-pin export (not usable on real pins)
    - automatically playback boot.fsq from SD on startup
    (sample in pin2dmd.exe folder)
    - improved Gottlieb support
    V1 for machines from '92
    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
2017-05-25 Changed error message handling
    Display "pin2dmd not found" message only when no device attached. Skip
    message when device not accessible.
2017-06-21 New Version 2.40
    - fix bug in palette switching
    - improve dump routine on slow USB connection
2017-09-08 move V3 shield schematics and layout into subfolder
    [PIN2DMD-v3.0.brd, PIN2DMD-v3.0.sch]
2017-09-08 schematics and layout of V4 Nucleo shield
    [PIN2DMD_Nucleo144.brd, PIN2DMD_Nucleo144.sch]
2017-09-08 schematics and layout of DC-DC converter breakout board
    [PIN2DMD_PWR.brd, PIN2DMD_PWR.sch]
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2017-10-04 updated layout of Nucleo shield
    - fix missing connection from pinball input P3 to RN2
    - cosmetics in the schematics by UncleSash
    [PIN2DMD_Nucleo144.brd, PIN2DMD_Nucleo144.sch]
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2017-10-10 optimized PCB layout by UncleSash
    [PIN2DMD_Nucleo144.brd, PIN2DMD_Nucleo144.sch]
2017-10-10 Revert "optimized PCB layout by UncleSash"
    This reverts commit 649e18bdf0d6448ef66665a2f91fea89fedbe6e9.
    [PIN2DMD_Nucleo144.brd, PIN2DMD_Nucleo144.sch]
2017-10-10 updated Nucleo shield 4.02
    updated labels in schematic
    optimized layout (by UncleSash)
    [PIN2DMD_Nucleo144.brd, PIN2DMD_Nucleo144.sch]
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2017-11-23 new version 2.50
    fixed frame not displayed when using ColMask with machine types not
    supporting ColMask (early Gottlieb)
2017-12-28 added 128x16 DMD controller pcb files
    pcb design by Rappelbox, UncleSash and Lucky1
    [Data_East_128x16.brd, Data_East_128x16.sch]
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2018-01-12 new version 2.10 of XL
    - added real pinball input test to onscreen menu
    - changed handling of replacement frames.
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2018-01-12 new version 2.53
    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
2018-08-24 new version 2.58
    - set RBG as default for Nucleo shield
    - support for Nucleo based custom boards
2018-08-30 layout for EVO128x32 pcb
    [128x32-BOM.xls, 128x32.brd, 128x32.sch]
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2018-11-26 new version 2.60
    - unified codebase and version number for 192x64 and 128x32
    - reworked output code to improve speed and save memory (50%)
    - increased color depth for 192x64
    - fixed colorization and init code for Capcom
    - improved speed and fixes for DataEast 128x16 code
    - fixed minor bugs in bootloader (update through USB to update bootloader code)
    - fast palette load in dmddevice.dll
    - fixed dump for CapCom in pin2dmd.exe
    - added raw dump support for WPC, Gottlieb, Capcom and AlvinG
    - added 128x16 as device mode (with dump functionality)
    - reviewed / refactored almost 90% of the code for better portability to other platforms
    (tested with DMDMK66 / Teensy 3.6)
2018-11-27 EVO board rev 1.1 - changed size of mounting holes due to design change of chinese panel manufacturers.
    [128x32.brd]
2019-03-08 new version v3.00 - based on STM32 HAL core library - added new colorization modes (colmask layered, replace follow, replace masked)
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2019-07-31 added component list to 128x16 controller psb
    [bom.csv]
2019-07-31 - pcb layout and order information for EVO128x16 and EVO192x64 - updated layout for EVO128x32 (soldermask problem)
    [128x16.brd, 128x16.sch, 128x32.brd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]
2019-07-31 move BOM zu zip file
    [128x32-BOM.xls]
2019-07-31 add partlist for 128x16 controller board
    [bom.csv]
2019-08-01 EVO128x16 pcb layout
    [128x16.brd, 128x16.sch]
2019-08-01 optimize EVO128x32 pcb layout
    [128x32-BOM.xls, 128x32.brd, 128x32.sch]
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2019-08-01 add pcb layout and ordering information for EVO128x16 and EVO192x64
    [128x16.brd, 128x16.sch, 192x64.brd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]
2019-08-05 new version v3.01 - fix boot loop when using discovery board with no or old shield revision
2019-08-08 new version v3.02 - make old palette switch method in freezy DLL work
2019-09-05 new version v3.04 - add Inder / SPinball as devicemode and to autodetection - fix problems with some SD cards - fix activation problem from SD - fix display after boot.fsq playback - fix switch of de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
2020-01-08 - adjusted position of DMD input for 128x32 - fixed parts in BOM
    [128x16.brd, 128x16.sch, 128x32.brd]
2020-01-08 fix silkscreen
2020-01-21 new version v3.07 - fix onscreen menu buttons for Nucleo
2020-03-24 new version v3.11 - fix first frame for ColorMask layered mode - fix detection of unmasked frames in ColorMask layered mode - allow Event with same hash as colorizations - fix bug in event handling
2020-05-04 new version v3.12 - change behaviour of "Replace Masked" mode like suggested by DJRobX - don´t retrigger ColorMask layered scene if scene is already loaded - create dummy file with serial on SD if no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
2020-07-19 update EVO192x64 pcb
    [192x64.brd, 192x64.sch]
2020-07-30 add alternative layout with cheaper chinese SD-reader module (untested)
    [PIN2DMD_Nucleo144.brd, PIN2DMD_Nucleo144.sch]
2020-10-20 new version v3.17 - enable to take a frame within a lcm scene as trigger to start the lcm scene.
2020-10-25 rename DE 128x16 controller folder
    [Data_East_128x16.brd, Data_East_128x16.sch, bom.csv]
2020-10-25 DE - SEGA - STERN power adapter pcb Designed by Rene Venema
    [Connectors BOM.xlsx, Data East converter.brd, Data East converter.sch]
2020-11-30 update EVO128x32 to V1.4 - add TTL level UART TX - connect 5V pinheader to DC-DC converter input
    [128x32.brd, 128x32.sch]
2020-12-17 new version v3.19 - fix crash when loading small palettes from flash in real pin modes
2021-01-07 new version v3.20 - migration release to version 4.x - fix masked replace mode for some devicemodes - refresh flash pal storage on firmware update
2021-01-07 EVO128x16 layout - move cpu data connector to left
    [128x16.brd, 128x16.sch]
2021-01-07 new version v4.00 - implement 64color for all devicemodes - optimize/speedup create framebuffer routines for all coloring modes
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2021-01-30 minor fix of cutouts in layout
    [128x16.brd, 192x64.brd]
2021-02-03 update EVO192x64 pdf
    [192x64.brd, 192x64.sch]
2021-02-03 fix broken eagle files
    [128x32.brd, 128x32.sch]
2021-02-17 fix default devicemode
2021-02-22 reorganize hardware folders
    [Data_East_128x16.brd, Data_East_128x16.sch, PIN2DMD-v3.0.brd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]
2021-04-12 refresh gerber files
    [192x64.brd, 192x64.sch]
2021-05-03 update layout for better LED module compatibility
    [192x64.brd, 192x64.sch]
2021-06-18 add EVO256x64 pcb layout
    [256x64-BOM.xls, 256x64.brd, 256x64.sch]
2021-06-19 updated pcb layout for EVO256x64
    [EVO256x64-BOM.xls, EVO256x64.brd, EVO256x64.sch]
2021-07-01 update Data East power converter
    [Data East converter.brd, Data East converter.sch]
2021-07-12 new version v4.13 - fix first frame issue with sequence modes
2021-07-14 new version v4.15 - fix first frame no displayed in sequence modes
2021-07-23 fix BOM of 192x64
2021-07-28 new version v4.17 - fix support for custom boards
2021-08-05 new version v4.18 - fix boot for STM32F407 on EVO board
2021-09-01 new version v4.19 - fix single frame colormask issue
2021-09-02 new version v4.20 - fix colormask timer issue
2022-02-18 new version v4.32 - add support for single device real pin2dmd editor export
2022-02-25 new version V4.33 - fix issue with single real pin export and 64 color palettes - add 2bit 128x32 on XL mode
2022-04-16 new version V4.36 - fix scale2x borders on pin2dmdHD DmdDevice.dll - add support for .pac format (single file distribution for VPins) - support DmdExt.dll (freezy) for display on screen or other disp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
2022-04-23 new version V4.37 - fix issue with DE128x16 - fix init of new chipset panels on MK66
    changes to mddevice.dll
    - use dmdext.ini instead of dmddevice.ini to allow second display with dmdscreen.dll driver and own dmddevice.ini settings.
    Makes Gottlieb Strikes'n Spares work with latest vpinmame.dll
2022-06-19 update dmddevice.dll - use dmddevice.ini instead of dmdext.ini - forward device specific calls to dmdext
2022-08-01 update dmddevice.dll / pin2color.dll - add colorization support for alphanumeric tables - add dump function for alphanumeric frames to alphadump folder
2022-08-31 new version V4.41 - fix update on non EVO HD pcbs - increase cpu clock startup timeout
2022-12-29 new version V4.45 - add support for new coloring mode ColorMask Loop - fix colorization issue on XL boards - fix colorization issue on MK66 boards
2022-12-30 updated BOM for SysXDMD
    [SYSXDMD-BOM.xls]
2023-01-19 new version v4.47 - fix rare issue with EVO boards needing reset to start after poweron. Full install of firmware needed with DFU or BIN file.
2023-01-21 new version V4.48 - final fix of rare issue with EVO boards needing reset to start after poweron. Full install of firmware needed with DFU or BIN file. - fix REPLACE_NO_RETRIGGER coloring mode replay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
2023-07-20 added more INPUT to connectors
    [128x32.brd, 128x32.sch]
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2024-10-14 new version v4.55 for pin2dmd HD - fix display issue for SM16380SH chipset on some brightness levels - improve brightness range for SM16380SH PWM chipset
2025-09-07 restore WaveShare SD layout for Nucleo shield
    [PIN2DMD_Nucleo144.brd, PIN2DMD_Nucleo144.sch]
2025-12-14 updated pcb layout for EVO128x32 and EVO256x64
    [128x32.brd, 128x32.sch, EVO256x64-BOM.xls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]
2026-01-15 remove duplicate BOM
    [EVO256x64-BOM.xls]
2026-03-25 new version V5.02 - prepare PIN2DMD XL firmware for MMI
    [128x32.brd]
2026-03-28 -add MMI interface to EVO192x64 pcb
    [192x64.brd, 192x64.sch]
2026-03-30 add pcb layout for SysXDMD and Nucleo MMI adapter
    [Nucleo_MMI.brd, Nucleo_MMI.sch, sysXdmd.brd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]
2026-04-10 move ESP32 firmware to deprecated replaced by Raspberry PI (PIN2DMD MMI)
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

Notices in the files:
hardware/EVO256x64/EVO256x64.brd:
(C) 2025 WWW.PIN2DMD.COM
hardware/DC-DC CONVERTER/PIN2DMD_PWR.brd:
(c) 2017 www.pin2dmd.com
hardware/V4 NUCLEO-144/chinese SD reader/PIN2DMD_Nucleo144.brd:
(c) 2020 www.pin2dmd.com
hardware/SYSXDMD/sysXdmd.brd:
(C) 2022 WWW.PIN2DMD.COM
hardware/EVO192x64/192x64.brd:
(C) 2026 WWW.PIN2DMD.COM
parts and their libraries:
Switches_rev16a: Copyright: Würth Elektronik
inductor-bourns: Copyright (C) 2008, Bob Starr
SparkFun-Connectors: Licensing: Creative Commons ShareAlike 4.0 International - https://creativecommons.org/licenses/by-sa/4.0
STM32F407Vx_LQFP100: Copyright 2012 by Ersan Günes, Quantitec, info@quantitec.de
